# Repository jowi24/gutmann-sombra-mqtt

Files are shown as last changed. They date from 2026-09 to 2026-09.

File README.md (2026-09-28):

🇬🇧 **English** · 🇩🇪 [Deutsch](README.de.md)

# gutmann-sombra-mqtt

An ESP8266 board that connects a Gutmann Sombra range hood (cooker hood) to
home automation over Wi-Fi and MQTT, with Home Assistant auto-discovery.
The board sits in the cable between the hood electronics and the front
panel. It reads which front-panel LEDs are lit and can simulate key presses.
The original front panel keeps working as before.

- **Hardware:** KiCad 10 PCB, 80 × 55 mm, through-hole except the ESP-12E
  module, fabrication files included
- **Firmware:** PlatformIO / Arduino, MQTT with Home Assistant discovery,
  OTA updates, Wi-Fi setup portal

## Documentation

| Document | Contents |
|---|---|
| [How the circuit works](docs/CIRCUIT.md) | Beginner-friendly explanation of the hardware: the hood's key matrix, level shifters, power supply, firmware timing, troubleshooting |
| [Hardware design notes](kicad/DESIGN.md) | Part values, sourcing, layout decisions, bring-up findings |
| [Fabrication files](kicad/fab/FAB.md) | Gerber/drill files and PCB order parameters |
| [Operation, diagnostics and flashing](docs/OPERATIONS.md) | Setup, OTA and serial flashing, diagnostics |
| [Changelog](CHANGELOG.md) | Firmware versions |

All documents are also available in German (`*.de.md`).

## Status

- **Hardware:** PCB rev. 0.3, see the [schematic](kicad/schematic.pdf) and
  the [layout](kicad/board-layout.pdf). The fabricated rev. 0.2 boards work
  after a small modification at U3 (diodes + pull-downs, see
  [DESIGN.md](kicad/DESIGN.md)).
- **Firmware:** 0.0.10, PlatformIO, source in [`src/main.cpp`](src/main.cpp).

## Project layout

```
src/main.cpp          firmware
platformio.ini        build configuration (serial and OTA flashing)
docs/                 operation and circuit description
kicad/                schematic, PCB, custom footprint and 3D model
kicad/fab/            fabrication files
fritzing/             2017 perfboard version (reference only)
```

## Building and flashing the firmware

```bash
pio run -e nodemcuv2-ota -t upload
```

This flashes over Wi-Fi (OTA) to `hood-control.local`. For the first flash
or for recovery, use `-e nodemcuv2` via a USB-serial adapter on J2, with
jumper J5 set to FLASH. Details in [OPERATIONS.md](docs/OPERATIONS.md).

## MQTT

All topics live under the configured prefix (default `home/kitchen/hood`).
Home Assistant picks the device up automatically via MQTT discovery
(`homeassistant/…`).

| Topic | Values | Meaning |
|---|---|---|
| `ventilation/state`, `ventilation/set` | `0`–`4` | fan level, `0` = off |
| `light/state`, `light/set` | `true` / `false` | light |
| `timer/state`, `timer/set` | `true` / `false` | run-on timer |
| `maintenance/state` | `true` / `false` | "clean filter" indicator |
| `maintenance/set` | any | resets the filter indicator (6 s key press, only while it is on) |

Diagnostics:

- `diagnostics`: combined JSON status
- `$wifi_rssi`, `$uptime`, `$reset_reason`, `$firmware`, `$ip`, `$last_error`
- `events`: connection events buffered since the last MQTT contact
- `$online`: availability via MQTT last will

## Network

If the stored Wi-Fi network cannot be reached for 20 seconds, the firmware
starts the password-protected hotspot `HoodControl-Setup`. The setup portal
is at `http://192.168.4.1`. The device keeps trying the stored network in
parallel and shuts the hotspot down once the connection is stable.

The blue LED on the ESP module shows the state: fast blinking = connecting
to Wi-Fi, medium = connecting to MQTT, slow = hotspot active, a short flash
every 3 s = all good.

## Background

Blog post about the original 2017 perfboard version (German):
[Do-It-Yourself IoT Modul für die Dunstabzugshaube](https://joachim-wilke.de/blog/2017/12/27/do-it-yourself-iot-modul-fur-die-dunstabzugshaube/)

## License

Copyright (c) 2017–2026 Joachim Wilke. The firmware is open source (MIT). Hardware
and documentation are free for **non-commercial** use only; commercial use (e.g. selling boards, kits or products based on this project)
requires the author's permission.

- **Firmware** (`src/`, `platformio.ini`): [MIT](LICENSE)
- **Hardware and documentation** (`kicad/`, `fritzing/`, `docs/`, Markdown files):
  [CC BY-NC-SA 4.0](LICENSE-HARDWARE-DOCS)

Third-party libraries used by the firmware keep their own licenses.

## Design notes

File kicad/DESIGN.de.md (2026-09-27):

🇬🇧 [English](DESIGN.md) · 🇩🇪 **Deutsch**

# Hood-Control PCB – Redesign

Diese Doku beschreibt die Schematic in `hood-control.kicad_pro` /
`hood-control.kicad_sch`. Alle Werte sind aus der Fehlersuche an der
Lochraster-Version abgeleitet (siehe [CHANGELOG.de.md](../CHANGELOG.de.md) / Debugging-Session
vom 2026-09-03) sowie aus dem Blogartikel von 2017
("Do-It-Yourself IoT Modul für die Dunstabzugshaube").

Eine verständliche Erklärung, *wie* die Schaltung funktioniert, steht in
[`docs/CIRCUIT.de.md`](../docs/CIRCUIT.de.md).

**Bauweise: THT (bedrahtet).** Alle Widerstände/Kondensatoren bedrahtet,
alle ICs in DIP-Sockeln, Stecker als Pfostenleisten 2,54 mm, Taster als
6-mm-THT-Kurzhubtaster. Einziges SMD-Teil ist das ESP-12E-Modul selbst.
Der Spannungswandler ist **kein diskreter Schaltregler**, sondern ein
fertiges TPS63802-Buck-Boost-Modul (U4, 8 Bohrungen), flach aufgelötet oder auf
Stiftleisten gesteckt.

Blattformat der Schematic: **A5** (210 × 148 mm).

> **Namenskollision beachten:** Die Haubenelektronik benennt ihre eigenen
> Matrixleitungen ebenfalls J1–J8 (J1–J4 = Scan-Eingänge, J5–J6 = Tasten-
> Ausgänge, J7–J8 = LED-Ausgänge). Die Steckverbinder *dieser Platine*
> heißen ebenfalls J1–J6. Wo Verwechslungsgefahr besteht, ist im Folgenden
> "Haube-J5" bzw. "Board-J5" ausgeschrieben.

## Stückliste (BOM)

| Ref | Bauteil | Wert/Typ | Footprint | Zweck |
|---|---|---|---|---|
| U1 | ESP-12E/F | ESP8266 Modul (SMD) | `RF_Module:ESP-12E` | Microcontroller |
| U2 | CD4050BE / HEF4050BP / 74HC4050N | Hex-Buffer, **16-pol. DIP** | `Package_DIP:DIP-16_W7.62mm_Socket` | Pegelwandlung 5V→3,3V (Lesen: Scan-Bus, Haube-J7/J8) |
| U3 | **74HCT08** (z.B. SN74HCT08N) | Quad-AND, 14-pol. DIP | `Package_DIP:DIP-14_W7.62mm_Socket` | Pegelwandlung 3,3V→5V (Treiben: Haube-J5/J6) |
| U4 | **TPS63802-Buck-Boost-Modul** (eBay, PCB-Tronic24) | 1,5–5,5 V → 3,3 V, 2,7 A | `hood-control:TPS63802_Module_25.8x13.0mm` (projekteigene Bibliothek) | Stromversorgung (Ersatz für den 2017er Mini-Wandler) |
| R2 | 10 kΩ | 0207 bedrahtet | `Resistor_THT:R_Axial_DIN0207_L6.3mm_D2.5mm_P10.16mm_Horizontal` | Pull-up GPIO0 → 3,3V, über Board-J5 Pin 1 |
| R3 | 10 kΩ | 0207 bedrahtet | s.o. | Pull-down GPIO15 → GND |
| R4 | 10 kΩ | 0207 bedrahtet | s.o. | Pull-up CH_PD/EN → 3,3V |
| R5 | 2,4 kΩ | 0207 bedrahtet | s.o. | Pull-down auf den Scan-Bus (empirisch, siehe Blogartikel 2017) |
| R6 | 10 kΩ | 0207 bedrahtet | s.o. | Pull-up RST → 3,3V |
| R7, R8 | 10 kΩ | 0207 bedrahtet, stehend | `Resistor_THT:R_Axial_DIN0207_L6.3mm_D2.5mm_P2.54mm_Vertical` | Pull-down der U3-Eingänge (GPIO12/14), ab Rev. 0.3 |
| C1 | 470 µF / 10 V | Elko radial, D8/RM3,5 | `Capacitor_THT:CP_Radial_D8.0mm_P3.50mm` | Stützelko auf `VCC` nah am ESP – überbrückt die Regelzeit des Buck-Boost-Moduls |
| C8 | 1000 µF / 10 V | Elko radial, D10/RM5, 12,5 mm hoch (Reichelt `RD1A108M1012M128`) | `Capacitor_THT:CP_Radial_D10.0mm_P5.00mm` | Bulk-Kapazität auf `5V_IN` – puffert die strombegrenzte Haubenversorgung |
| C3–C6 | 100 nF | Keramik-Scheibe, RM5 | `Capacitor_THT:C_Disc_D5.0mm_W2.5mm_P5.00mm` | Abblockung: C3=U1(VCC), C4=U2(VCC 3,3V), C5=U3(5V_IN), C6=U4-Ausgang |
| C7 | 100 nF | Keramik-Scheibe, RM5 | `Capacitor_THT:C_Disc_D5.0mm_W2.5mm_P5.00mm` | RST-Kopplung FTDI-DTR → RST (Auto-Reset) |
| D1, D2 | 1N4148 | DO-35 | `Diode_THT:D_DO-35_SOD27_P7.62mm_Horizontal` | Entkopplung der LED-Leseleitungen Richtung Frontpanel |
| D3, D4 | 1N4148 | DO-35, stehend | `Diode_THT:D_DO-35_SOD27_P2.54mm_Vertical_AnodeUp` | Ausgangsdioden U3 → Tastenleitungen, ab Rev. 0.3 |
| SW1 | Taster 6 mm THT | – | `Button_Switch_THT:SW_PUSH_6mm` | Reset (RST → GND) |
| SW2 | Taster 6 mm THT | – | `Button_Switch_THT:SW_PUSH_6mm` | Flash-Mode (GPIO0 → GND) |
| J1 | Pfostenleiste 1×8, 2,54 mm | "Hoodcontrol" | `Connector_PinHeader_2.54mm:PinHeader_1x08_P2.54mm_Vertical` | Anschluss Haubenelektronik |
| J2 | Pfostenleiste 1×6, 2,54 mm | FTDI-Header | `Connector_PinHeader_2.54mm:PinHeader_1x06_P2.54mm_Vertical` | DTR, RXI, TXO, VCC, n.c., GND |
| J3 | Pfostenleiste 1×8, 2,54 mm | "Frontpanel" | `Connector_PinHeader_2.54mm:PinHeader_1x08_P2.54mm_Vertical` | Anschluss Frontpanel |
| J4 | Pfostenleiste 1×2, 2,54 mm | "Reset" | `Connector_PinHeader_2.54mm:PinHeader_1x02_P2.54mm_Vertical` | externer Reset-Taster (RST → GND) |
| J5 | Pfostenleiste 1×3, 2,54 mm | "Flash/Run" | `Connector_PinHeader_2.54mm:PinHeader_1x03_P2.54mm_Vertical` | Jumper: 1–2 = Run, 2–3 = Flash |
| J6 | Pfostenleiste 1×2, 2,54 mm | "PWR_IN" | `Connector_PinHeader_2.54mm:PinHeader_1x02_P2.54mm_Vertical` | Versorgung + Masse vom Service-Anschluss der Haube |

> **Achtung bei alten Notizen:** In CHANGELOG und Blogartikel ist mit "dem großen
> Elko" immer C1 gemeint. Seit der Umverteilung der Pufferung ist **C8** der große
> Bulk-Elko (seit 2026-09-07 **1000 µF** auf `5V_IN`) und **C1** der kleinere
> Stützelko (470 µF auf `VCC`).
>
> Die Nummerierung hat Lücken (kein C2, kein R1). C2 war der alte 4,7-µF-Elko
> der RST-Kopplung und wurde durch C7 ersetzt; der 2,5-kΩ-Pull-down heißt in
> der Schematic R5, nicht R1. Ein Re-Annotate würde nur neue Abweichungen
> zwischen Doku und Schematic erzeugen und unterbleibt bewusst.

### U4 – Spannungswandler (entschieden 2026-09-07)

Bestückt wird ein **TPS63802-Buck-Boost-Modul** (eBay, Händler PCB-Tronic24,
4,79 €).

| | |
|---|---|
| IC | TPS63802 (Texas Instruments) |
| Eingang | **1,5 – 5,5 V** (Anlauf ab 1,8 V) |
| Ausgang | 3,3 / 4,2 / 5 V per Lötbrücke, **2,7 A** bei 5 V → 3,3 V |
| Maße | **25,8 × 13,0** × 3,5 mm (nachgemessen 2026-09-11) |
| Anschlüsse | vier Eckkontakte mit je 2 Bohrungen im RM 2,54: VIN links oben, VOUT rechts oben, GND links und rechts unten |
| Eigene Beschaltung | 100 µF/16 V Eingangskondensator und Betriebs-LED bereits an Bord |

**Warum Buck-Boost und nicht Buck.** Die Haube liefert 4,9 V im Leerlauf. Jeder
gängige Buck braucht mindestens 4,5 – 6 V und fällt darunter aus der Regelung –
das ist der Brownout-Boot-Loop der Lochraster-Version. Ein Buck-Boost ab 1,5 V
hat diese Kante nicht: sackt der Eingang unter 3,3 V, regelt er einfach weiter.

**Was bei Reichelt geprüft wurde und ausscheidet** (Stand 2026-09-07):

| Artikel-Nr. | Vin min | Preis | |
|---|---|---|---|
| `TSRN 1-2433` | 4,6 V | 14,10 € | 0,3 V Reserve, dreifacher Preis |
| `TSR 1-2433` | 4,75 V | 6,85 € | zu knapp |
| `R-78E33-05` | 6 V | 3,55 € | zu hoch |
| `TSR 1-2433E` | 6 V | 3,99 € | zu hoch, lieferbar erst ab 2.11.2026 |

Auch die gesamte OKI-78SR-Familie scheidet aus (3,3-V-Variante 7–36 V).

> **Achtung beim Einbau:** Das Modul kommt **ab Werk auf 4,2 V** eingestellt.
> Der ESP8266 verträgt absolut maximal 3,6 V. Also erst die Lötbrücke auf
> **3V3** umsetzen, dann das Modul allein an 4,9 V hängen, den Ausgang messen –
> und erst danach einbauen.

#### Footprint (gezeichnet 2026-09-11)

Das Modul lag vor und wurde mit dem Messschieber vermessen. Die Fotomessung
lag quer richtig (Bohrungen bei ±2,54 und ±5,08 mm von der Mittellinie), beim
Reihenabstand daneben: es sind **22,86 mm = 9 × 2,54**, nicht ~23,5 mm. Damit
liegt das ganze Lochbild auf dem 2,54-Raster.

| | |
|---|---|
| Datei | `kicad/hood-control.pretty/TPS63802_Module_25.8x13.0mm.kicad_mod` |
| Bibliothek | `hood-control` (`fp-lib-table` im Projekt, `${KIPRJMOD}`) |
| Körper | 25,8 × 13,0 mm auf `F.SilkS`/`F.Fab`, Courtyard +0,25 mm |
| Bohrbild | x = ±11,43 mm, y = ±2,54 und ±5,08 mm → 8 Bohrungen |
| Pads | 1,7 mm rund, Bohrung 1,0 mm; Pad 1 rechteckig als Pin-1-Marke |
| Pin-Nummern | 1 = VIN, 2 = GND (4 ×), 3 = VOUT – passend zu den Pins des Symbols `Converter_DCDC:OKI-78SR-12_1.0-W36-C` |
| 3D-Modell | `kicad/3dmodels/TPS63802_Module_25.8x13.0mm.step` (erzeugt von `create_tps63802_module.py` in FreeCAD) |

Die vier Kontakte haben je zwei Bohrungen, die auf dem Modul selbst verbunden
sind. Im Footprint tragen sie deshalb dieselbe Pad-Nummer, und die Option
`duplicate_pad_numbers_are_jumpers` steht auf `yes`: KiCad weiß damit, dass
die Verbindung im Bauteil steckt und verlangt sie nicht auf der Platine.
Trotzdem sollten beim Routen **beide** Bohrungen eines Kontakts angebunden
werden – bei 2,7 A ist das kein Luxus.

Die ursprünglich geplante zusätzliche 2,54-Reihe VIN/GND/VOUT neben dem Modul
ist entfallen: das Modul liegt flach auf der Platine und deckt seinen Platz
vollständig ab, und zwischen C6 und TP1 bleibt neben dem Körper nicht einmal
ein Millimeter frei. Als Messpunkte dienen TP3 (5V) und TP4 (3V3).

Auf dem Bestückungsdruck steht innerhalb des Umrisses **„Loetbruecke auf
3V3!"** – die Warnung von oben als Aufdruck, sichtbar solange das Modul noch
nicht sitzt.

### Hinweis zu U3 (74HCT08)

In den installierten KiCad-Bibliotheken existiert kein eigenes 74HCT08-Symbol.
Verwendet wird deshalb das Symbol `74xx:74LS08` (**identische Pinbelegung**),
das Value-Feld ist aber auf `74HCT08` gesetzt, damit BOM und Bestückungsdruck
stimmen. **Bestückt werden muss ein HCT-Typ** – nur der HCT-Eingangspegel
(V_IH ≈ 2,0 V) lässt sich sicher aus 3,3 V ansteuern.

## Beschaffung

### Bezugsquellen

| Was | Wo |
|---|---|
| U4, TPS63802-Buck-Boost-Modul | eBay, Händler **PCB-Tronic24** (Cuxhaven), Artikel-Nr. 376238468668 – <https://www.ebay.de/itm/376238468668> – 4,79 € (ab 4 Stück 4,31 €) |
| alle übrigen Bauteile | reichelt.de, Artikelnummern unten |

Das TPS63802 gibt es auch bei AliExpress (diymore, 10,4 × 7,9 mm, 2,59 €), dort
kommen aber ~3 € Einfuhrgebühr je Artikel dazu und die Lieferzeit liegt bei
~10 Tagen. Das eBay-Angebot ist damit günstiger, schneller und hat Rückgaberecht.

### Reichelt-Artikelnummern

| Ref | Stk | Artikel-Nr. | Beschreibung |
|---|---|---|---|
| C3–C7 | 5 | `X7R-5 100N` | Vielschicht-Kerko 100 nF, 50/100 V, X7R ±10 %, RM 5,0 |
| C1 | 1 | `WL1C477M0811M` | Elko 470 µF/16 V, 105 °C, Low ESR, RM 3,5, 8 × 11,5 mm |
| C8 | 1 | `RD1A108M1012M128` | Elko 1000 µF/**10 V**, 105 °C, RM 5, D10 × **12,5 mm** |
| R2, R3, R4, R6 | 4 | `METALL 10,0K` | 10,0 kΩ, 0207, 0,6 W, 1 % |
| R5 | 1 | `METALL 2,40K` | 2,40 kΩ, 0207, 0,6 W, 1 % |
| D1, D2 | 2 | `1N 4148` | Schalt-Diode 100 V / 150 mA, DO-35 |
| SW1, SW2 | 2 | `DIP DTS-61K` | Kurzhubtaster 6 × 6 × 4,3 mm, Print |
| U2 | 1 | `CD 4050BE TEX` | CMOS Hex Non-Inverting Buffer, 3–18 V, DIP-16 |
| U3 | 1 | `74HCT 08` | AND-Gate, 4-fach, 4,5–5,5 V, DIP-14 |
| U2 (Fassung) | 1 | `GS 16` | IC-Sockel 16-polig, RM 7,62 |
| U3 (Fassung) | 1 | `GS 14` | IC-Sockel 14-polig, RM 7,62 |
| J2, J4, J5 | 1 | `ECON SL40G1` | Stiftleiste 1 × 40, gerade, 2,54 mm (11 Pins gebraucht) |
| J5 | 1 | `JUMPER 2,54 SW` | Kurzschlussbrücke RM 2,54 |
| Werkzeug | 1 | `ANMAS MG81000N` | Kopfbandlupe mit LED, 5 Linsen |

Seit Rev. 0.3 kommen D3/D4 (1N4148) und R7/R8 (10 kΩ) hinzu – die
Reserveteile der Bestellung unten decken sie ab.

**J1, J3 und J6 stehen bewusst nicht in der Liste** – die werden direkt
verdrahtet, dafür braucht es nur Litze (siehe „Platzierung").

Ein paar Hinweise zur Auswahl, damit sie nicht wieder verlorengeht:

* **`X7R-5 100N`, nicht `KERKO 100N`.** Letzterer ist zwar einen Cent billiger,
  aber Y5V mit −20/+80 % – die Kapazität bricht mit Temperatur und Spannung weg.
* **C8 in 10 V, nicht 16 V.** Alle 1000-µF-Typen mit 16 V bauen bei Reichelt
  mindestens 16 mm hoch und reißen damit das 14-mm-Limit. Die 10-V-Variante gibt
  es in D10 × 12,5 mm, und 10 V auf einer 4,9-V-Schiene ist doppelte Reserve.
* **R5 mit 2,40 kΩ.** Bis 2026-09-07 stand im Schaltplan 2,5 kΩ – kein Normwert,
  die E24-Reihe hat 2,4 k und 2,7 k. Für einen Pull-down auf dem Scan-Bus ist der
  Wert unkritisch (er stammt empirisch aus dem Blogartikel von 2017). Schaltplan
  und Board sind auf **2,4 kΩ** nachgezogen.
* **M2-Schrauben führt Reichelt nicht** – die Suche liefert nur M.2-SSD-Zubehör.

### Bestellt am 2026-09-07

| Artikel-Nr. | Stk | Anmerkung |
|---|---|---|
| `X7R-5 100N` | 10 | 5 gebraucht |
| `WL1C477M0811M` | 2 | 1 gebraucht |
| `RD1A108M1012M128` | 4 | 1 gebraucht |
| `METALL 10,0K` | 10 | 4 gebraucht |
| `METALL 2,40K` | 10 | 1 gebraucht |
| `1N 4148` | 5 | 2 gebraucht |
| `DIP DTS-61K` | 2 | 2 gebraucht, **kein Ersatz** |
| `GS 16` | 2 | 1 gebraucht |
| `GS 14` | 2 | 1 gebraucht |
| `CD 4050BE TEX` | 1 | Reserve, U2 ist vorhanden |
| `74HCT 08` | 1 | Reserve, U3 ist vorhanden |
| `ANMAS MG81000N` | 1 | Werkzeug |
| TPS63802-Modul (eBay) | 1 | |

Nicht mitbestellt, weil **vorhanden**: Stiftleiste 2,54 mm (für J2, J4, J5),
Kurzschlussbrücke für J5 und die vier M2-Schrauben. Die Bestellung ist damit
vollständig – es fehlt nichts mehr.

## GPIO-Zuordnung (aus src/main.cpp)

| GPIO | Funktion | Über welchen Levelshifter |
|---|---|---|
| GPIO13 | Scan-Eingang der Haube (Interrupt, RISING) | U2 (4050), Gatter C (Pin 7 → 6) |
| GPIO5  | LED-Status lesen (J1/1), Firmware `ledPin2` | U2 (4050), Gatter B (Pin 5 → 4) |
| GPIO4  | LED-Status lesen (J1/2), Firmware `ledPin1` | U2 (4050), Gatter A (Pin 3 → 2) |
| GPIO12 | Tastenemulation (J1/3), Firmware `buttonPin2` | U3 (HCT08), Gatter A (Pin 1+2 → 3) → D3 |
| GPIO14 | Tastenemulation (J1/4), Firmware `buttonPin1` | U3 (HCT08), Gatter B (Pin 4+5 → 6) → D4 |

| GPIO2  | Onboard-Status-LED (active LOW) | – (nur intern im ESP-12-Modul, No-Connect) |
| GPIO0  | Flash-Taster / WLAN-Config-Reset beim Boot | – (lokal, SW2 + R2 über Board-J5) |
| CH_PD  | Enable, muss beim Boot HIGH sein | – (lokal, R4) |
| GPIO15 | Boot-Strapping, muss beim Boot LOW sein | – (lokal, R3) |
| GPIO16 | unbenutzt (kein Deep-Sleep-Wakeup vorgesehen) | – |
| GPIO9/GPIO10 | **nicht verwenden** – bei ESP-12 intern für Flash-Zugriff (QIO) reserviert | – |

> **Kanalzuordnung (Inbetriebnahme 2026-09-24):** Sowohl die beiden
> LED-Kanäle als auch die beiden Tastenkanäle kommen gegenüber der
> Lochraster-Firmware vertauscht an – Lüfter 1 wurde als „Timer“ erkannt,
> „Licht an“ schaltete Stufe 2. Korrigiert in der Firmware durch Tausch von
> `ledPin1/2` und `buttonPin1/2`; die Hardware ist unverändert.

## Stromversorgung und Masse

Beide kommen **nicht** über das 8-polige Steuerkabel, sondern über den
separaten Service-Anschluss der Haubenelektronik (im Blogartikel Markierung
3 = Masse, 4 = Versorgung), abgegriffen mit einem gekürzten ISA-Bus-Slot:

* **ca. 4,8 V, belastbar mit ca. 500 mA** (experimentell mit Belastungs-
  widerstand bestimmt)
* Das RJ45-Kabel zwischen Haube und Frontpanel führt **keine Referenzmasse**.
  Für das Frontpanel allein ist das nicht nötig, für Messung und aktive
  Ansteuerung schon. Das Gehäuse als Bezugsmasse funktioniert nicht.

Daraus folgt für J1/J3: **dort liegen weder 5V_IN noch GND** – das ist
korrekt so und kein Versehen.

### Versorgungsnetze

* `5V_IN` → J6/1, U4/VIN, U3/VCC (74HCT08 läuft auf 5 V), C5, C8
* `VCC` (3,3 V) → U4/VOUT, U1, U2/VDD, R2, R4, R6, J2/4, C1, C3, C4, C6
* `GND` → J6/2, gemeinsame Masse
* Alle drei Netze tragen je ein `PWR_FLAG` (`#FLG01` auf GND, `#FLG02` auf
  5V_IN); VCC wird vom `power_out`-Pin des Wandlermoduls getrieben.

### Dimensionierung der Pufferung

Beim WiFi-Senden zieht der ESP kurzzeitig ~350 mA aus 3,3 V, was über den
Wandler ~270 mA aus 4,9 V bedeutet. Die Quelle liefert 500 mA – **der Strom
war also nie der Engpass.** Der Engpass war die *Untergrenze*: sackt die
Eingangsspannung unter die minimale Eingangsspannung eines Buck-Moduls
(4,5 – 6 V je nach Typ), fällt es aus der Regelung. Das ist der
Brownout-Boot-Loop aus der Lochraster-Version.

**Mit dem TPS63802 (1,5 – 5,5 V) gibt es diese Kante nicht mehr**, und die
Pufferung durfte deshalb am 2026-09-07 von 3300 µF auf **1000 µF** schrumpfen.
Der Kondensator überbrückt jetzt nur noch die Regelzeit der Haubenversorgung,
nicht mehr ein Dropout-Risiko. Nebeneffekt: C8 steht wieder aufrecht (12,5 mm
statt 35 mm liegend) und der 13,5 × 39 mm große Streifen im Layout ist frei.

Deshalb ist die Pufferung auf beide Seiten verteilt (entschieden 2026-09-06):

| Netz | Kondensatoren |
|---|---|
| `5V_IN` | C5 (100 nF) + **C8, 1000 µF/10 V** – puffert die 500-mA-Quelle |
| `VCC` | C3/C4/C6 (100 nF) + **C1, 470 µF/10 V** – überbrückt die ~100 µs Regelzeit |

Die große Kapazität gehört bewusst **nicht** auf den Ausgang: dort reichen
330–470 µF, und sehr große Werte können beim Einschalten die Strombegrenzung
des Buck-Moduls auslösen.

## Reset- und Flash-Beschaltung

| Netz | Bauteile |
|---|---|
| `/RST` | U1/1, R6 (Pull-up), C7 (Kopplung von FTDI-DTR), SW1, J4 |
| `Net-(U1-EN)` | U1/3, R4 (eigener Pull-up) |
| `/GPIO0` | U1/18, SW2, Board-J5 Pin 2 |
| `/FTDI_DTR` | J2/1, C7 |

**EN und RST haben bewusst getrennte Pull-ups.** Ein gemeinsamer Widerstand
würde beide Pins zu einem Netz verschmelzen: SW1 und J4 würden dann den Chip
abschalten statt zurückzusetzen, und ein späteres RC-Glied auf EN würde über
den kapazitiven Teiler mit C7 den Auto-Reset unbrauchbar machen.

### Auto-Reset über J2

esptool fährt beim Verbinden die Sequenz `DTR=0/RTS=1 → 100 ms → DTR=1/RTS=0`.
J2 führt nur **DTR** heraus (Pin 5 ist beim verwendeten FTDI-Adapter CTS, ein
Eingang des Adapters, und kann nichts treiben). Damit gilt:

* **Auto-Reset funktioniert** – die DTR-Flanke wird über C7 auf RST gekoppelt.
* **Auto-Flash funktioniert nicht** – GPIO0 wird nicht ferngesteuert.
* Nach dem Flashen bleibt der ESP im Bootloader, weil esptools `hard_reset`
  ausschließlich RTS schaltet. SW1 drücken (oder auf die DTR-Flanke beim
  Schließen des Ports hoffen).

Voller Auto-Flash würde einen Adapter mit RTS **und** das kreuzgekoppelte
NPN-Paar der NodeMCU-Schaltung erfordern. Bewusst nicht umgesetzt: seriell
geflasht wird nur beim Erstflash und zur Rettung, im Alltag läuft OTA
(`[env:nodemcuv2-ota]`).

### Jumper Board-J5 (Flash/Run)

| Stellung | Wirkung |
|---|---|
| **1–2 (Normalbetrieb)** | R2 zieht GPIO0 auf 3,3 V – der ESP bootet die Firmware |
| 2–3 | GPIO0 fest auf GND – der ESP bootet in den Flash-Mode |

Der Jumper steht im Normalbetrieb auf **1–2**. Der Pull-up R2 wirkt dadurch
nur bei gestecktem Jumper; ohne Jumper floatet GPIO0 und der Boot ist nicht
zuverlässig. Das ist bewusst so gewählt (ein Bauteil statt zwei, Flash-Mode
ohne Tasterakrobatik) – der Jumper muss dafür immer stecken.

## Unbenutzte Gatter (wichtig!)

CMOS- und HCT-Eingänge dürfen **nicht floaten** (Oszillation, Querstrom,
Störungen). Deshalb:

* U2 (4050): die drei unbenutzten Buffer D/E/F – **Eingänge (Pin 9, 11, 14)
  fest auf GND**, Ausgänge (Pin 10, 12, 15) offen mit No-Connect-Flag.
* U3 (74HCT08): die beiden unbenutzten Gatter C/D – **beide Eingänge je Gatter
  (Pin 9+10 bzw. 12+13) fest auf GND**, Ausgänge (Pin 8, 11) offen mit No-Connect.

## Steckerbelegung J1 / J3 (je 8-polig)

Im Original wurde ein altes Netzwerkkabel verwendet. Aderfarben nach **T568B**.
Die Platine klinkt sich in die vorhandene Verbindung Haube ↔ Frontpanel ein.

| Pin | Netz | J1 (Haube) | J3 (Frontpanel) | T568B |
|---|---|---|---|---|
| 1 | `LED_CH_2` | LED-Status Haube-J7 → U2/5 → GPIO5 | über D1 (Anode) auf dasselbe Netz | orange-weiß |
| 2 | `LED_CH_1` | LED-Status Haube-J8 → U2/3 → GPIO4 | über D2 (Anode) auf dasselbe Netz | orange |
| 3 | `BTN_CH_1` | Tastenemulation, von U3/3 über D3 getrieben | durchverbunden | grün-weiß |
| 4 | `BTN_CH_2` | Tastenemulation, von U3/6 über D4 getrieben | durchverbunden | blau |
| 5 | – | ↔ J3/5 | ↔ J1/5 | blau-weiß |
| 6 | – | ↔ J3/6 | ↔ J1/6 | grün |
| 7 | – | ↔ J3/7 | ↔ J1/7 | braun-weiß |
| 8 | `SCAN` | Scan-Bus → R5 (Pull-down) → U2/7 → GPIO13 | durchverbunden | braun |

Pin 5–7 sind reine Durchleitungen zwischen Haube und Frontpanel; die Platine
greift sie nicht ab. **Weder 5V noch GND liegen auf diesem Stecker**
(siehe "Stromversorgung und Masse").

D1/D2 (1N4148, Anode an J3, Kathode am jeweiligen LED-Netz) saßen schon auf
der Lochrasterplatine genau so auf den LED-Leitungen (per Fritzing-Datei
`fritzing/abzugshaube.fzz` bestätigt, 2026-09-24). Mit der Tastenemulation
haben sie nichts zu tun.

### Tastenemulation: U3 nur mit Ausgangsdioden (D3/D4) und Pull-downs (R7/R8)

Die Tastenleitungen sind Teil der Tastenmatrix zwischen Haube und Frontpanel.
Die Platine darf sie nur **hochziehen** (Taste drücken) oder **völlig in Ruhe
lassen** – nie auf LOW halten.

* **U3 direkt an J1/3+4 (Rev. 0.2) funktioniert nicht:** Der 74HCT08 hat
  Gegentaktausgänge und treibt die Leitung immer HIGH oder LOW; bei
  floatenden Eingängen (ESP-Boot) zufällig. Folge: Boot-Loop des ESP,
  Phantomtasten an der Haube (Stufe 3 + Filter = beide Kanäle in Scan-Zeile
  2), Haube reagiert nicht mehr.
* **Direkter Draht oder Serienwiderstand (1–2,4 kΩ) statt U3 funktioniert
  ebenfalls nicht:** Das Frontpanel glimmt, der ESP hängt sich auf Haubenstrom
  auf, mit Widerstand geht die Haube beim Start in einen Fehlercode. Solange
  die 3,3-V-Schiene beim Einschalten noch bei 0 V steht, klemmen die
  ESP-Schutzdioden die Leitungen; umgekehrt speisen die 5-V-Impulse in VCC
  zurück. (Die Lochrasterplatine hatte GPIO12/14 direkt verdrahtet und lief
  damit jahrelang – außerhalb der Spezifikation.)
* **Lösung (Rev. 0.3):** D3/D4 (1N4148) in Serie hinter U3-Pin 3 bzw. 6,
  Anode an U3, Kathode an BTN_CH. HIGH ≈ 4,3 V drückt, LOW sperrt die Diode.
  R7/R8 (10 kΩ) ziehen die U3-Eingänge nach GND, bis die Firmware läuft.
  Die Firmware treibt GPIO12/14 stets aktiv: LOW = loslassen, HIGH = drücken,
  schon am Anfang von `setup()` auf LOW.
* **Auf den gefertigten Rev.-0.2-Platinen** wird das nachgerüstet: am
  74HCT08 Pin 3 und 6 aus dem Sockel biegen, Diode vom gebogenen Pin (Anode)
  in die Sockelbuchse (Kathode) stecken, 10 kΩ auf der Unterseite zwischen
  Sockelpin 2↔7 und 4↔7.

Dass das Haubenlicht beim Einschalten angeht, ist ein Verhalten der Haube
selbst (tritt auch ohne Platine auf).

## Bekannte Fallstricke aus der Lochraster-Version (im Redesign vermieden)

1. **GPIO0 ohne Pull-up** war die Hauptursache für sporadische Bootfehler.
   → R2 eingeplant, wirkt über den Jumper Board-J5 in Stellung 1–2.
2. **GPIO12/14 direkt an den 5-V-Tastenleitungen** – außerhalb der
   ESP-Spezifikation. → U3 mit D3/D4 und R7/R8, siehe „Tastenemulation“.
   (Frühere Annahme, D1/D2 hätten die Tastenleitungen geschützt, war falsch:
   sie sitzen auf den LED-Leitungen.)
3. **Reset-Taster war ursprünglich an GPIO16 statt RST** verdrahtet –
   im Redesign SW1 direkt an RST/EXT_RST.
4. **Kein definierter Power-on-Reset** – Wandler-Anlaufverhalten konnte zu
   instabilem Boot führen. → Behoben durch den Buck-Boost-Wandler U4 (regelt
   ab 1,5 V) und die aufgeteilte Pufferung C8/C1. Ein zeitweise erwogener
   Supervisor-IC (U5, MCP130) wurde deshalb nicht eingebaut; die
   Inbetriebnahme 2026-09 lief ohne Brownout-Resets.
5. **Bulk-Elko zu klein/unklar dimensioniert und auf der falschen Seite**
   (Originalwert im Artikel: 800 µF, gemessen später 3,88 mF) → im Redesign
   aufgeteilt: C8 (1000 µF) auf `5V_IN`, C1 (470 µF) auf `VCC`.
   Siehe "Dimensionierung der Pufferung".
6. **RST-Auto-Reset-Kondensator:** jetzt C7, 100 nF Keramik (unpolarisiert).
   Der frühere 4,7-µF-Elko (C2) war doppelt falsch – zu große Zeitkonstante
   für den 100-ms-Reset-Impuls von esptool, und ein Koppelkondensator wird
   beidseitig belastet, taugt also nicht polarisiert. Zusammen mit R6 (10 kΩ)
   ergibt sich τ = 1 ms.

## Mechanik: Gehäuse und Platinenabmessungen

Vorgaben aus dem Gehäuse (Stand 2026-09-07):

| Größe | Wert |
|---|---|
| Maximale Platinenabmessung | **55 × 80 mm** |
| Befestigungsbohrungen | 4 Stück, Rastermaß **50 × 50 mm** (vertikal und horizontal gleich) |
| Sockel-Innendurchmesser (Gewinde) | 1,8 mm |
| Sockel-Außendurchmesser | 5,0 mm |
| Erste Bohrung von der Oberkante | 3,5 mm ab Bohrungsmitte (= 1 mm Rand vom Sockelrand zur Platinenkante) |

### Orientierung auf der Platine

Die Outline in KiCad liegt **quer**: `(0,0) → (80,0) → (80,55) → (0,55)`, die
80-mm-Kante läuft also entlang x. Das ist dieselbe Platine wie „55 × 80 hoch",
nur um 90° gedreht. Damit ergeben sich die Bohrungsmitten:

```
   x = 3,5 und 53,5 mm      (Langseite 80 mm, 1 mm Rand zum Sockel)
   y = 2,5 und 52,5 mm      (Schmalseite 55 mm, Sockel bündig zur Kante)
```

**Der 1-mm-Rand gilt nur an der Langseite** (bestätigt 2026-09-07). An der
Schmalseite liegt der Sockel bündig auf der Platinenkante:

| Richtung | Bohrungsmitte | Sockel (⌀5) | Rand zur Kante |
|---|---|---|---|
| Langseite (80 mm, x) | 3,5 / 53,5 | 1,0…6,0 bzw. 51,0…56,0 | **1 mm** |
| Schmalseite (55 mm, y) | 2,5 / 52,5 | 0…5 bzw. 50…55 | **0 mm, bündig** |

Das ist so gewollt und kein Fehler.

### Bauhöhe (Vorgabe 2026-09-07)

Die Innenhöhe des Gehäuses beträgt **max. 20 mm inklusive Platine und
Montagesockeln**. Als Praxiswert gilt: **14 mm Bauteilhöhe über der Platine
sind sicher, darüber wird es unsicher.**

| Bauteil | Höhe über PCB | |
|---|---|---|
| C8 1000 µF/10 V, D10 stehend | 12,5 mm | ok |
| U4, TPS63802-Modul flach aufgelötet | 3,5 mm | ok |
| U4 auf Stiftleisten | ~6–7 mm | ok |
| Gegenstecker (Dupont-Buchse) auf vertikaler Stiftleiste | ~14,7 mm | **grenzwertig** |
| C1 470 µF/10 V, D8 | ~11,5 mm | ok |
| D3/D4, R7/R8 stehend | ~9–11 mm | ok |
| U2/U3, DIP im Sockel | ~9 mm | ok |
| Stiftleiste 2,54 vertikal, ohne Gegenstecker | 8,5 mm | ok |
| Jumper-Shunt auf J5 | ~7,5 mm | ok |
| Scheibenkondensator 100 nF | 5–7 mm | ok |
| SW1/SW2 (6-mm-Taster) | ~5 mm | ok |
| U1 (ESP-12E) | ~3 mm | ok |
| Widerstände, Dioden liegend | 2,5 mm | ok |

Damit ist die Höhe ein **Auswahlkriterium für U4**: das Wandlermodul darf
inklusive Stiftleiste nicht über 14 mm bauen. Zusammen mit der schon
bekannten Anforderung (min. Vin ≤ 4,5 V, ≥ 500 mA, dreipolig im 2,54-Raster)
scheidet die gesamte OKI-78SR- und R-78E-Familie aus – deren minimale
Eingangsspannung liegt bei 4,75 V bzw. 7 V.

### Schrauben und Bohrungsdurchmesser (entschieden 2026-09-07)

| Größe | Wert |
|---|---|
| Schraube | **M2** |
| Kopfdurchmesser | **4,0 mm** |
| Platinenbohrung | **2,2 mm** |
| Footprint | `MountingHole:MountingHole_2.2mm_M2` |

Der Footprint ist ein reines `np_thru_hole` – Bohrung 2,2 mm, **kein Kupfer**,
kein Netz. Er bringt zwei Kreise mit, die den Freiraum dokumentieren:
⌀4,40 mm auf `Cmts.User` (Schraubenkopf) und ⌀4,90 mm als `F.CrtYd`
(Courtyard). Eine zusätzliche Sperrfläche ist deshalb nicht nötig – der
Courtyard hält Bauteile automatisch weg und wird von der DRC geprüft.

Der ⌀5-Sockel ist ein *bestückungsseitig irrelevantes* Maß: er sitzt unter der
Platine, und dort liegen bei dieser reinen THT-Bestückung nur Lötaugen. Auf der
Oberseite begrenzt der Schraubenkopf mit ⌀4 mm, und den deckt der ⌀4,9-Courtyard
mit 0,45 mm Reserve ab.

An der Schmalseite reicht die Bohrung von y = 1,4 bis 3,6 mm; es bleibt ein
1,4 mm breiter Steg zur Platinenkante stehen. Mit den früher eingesetzten
3,2 mm (M3) wären es nur 0,9 mm gewesen.

## Platzierung und Routing

Das alte Board (90 × 70 mm, Netznamen einer weit zurückliegenden Revision) war
nicht zu retten und wurde vollständig neu aufgebaut. Die Leiterplatte ist
inzwischen vollständig geroutet; auf **B.Cu** liegt die gefüllte
GND-Rückseitenfläche `GND_BACKPLANE` (0,6 mm Randabstand, 0,3 mm
Kupferabstand, thermische Anbindung mit 0,6 mm Speichenbreite).
Nach dem Füllen der Fläche wurden 22 konfliktfreie Signal- und
Versorgungssegmente von B.Cu auf F.Cu gelegt, darunter die direkten
J1↔J3-Verbindungen für `Net-(J1-Pin_5)` bis `Net-(J1-Pin_7)`. B.Cu bleibt
für unvermeidbare Durchleitungen und die GND-Fläche reserviert; weitere
Layerwechsel werden nicht blind erzwungen, wenn sie bestehende F.Cu-Netze
kreuzen würden.
Die redundanten GND-Leiterbahnen zwischen durchkontaktierten GND-Pads wurden
anschließend entfernt. Die einzige verbleibende F.Cu-GND-Verbindung ist die
notwendige Führung vom SMD-GND-Pad 15 von U1 zur GND-Durchkontaktierung; alle
anderen GND-Pads hängen direkt an `GND_BACKPLANE`.

Der dritte Platzierungsdurchgang (2026-09-11) war nötig, weil C8 durch die Wahl des TPS63802 von
3300 µF liegend auf 1000 µF stehend geschrumpft ist und U4 dafür von 82 auf
325 mm² gewachsen ist.

### Zwei Entscheidungen, die die Platzierung bestimmen

* **J1, J3 und J6 werden nicht gesteckt, sondern direkt verlötet.** Eine
  aufgesteckte Dupont-Buchse baut allein ~14,7 mm, mit Kabelbogen darüber real
  18–20 mm; das passt nicht unter den Deckel (Limit 14 mm). Die Pads der
  vertikalen Stiftleisten bleiben im Layout stehen, die Leisten werden nur
  nicht bestückt – die Adern gehen direkt in die Bohrungen. J2 (FTDI) und J4
  (Reset) bleiben steckbar, die werden ohnehin nur bei offenem Gehäuse benutzt.
* **U4 belegt 25,8 × 13,0 mm.** Seit 2026-09-11 steht dort der echte
  Footprint (hochkant, 270°: **VIN oben, VOUT unten**), der Platzhalter auf
  `Cmts.User` ist entfallen – siehe Abschnitt U4.

### Zonen

Stand Rev. 0.3 (2026-09-26), Blick auf die Bestückungsseite:

| Bereich | Inhalt |
|---|---|
| Links Mitte | **U1** (ESP-12E), Antenne an der linken Schmalseite mit Keep-out-Zone |
| Links oben | J2 (FTDI), C7, SW1 (Reset), J4, R3 |
| Links unten | R4, R6, R2, SW2 (Flash), J5, TP2 (GND), TP4 (3,3 V) |
| Oben Mitte | **U2** (4050), C4, TP5 (SCAN), TP6 (GND), C8 |
| Mitte | C3, C1, darunter **U4** (Wandlermodul) und C6 |
| Rechts oben | R5, **J3**, **J1**, D1, D2; Kabelbinder-Bohrungen H1/H2 |
| Rechts unten | J6, TP3 (5 V), TP1 (GND), D3/D4/R7/R8 stehend, **U3** (74HCT08), C5; H3/H4 |

Die Kabelführung an H1–H4 ist als Sperrfläche `Kabelmontage` bzw.
`Kabelmontage_1` für Footprints markiert.

Abstände der Abblockkondensatoren zu ihrem Versorgungspin: C3 → U1/8 = 3,4 mm,
C4 → U2/1 = 3,5 mm, C5 → U3/14 = 3,4 mm.

Mit dem echten Footprint (2026-09-11) sitzen die Anschlüsse fest: VIN auf
(60,10 | 62,64 / 43,22), VOUT auf (60,10 | 62,64 / 66,08), GND je zweimal auf
x 52,48 / 55,02 in beiden Reihen. **C8 steht damit 7,7 mm über dem
Wandlereingang** – für den 1000-µF-Puffer gut genug, zumal das Modul einen
eigenen 100-µF-Eingangskondensator mitbringt und C8 reiner Energiespeicher für
die Millisekundenskala ist.

Offen bleibt die **Ausgangsseite**: C6 (100 nF) liegt nach der Verschiebung
vom 2026-09-11 nur noch 3,6 mm von den VOUT-Pads entfernt und ist damit
erledigt; C1 (470 µF) sind es weiterhin 19,5 mm.
Das ist der angekündigte Nachzug der U4-Umgebung – er steht noch aus und
bleibt als Optimierungspunkt für eine spätere Platzierungsrevision bestehen.

Damit der 13,0 mm breite Körper überhaupt zwischen C6 und TP1 passt, sind am
2026-09-11 **C6 um 1,2 mm und TP2/TP4 um je 1,0 mm nach links** gerückt; C8s
Referenztext musste aus dem Modulumriss weichen. Danach: Courtyards frei,
Silk frei.

### Wie platziert wurde

Verankert von Hand: U1 (Antenne an der Kante), U2/U3, J1/J3 (Pin an Pin
gegenüber, damit die sechs Durchleitungen gerade Bahnen werden) und U4. Der
Rest per Skript, mit Kosten = Summe der **Pad-zu-Pad-Abstände** je Netz;
GND, VCC und 5V_IN sind ausgenommen, weil globale Netze kein Ortssignal geben.
Abblock- und Pufferkondensatoren hängen stattdessen mit hohem Gewicht an ihrem
Versorgungspin. Danach Verbesserungsdurchläufe bis zur Konvergenz.

### Prüfstand

```
kicad-cli sch erc  --severity-all            → 0 Verstöße
kicad-cli pcb drc  --schematic-parity
  → 0 Violations                    (Stand 2026-09-26, Rev. 0.3;
                                     4 Kabelmontage-Keepouts H1–H4 sind Ausnahmen)
  → schematic_parity: 8 Hinweise    (8 × „extra footprint“ für die Bohrungen
                                     MH1–MH4 / H1–H4 ohne Symbol – so gewollt)
  → 0 unconnected items
  → 185 Leiterbahnsegmente, 10 Vias; B.Cu-GND-Fläche gefüllt
  → engster Kupferabstand 0,200 mm, kleinste Bohrung 0,30 mm
```

Die genauen Positionen stehen in `hood-control.kicad_pcb`, eine Ansicht in
[`board-layout.pdf`](board-layout.pdf).

## Stand / nächste Schritte in KiCad

* Schematic ist vollständig verdrahtet, **ERC: 0 Fehler, 0 Warnungen**
  (auch mit `--severity-all`).
* **Jedes Bauteil hat einen Footprint.** Am 2026-09-06 korrigiert:
  R5 (hatte `Package_DIP:DIP-8_W7.62mm` – ein DIP-8-Gehäuse für einen
  zweipoligen Widerstand), J4/J5/J6 (hatten gar keinen), U4 (hatte den
  Murata-Landeplatz), sowie die Umverteilung C1/C8.
* Die ERC-Regel `footprint_filter` steht in den Projekteinstellungen auf
  `ignore`. Sie hätte den R5-Fehler gemeldet – Kandidat zum Wiedereinschalten.
* **Warnung zu den KiCad-MCP-Tools:** `move_schematic_component`,
  `delete_schematic_wire`, `add_schematic_component` und `add_schematic_wire`
  löschen beim Neuschreiben der Datei Junctions – auch an Stellen, die mit der
  Operation nichts zu tun haben. Zweimal reproduziert (30 → 23 bzw. 30 → 18
  Junctions), Folge waren jeweils ~14 ERC-Fehler durch stillschweigend
  getrennte Netze. Änderungen deshalb entweder in der GUI machen oder per
  Skript direkt an der Datei, und danach **immer** Junctions zählen und die
  Netzliste gegen den Vorstand diffen.
* **Board am 2026-09-07 neu aufgebaut** (siehe „Platzierung"): Outline
  80 × 55 mm, alle Bauteile platziert, MH1–MH4 als
  `MountingHole_2.2mm_M2`.
* Die tote Clearance-Ausnahme für U5 wurde aus `hood-control.kicad_dru`
  entfernt – U5 gibt es in der Schaltung nicht mehr.
* **U4-Modul ist da, vermessen und gezeichnet** (2026-09-11): Footprint in
  `hood-control.pretty`, im Board platziert.
* **Fertigungsdaten liegen in `kicad/fab/`**: sieben Gerber-Lagen
  (F.Cu, B.Cu, F/B.Mask, F/B.Silkscreen, Edge.Cuts), PTH- und NPTH-Bohrdatei,
  Gerber-Job-Datei und `hood-control-gerber.zip` als Upload-Paket. Erzeugung
  und Bestellparameter für PCBWay stehen in [`kicad/fab/FAB.de.md`](fab/FAB.de.md). Wichtig: die
  Fertigungsklasse **6/6 mil** ist Pflicht – der engste Kupferabstand ist mit
  0,200 mm minimal unter den 0,2032 mm, die 8/8 mil verlangen würde.

* **Spätere Platzierungsoptimierung:** Die Umgebung von U4 könnte noch
  verbessert werden – vor allem C1 und C6 könnten näher an die VOUT-Seite.
  Die Leiterplatte ist bereits geroutet; eine solche Revision würde danach
  einen erneuten Routing-/Layerbereinigungsdurchlauf erfordern.
* **Rev. 0.3 (2026-09-26):** D3/D4/R7/R8 stehend (RM 2,54) in der Reihe über
  U3, außerhalb der Sperrfläche `Kabelmontage_1`. U4 ist jetzt mit seinem
  Symbol verknüpft; dadurch steht `duplicate_pad_numbers_are_jumpers` auf
  `no` – unkritisch, alle 8 U4-Bohrungen sind auf der Platine verbunden.
* DRC-Ausnahmen für H1–H4 (Kabelbinder-Bohrungen in den Sperrflächen) sind
  in `hood-control.kicad_pro` hinterlegt.

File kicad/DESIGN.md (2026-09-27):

🇬🇧 **English** · 🇩🇪 [Deutsch](DESIGN.de.md)

# Hood-Control PCB – Redesign

This document describes the schematic in `hood-control.kicad_pro` /
`hood-control.kicad_sch`. All values are derived from debugging the
perfboard version (see [CHANGELOG.md](../CHANGELOG.md) / debugging session
of 2026-09-03) and from the 2017 blog post
("Do-It-Yourself IoT Modul für die Dunstabzugshaube").

For a beginner-friendly explanation of *how* the circuit works, see
[`docs/CIRCUIT.md`](../docs/CIRCUIT.md).

**Construction: THT (through-hole).** All resistors/capacitors are leaded,
all ICs sit in DIP sockets, connectors are 2.54 mm pin headers, buttons are
6 mm THT tactile switches. The only SMD part is the ESP-12E module itself.
The voltage converter is **not a discrete switching regulator** but a
ready-made TPS63802 buck-boost module (U4, 8 holes), soldered flat or
plugged onto pin headers.

Schematic sheet size: **A5** (210 × 148 mm).

> **Mind the name clash:** the hood electronics names its own matrix lines
> J1–J8 as well (J1–J4 = scan inputs, J5–J6 = key outputs, J7–J8 = LED
> outputs). The connectors *of this board* are also called J1–J6. Where
> there is a risk of confusion, "hood-J5" or "board-J5" is spelled out.

## Bill of materials (BOM)

| Ref | Part | Value/type | Footprint | Purpose |
|---|---|---|---|---|
| U1 | ESP-12E/F | ESP8266 module (SMD) | `RF_Module:ESP-12E` | microcontroller |
| U2 | CD4050BE / HEF4050BP / 74HC4050N | hex buffer, **16-pin DIP** | `Package_DIP:DIP-16_W7.62mm_Socket` | level shifting 5 V→3.3 V (reading: scan bus, hood-J7/J8) |
| U3 | **74HCT08** (e.g. SN74HCT08N) | quad AND, 14-pin DIP | `Package_DIP:DIP-14_W7.62mm_Socket` | level shifting 3.3 V→5 V (driving: hood-J5/J6) |
| U4 | **TPS63802 buck-boost module** (eBay, PCB-Tronic24) | 1.5–5.5 V → 3.3 V, 2.7 A | `hood-control:TPS63802_Module_25.8x13.0mm` (project library) | power supply (replaces the 2017 mini converter) |
| R2 | 10 kΩ | 0207 leaded | `Resistor_THT:R_Axial_DIN0207_L6.3mm_D2.5mm_P10.16mm_Horizontal` | pull-up GPIO0 → 3.3 V, via board-J5 pin 1 |
| R3 | 10 kΩ | 0207 leaded | same | pull-down GPIO15 → GND |
| R4 | 10 kΩ | 0207 leaded | same | pull-up CH_PD/EN → 3.3 V |
| R5 | 2.4 kΩ | 0207 leaded | same | pull-down on the scan bus (empirical, see 2017 blog post) |
| R6 | 10 kΩ | 0207 leaded | same | pull-up RST → 3.3 V |
| R7, R8 | 10 kΩ | 0207 leaded, upright | `Resistor_THT:R_Axial_DIN0207_L6.3mm_D2.5mm_P2.54mm_Vertical` | pull-down of U3 inputs (GPIO12/14), since rev. 0.3 |
| C1 | 470 µF / 10 V | radial electrolytic, D8/P3.5 | `Capacitor_THT:CP_Radial_D8.0mm_P3.50mm` | support cap on `VCC` near the ESP – bridges the response time of the buck-boost module |
| C8 | 1000 µF / 10 V | radial electrolytic, D10/P5, 12.5 mm tall (Reichelt `RD1A108M1012M128`) | `Capacitor_THT:CP_Radial_D10.0mm_P5.00mm` | bulk capacitance on `5V_IN` – buffers the current-limited hood supply |
| C3–C6 | 100 nF | ceramic disc, P5 | `Capacitor_THT:C_Disc_D5.0mm_W2.5mm_P5.00mm` | decoupling: C3=U1 (VCC), C4=U2 (VCC 3.3 V), C5=U3 (5V_IN), C6=U4 output |
| C7 | 100 nF | ceramic disc, P5 | `Capacitor_THT:C_Disc_D5.0mm_W2.5mm_P5.00mm` | RST coupling FTDI-DTR → RST (auto-reset) |
| D1, D2 | 1N4148 | DO-35 | `Diode_THT:D_DO-35_SOD27_P7.62mm_Horizontal` | decoupling of the LED read lines towards the front panel |
| D3, D4 | 1N4148 | DO-35, upright | `Diode_THT:D_DO-35_SOD27_P2.54mm_Vertical_AnodeUp` | U3 output diodes → key lines, since rev. 0.3 |
| SW1 | 6 mm THT button | – | `Button_Switch_THT:SW_PUSH_6mm` | reset (RST → GND) |
| SW2 | 6 mm THT button | – | `Button_Switch_THT:SW_PUSH_6mm` | flash mode (GPIO0 → GND) |
| J1 | pin header 1×8, 2.54 mm | "Hoodcontrol" | `Connector_PinHeader_2.54mm:PinHeader_1x08_P2.54mm_Vertical` | connection to hood electronics |
| J2 | pin header 1×6, 2.54 mm | FTDI header | `Connector_PinHeader_2.54mm:PinHeader_1x06_P2.54mm_Vertical` | DTR, RXI, TXO, VCC, n.c., GND |
| J3 | pin header 1×8, 2.54 mm | "Frontpanel" | `Connector_PinHeader_2.54mm:PinHeader_1x08_P2.54mm_Vertical` | connection to front panel |
| J4 | pin header 1×2, 2.54 mm | "Reset" | `Connector_PinHeader_2.54mm:PinHeader_1x02_P2.54mm_Vertical` | external reset button (RST → GND) |
| J5 | pin header 1×3, 2.54 mm | "Flash/Run" | `Connector_PinHeader_2.54mm:PinHeader_1x03_P2.54mm_Vertical` | jumper: 1–2 = run, 2–3 = flash |
| J6 | pin header 1×2, 2.54 mm | "PWR_IN" | `Connector_PinHeader_2.54mm:PinHeader_1x02_P2.54mm_Vertical` | supply + ground from the hood's service connector |

> **Beware of old notes:** in the changelog and the blog post, "the big
> electrolytic" always means C1. Since the buffering was redistributed,
> **C8** is the large bulk capacitor (since 2026-09-07 **1000 µF** on
> `5V_IN`) and **C1** the smaller support capacitor (470 µF on `VCC`).
>
> The numbering has gaps (no C2, no R1). C2 was the old 4.7 µF electrolytic
> for RST coupling and was replaced by C7; the 2.5 kΩ pull-down is called R5
> in the schematic, not R1. A re-annotation would only create new mismatches
> between documentation and schematic and is deliberately not done.

### U4 – voltage converter (decided 2026-09-07)

A **TPS63802 buck-boost module** is fitted (eBay, seller PCB-Tronic24,
€4.79).

| | |
|---|---|
| IC | TPS63802 (Texas Instruments) |
| Input | **1.5 – 5.5 V** (start-up from 1.8 V) |
| Output | 3.3 / 4.2 / 5 V via solder bridge, **2.7 A** at 5 V → 3.3 V |
| Dimensions | **25.8 × 13.0** × 3.5 mm (measured 2026-09-11) |
| Connections | four corner contacts with 2 holes each on 2.54 mm pitch: VIN top left, VOUT top right, GND bottom left and right |
| On-board parts | 100 µF/16 V input capacitor and power LED already on the module |

**Why buck-boost and not buck.** The hood supplies 4.9 V at no load. Every
common buck needs at least 4.5 – 6 V and drops out of regulation below that
– that is the brownout boot loop of the perfboard version. A buck-boost from
1.5 V doesn't have this edge: if the input sags below 3.3 V, it simply keeps
regulating.

**What was checked at Reichelt and rejected** (as of 2026-09-07):

| Part no. | Vin min | Price | |
|---|---|---|---|
| `TSRN 1-2433` | 4.6 V | €14.10 | 0.3 V margin, three times the price |
| `TSR 1-2433` | 4.75 V | €6.85 | too tight |
| `R-78E33-05` | 6 V | €3.55 | too high |
| `TSR 1-2433E` | 6 V | €3.99 | too high, available only from 2026-11-02 |

The whole OKI-78SR family is ruled out as well (3.3 V variant 7–36 V).

> **Caution when fitting:** the module ships **set to 4.2 V**. The ESP8266
> tolerates an absolute maximum of 3.6 V. So first move the solder bridge to
> **3V3**, then connect the module alone to 4.9 V, measure the output – and
> only then fit it.

#### Footprint (drawn 2026-09-11)

The module was at hand and measured with calipers. The photo-based estimate
was right across (holes at ±2.54 and ±5.08 mm from the centre line) but off
for the row spacing: it is **22.86 mm = 9 × 2.54**, not ~23.5 mm. So the
whole hole pattern sits on the 2.54 mm grid.

| | |
|---|---|
| File | `kicad/hood-control.pretty/TPS63802_Module_25.8x13.0mm.kicad_mod` |
| Library | `hood-control` (`fp-lib-table` in the project, `${KIPRJMOD}`) |
| Body | 25.8 × 13.0 mm on `F.SilkS`/`F.Fab`, courtyard +0.25 mm |
| Hole pattern | x = ±11.43 mm, y = ±2.54 and ±5.08 mm → 8 holes |
| Pads | 1.7 mm round, 1.0 mm drill; pad 1 rectangular as pin-1 marker |
| Pin numbers | 1 = VIN, 2 = GND (4 ×), 3 = VOUT – matching the pins of symbol `Converter_DCDC:OKI-78SR-12_1.0-W36-C` |
| 3D model | `kicad/3dmodels/TPS63802_Module_25.8x13.0mm.step` (generated by `create_tps63802_module.py` in FreeCAD) |

Each of the four contacts has two holes that are connected on the module
itself. In the footprint they therefore share the same pad number, and the
option `duplicate_pad_numbers_are_jumpers` is set to `yes`: KiCad then knows
the connection is inside the part and doesn't require it on the board.
Still, **both** holes of a contact should be connected when routing – at
2.7 A that is no luxury.

The originally planned extra 2.54 mm row VIN/GND/VOUT next to the module was
dropped: the module lies flat on the board and covers its area completely,
and between C6 and TP1 there is not even a millimetre left next to the body.
TP3 (5V) and TP4 (3V3) serve as test points.

The silkscreen inside the outline reads **"Loetbruecke auf 3V3!"** ("solder
bridge to 3V3!") – the warning above as a print, visible while the module is
not yet fitted.

### Note on U3 (74HCT08)

The installed KiCad libraries have no dedicated 74HCT08 symbol. The symbol
`74xx:74LS08` (**identical pinout**) is used instead, but the value field is
set to `74HCT08` so BOM and silkscreen are correct. **An HCT type must be
fitted** – only the HCT input threshold (V_IH ≈ 2.0 V) can be driven safely
from 3.3 V.

## Sourcing

### Suppliers

| What | Where |
|---|---|
| U4, TPS63802 buck-boost module | eBay, seller **PCB-Tronic24** (Cuxhaven), item no. 376238468668 – <https://www.ebay.de/itm/376238468668> – €4.79 (€4.31 from 4 pcs) |
| all other parts | reichelt.de, part numbers below |

The TPS63802 is also available on AliExpress (diymore, 10.4 × 7.9 mm,
€2.59), but ~€3 import fee per item is added there and delivery takes ~10
days. The eBay offer is therefore cheaper, faster and returnable.

### Reichelt part numbers

| Ref | Qty | Part no. | Description |
|---|---|---|---|
| C3–C7 | 5 | `X7R-5 100N` | multilayer ceramic 100 nF, 50/100 V, X7R ±10 %, P5.0 |
| C1 | 1 | `WL1C477M0811M` | electrolytic 470 µF/16 V, 105 °C, low ESR, P3.5, 8 × 11.5 mm |
| C8 | 1 | `RD1A108M1012M128` | electrolytic 1000 µF/**10 V**, 105 °C, P5, D10 × **12.5 mm** |
| R2, R3, R4, R6 | 4 | `METALL 10,0K` | 10.0 kΩ, 0207, 0.6 W, 1 % |
| R5 | 1 | `METALL 2,40K` | 2.40 kΩ, 0207, 0.6 W, 1 % |
| D1, D2 | 2 | `1N 4148` | switching diode 100 V / 150 mA, DO-35 |
| SW1, SW2 | 2 | `DIP DTS-61K` | tactile switch 6 × 6 × 4.3 mm, PCB |
| U2 | 1 | `CD 4050BE TEX` | CMOS hex non-inverting buffer, 3–18 V, DIP-16 |
| U3 | 1 | `74HCT 08` | AND gate, quad, 4.5–5.5 V, DIP-14 |
| U2 (socket) | 1 | `GS 16` | IC socket 16-pin, 7.62 mm |
| U3 (socket) | 1 | `GS 14` | IC socket 14-pin, 7.62 mm |
| J2, J4, J5 | 1 | `ECON SL40G1` | pin header 1 × 40, straight, 2.54 mm (11 pins needed) |
| J5 | 1 | `JUMPER 2,54 SW` | jumper, 2.54 mm pitch |
| tool | 1 | `ANMAS MG81000N` | head-band magnifier with LED, 5 lenses |

Since rev. 0.3, D3/D4 (1N4148) and R7/R8 (10 kΩ) are needed in addition –
the spare parts of the order above cover them.

**J1, J3 and J6 are deliberately not in the list** – they are wired
directly, which only needs stranded wire (see "Placement").

A few notes on the selection so they don't get lost again:

* **`X7R-5 100N`, not `KERKO 100N`.** The latter is a cent cheaper but Y5V
  with −20/+80 % – the capacitance collapses with temperature and voltage.
* **C8 rated 10 V, not 16 V.** All 1000 µF types rated 16 V at Reichelt are
  at least 16 mm tall and break the 14 mm limit. The 10 V variant comes in
  D10 × 12.5 mm, and 10 V on a 4.9 V rail is double margin.
* **R5 at 2.40 kΩ.** Until 2026-09-07 the schematic said 2.5 kΩ – not a
  standard value, the E24 series has 2.4 k and 2.7 k. For a pull-down on the
  scan bus the value is uncritical (it comes empirically from the 2017 blog
  post). Schematic and board are updated to **2.4 kΩ**.
* **Reichelt doesn't carry M2 screws** – the search only returns M.2 SSD
  accessories.

### Ordered on 2026-09-07

| Part no. | Qty | Note |
|---|---|---|
| `X7R-5 100N` | 10 | 5 needed |
| `WL1C477M0811M` | 2 | 1 needed |
| `RD1A108M1012M128` | 4 | 1 needed |
| `METALL 10,0K` | 10 | 4 needed |
| `METALL 2,40K` | 10 | 1 needed |
| `1N 4148` | 5 | 2 needed |
| `DIP DTS-61K` | 2 | 2 needed, **no spare** |
| `GS 16` | 2 | 1 needed |
| `GS 14` | 2 | 1 needed |
| `CD 4050BE TEX` | 1 | spare, U2 on hand |
| `74HCT 08` | 1 | spare, U3 on hand |
| `ANMAS MG81000N` | 1 | tool |
| TPS63802 module (eBay) | 1 | |

Not ordered because **on hand**: 2.54 mm pin header (for J2, J4, J5),
jumper for J5 and the four M2 screws. The order is thus complete – nothing
is missing.

## GPIO assignment (from src/main.cpp)

| GPIO | Function | Via which level shifter |
|---|---|---|
| GPIO13 | hood scan input (interrupt, RISING) | U2 (4050), gate C (pin 7 → 6) |
| GPIO5  | read LED state (J1/1), firmware `ledPin2` | U2 (4050), gate B (pin 5 → 4) |
| GPIO4  | read LED state (J1/2), firmware `ledPin1` | U2 (4050), gate A (pin 3 → 2) |
| GPIO12 | key emulation (J1/3), firmware `buttonPin2` | U3 (HCT08), gate A (pins 1+2 → 3) → D3 |
| GPIO14 | key emulation (J1/4), firmware `buttonPin1` | U3 (HCT08), gate B (pins 4+5 → 6) → D4 |
| GPIO2  | on-board status LED (active LOW) | – (internal to the ESP-12 module, no-connect) |
| GPIO0  | flash button / Wi-Fi config reset at boot | – (local, SW2 + R2 via board-J5) |
| CH_PD  | enable, must be HIGH at boot | – (local, R4) |
| GPIO15 | boot strapping, must be LOW at boot | – (local, R3) |
| GPIO16 | unused (no deep-sleep wake-up planned) | – |
| GPIO9/GPIO10 | **do not use** – reserved on the ESP-12 for flash access (QIO) | – |

> **Channel mapping (bring-up 2026-09-24):** both the two LED channels and
> the two key channels arrive swapped compared to the perfboard firmware –
> fan 1 was detected as "timer", "light on" switched fan level 2. Corrected
> in the firmware by swapping `ledPin1/2` and `buttonPin1/2`; the hardware
> is unchanged.

## Power and ground

Neither comes through the 8-wire control cable, but through the separate
service connector of the hood electronics (marked 3 = ground, 4 = supply in
the blog post), tapped with a shortened ISA bus slot:

* **about 4.8 V, able to supply about 500 mA** (determined experimentally
  with a load resistor)
* The RJ45 cable between hood and front panel carries **no reference
  ground**. The front panel alone doesn't need it, measuring and actively
  driving do. Using the enclosure as ground reference does not work.

It follows for J1/J3: **neither 5V_IN nor GND is on these connectors** –
that is correct and not an oversight.

### Supply nets

* `5V_IN` → J6/1, U4/VIN, U3/VCC (74HCT08 runs on 5 V), C5, C8
* `VCC` (3.3 V) → U4/VOUT, U1, U2/VDD, R2, R4, R6, J2/4, C1, C3, C4, C6
* `GND` → J6/2, common ground
* Each net carries a `PWR_FLAG` (`#FLG01` on GND, `#FLG02` on 5V_IN); VCC is
  driven by the `power_out` pin of the converter module.

### Sizing the buffering

When transmitting over Wi-Fi, the ESP briefly draws ~350 mA from 3.3 V,
which means ~270 mA from 4.9 V through the converter. The source delivers
500 mA – **so current was never the bottleneck.** The bottleneck was the
*lower limit*: if the input voltage sags below the minimum input voltage of
a buck module (4.5 – 6 V depending on type), it drops out of regulation.
That is the brownout boot loop of the perfboard version.

**With the TPS63802 (1.5 – 5.5 V) this edge no longer exists**, so the
buffering was allowed to shrink from 3300 µF to **1000 µF** on 2026-09-07.
The capacitor now only bridges the response time of the hood supply, no
longer a dropout risk. Side effect: C8 stands upright again (12.5 mm instead
of 35 mm lying down) and the 13.5 × 39 mm strip in the layout is free.

The buffering is therefore split across both sides (decided 2026-09-06):

| Net | Capacitors |
|---|---|
| `5V_IN` | C5 (100 nF) + **C8, 1000 µF/10 V** – buffers the 500 mA source |
| `VCC` | C3/C4/C6 (100 nF) + **C1, 470 µF/10 V** – bridges the ~100 µs response time |

The large capacitance deliberately does **not** go on the output: 330–470 µF
is enough there, and very large values can trip the converter's current
limit at power-up.

## Reset and flash circuitry

| Net | Parts |
|---|---|
| `/RST` | U1/1, R6 (pull-up), C7 (coupling from FTDI-DTR), SW1, J4 |
| `Net-(U1-EN)` | U1/3, R4 (own pull-up) |
| `/GPIO0` | U1/18, SW2, board-J5 pin 2 |
| `/FTDI_DTR` | J2/1, C7 |

**EN and RST deliberately have separate pull-ups.** A shared resistor would
merge both pins into one net: SW1 and J4 would then switch the chip off
instead of resetting it, and a later RC network on EN would render the
auto-reset useless through the capacitive divider with C7.

### Auto-reset via J2

On connecting, esptool runs the sequence `DTR=0/RTS=1 → 100 ms → DTR=1/RTS=0`.
J2 only brings out **DTR** (pin 5 is CTS on the adapter used, an input of
the adapter, and can't drive anything). Therefore:

* **Auto-reset works** – the DTR edge is coupled to RST via C7.
* **Auto-flash does not work** – GPIO0 is not remote-controlled.
* After flashing, the ESP stays in the bootloader because esptool's
  `hard_reset` only toggles RTS. Press SW1 (or hope for the DTR edge when
  the port closes).

Full auto-flash would require an adapter with RTS **and** the cross-coupled
NPN pair of the NodeMCU circuit. Deliberately not implemented: serial
flashing is only used for the first flash and for recovery; day to day OTA
is used (`[env:nodemcuv2-ota]`).

### Board-J5 jumper (flash/run)

| Position | Effect |
|---|---|
| **1–2 (normal operation)** | R2 pulls GPIO0 to 3.3 V – the ESP boots the firmware |
| 2–3 | GPIO0 tied to GND – the ESP boots into flash mode |

In normal operation the jumper is on **1–2**. The pull-up R2 therefore only
acts when the jumper is fitted; without the jumper GPIO0 floats and boot is
unreliable. That is a deliberate choice (one part instead of two, flash mode
without button acrobatics) – the jumper must always be fitted.

## Unused gates (important!)

CMOS and HCT inputs must **not float** (oscillation, shoot-through current,
noise). Therefore:

* U2 (4050): the three unused buffers D/E/F – **inputs (pins 9, 11, 14) tied
  to GND**, outputs (pins 10, 12, 15) open with no-connect flag.
* U3 (74HCT08): the two unused gates C/D – **both inputs of each gate
  (pins 9+10 and 12+13) tied to GND**, outputs (pins 8, 11) open with
  no-connect.

## J1 / J3 pinout (8 pins each)

The original used an old network cable. Wire colours per **T568B**. The
board taps into the existing hood ↔ front panel connection.

| Pin | Net | J1 (hood) | J3 (front panel) | T568B |
|---|---|---|---|---|
| 1 | `LED_CH_2` | LED state hood-J7 → U2/5 → GPIO5 | via D1 (anode) onto the same net | orange-white |
| 2 | `LED_CH_1` | LED state hood-J8 → U2/3 → GPIO4 | via D2 (anode) onto the same net | orange |
| 3 | `BTN_CH_1` | key emulation, driven by U3/3 via D3 | connected through | green-white |
| 4 | `BTN_CH_2` | key emulation, driven by U3/6 via D4 | connected through | blue |
| 5 | – | ↔ J3/5 | ↔ J1/5 | blue-white |
| 6 | – | ↔ J3/6 | ↔ J1/6 | green |
| 7 | – | ↔ J3/7 | ↔ J1/7 | brown-white |
| 8 | `SCAN` | scan bus → R5 (pull-down) → U2/7 → GPIO13 | connected through | brown |

Pins 5–7 are pure pass-throughs between hood and front panel; the board does
not tap them. **Neither 5V nor GND is on this connector** (see "Power and
ground").

D1/D2 (1N4148, anode at J3, cathode at the respective LED net) already sat
exactly like this on the LED lines of the perfboard version (confirmed from
the Fritzing file `fritzing/abzugshaube.fzz`, 2026-09-24). They have nothing
to do with the key emulation.

### Key emulation: U3 only with output diodes (D3/D4) and pull-downs (R7/R8)

The key lines are part of the key matrix between hood and front panel. The
board may only **pull them up** (press a key) or **leave them completely
alone** – never hold them LOW.

* **U3 directly on J1/3+4 (rev. 0.2) does not work:** the 74HCT08 has
  push-pull outputs and always drives the line HIGH or LOW; with floating
  inputs (ESP boot) randomly. Result: ESP boot loop, phantom keys on the
  hood (fan level 3 + filter = both channels in scan row 2), hood stops
  responding.
* **A direct wire or series resistor (1–2.4 kΩ) instead of U3 doesn't work
  either:** the front panel glows faintly, the ESP hangs on hood power, with
  a resistor the hood goes into an error code at start-up. While the 3.3 V
  rail is still at 0 V at power-up, the ESP protection diodes clamp the
  lines; conversely the 5 V pulses feed back into VCC. (The perfboard had
  GPIO12/14 wired directly and ran that way for years – outside the
  specification.)
* **Solution (rev. 0.3):** D3/D4 (1N4148) in series after U3 pins 3 and 6,
  anode at U3, cathode at BTN_CH. HIGH ≈ 4.3 V presses, LOW blocks the
  diode. R7/R8 (10 kΩ) pull the U3 inputs to GND until the firmware runs.
  The firmware always drives GPIO12/14 actively: LOW = release, HIGH =
  press, set LOW right at the start of `setup()`.
* **On the fabricated rev. 0.2 boards** this is retrofitted: bend pins 3
  and 6 of the 74HCT08 out of the socket, insert a diode from the bent pin
  (anode) into the socket contact (cathode), and solder 10 kΩ on the bottom
  side between socket pins 2↔7 and 4↔7.

The hood light turning on at power-up is behaviour of the hood itself (it
also happens without the board).

## Known pitfalls of the perfboard version (avoided in the redesign)

1. **GPIO0 without pull-up** was the main cause of sporadic boot failures.
   → R2 added, active via the board-J5 jumper in position 1–2.
2. **GPIO12/14 directly on the 5 V key lines** – outside the ESP
   specification. → U3 with D3/D4 and R7/R8, see "Key emulation".
   (The earlier assumption that D1/D2 protected the key lines was wrong:
   they sit on the LED lines.)
3. **The reset button was originally wired to GPIO16 instead of RST** – in
   the redesign SW1 goes directly to RST/EXT_RST.
4. **No defined power-on reset** – converter start-up behaviour could lead
   to unstable boot. → Solved by the buck-boost converter U4 (regulates from
   1.5 V) and the split buffering C8/C1. A supervisor IC (U5, MCP130) that
   was considered for a while was therefore not fitted; bring-up in 2026-09
   ran without brownout resets.
5. **Bulk capacitor too small / unclearly sized and on the wrong side**
   (original value in the post: 800 µF, later measured 3.88 mF) → split in
   the redesign: C8 (1000 µF) on `5V_IN`, C1 (470 µF) on `VCC`. See "Sizing
   the buffering".
6. **RST auto-reset capacitor:** now C7, 100 nF ceramic (non-polarised). The
   former 4.7 µF electrolytic (C2) was wrong twice over – too large a time
   constant for esptool's 100 ms reset pulse, and a coupling capacitor sees
   voltage in both directions, so a polarised one is unsuitable. Together
   with R6 (10 kΩ) this gives τ = 1 ms.

## Mechanics: enclosure and board dimensions

Requirements from the enclosure (as of 2026-09-07):

| Item | Value |
|---|---|
| Maximum board size | **55 × 80 mm** |
| Mounting holes | 4, grid **50 × 50 mm** (same vertically and horizontally) |
| Standoff inner diameter (thread) | 1.8 mm |
| Standoff outer diameter | 5.0 mm |
| First hole from the top edge | 3.5 mm from hole centre (= 1 mm from standoff edge to board edge) |

### Orientation on the board

The outline in KiCad lies **landscape**: `(0,0) → (80,0) → (80,55) → (0,55)`,
so the 80 mm edge runs along x. This is the same board as "55 × 80
portrait", just rotated by 90°. This gives the hole centres:

```
   x = 3.5 and 53.5 mm      (long side 80 mm, 1 mm margin to the standoff)
   y = 2.5 and 52.5 mm      (short side 55 mm, standoff flush with the edge)
```

**The 1 mm margin only applies to the long side** (confirmed 2026-09-07). On
the short side the standoff sits flush with the board edge:

| Direction | Hole centre | Standoff (⌀5) | Margin to edge |
|---|---|---|---|
| long side (80 mm, x) | 3.5 / 53.5 | 1.0…6.0 and 51.0…56.0 | **1 mm** |
| short side (55 mm, y) | 2.5 / 52.5 | 0…5 and 50…55 | **0 mm, flush** |

That is intentional, not a mistake.

### Component height (requirement 2026-09-07)

The inner height of the enclosure is **max. 20 mm including board and
standoffs**. Rule of thumb: **14 mm component height above the board is
safe, above that it gets risky.**

| Part | Height above PCB | |
|---|---|---|
| C8 1000 µF/10 V, D10 upright | 12.5 mm | ok |
| U4, TPS63802 module soldered flat | 3.5 mm | ok |
| U4 on pin headers | ~6–7 mm | ok |
| Mating connector (Dupont socket) on a vertical pin header | ~14.7 mm | **marginal** |
| C1 470 µF/10 V, D8 | ~11.5 mm | ok |
| D3/D4, R7/R8 upright | ~9–11 mm | ok |
| U2/U3, DIP in socket | ~9 mm | ok |
| Vertical 2.54 mm pin header, no mating connector | 8.5 mm | ok |
| Jumper on J5 | ~7.5 mm | ok |
| Ceramic disc capacitor 100 nF | 5–7 mm | ok |
| SW1/SW2 (6 mm buttons) | ~5 mm | ok |
| U1 (ESP-12E) | ~3 mm | ok |
| Resistors, diodes lying flat | 2.5 mm | ok |

So height is a **selection criterion for U4**: the converter module must
not exceed 14 mm including pin header. Together with the already known
requirements (min. Vin ≤ 4.5 V, ≥ 500 mA, three-pin on 2.54 mm grid), the
whole OKI-78SR and R-78E families are ruled out – their minimum input
voltage is 4.75 V and 7 V respectively.

### Screws and hole diameter (decided 2026-09-07)

| Item | Value |
|---|---|
| Screw | **M2** |
| Head diameter | **4.0 mm** |
| Board hole | **2.2 mm** |
| Footprint | `MountingHole:MountingHole_2.2mm_M2` |

The footprint is a pure `np_thru_hole` – 2.2 mm hole, **no copper**, no net.
It comes with two circles documenting the clearance: ⌀4.40 mm on
`Cmts.User` (screw head) and ⌀4.90 mm as `F.CrtYd` (courtyard). An extra
keep-out is therefore not needed – the courtyard keeps parts away
automatically and is checked by DRC.

The ⌀5 standoff is *irrelevant on the component side*: it sits under the
board, and there are only solder pads there with this pure THT assembly. On
top, the screw head of ⌀4 mm is the limit, and the ⌀4.9 courtyard covers it
with 0.45 mm margin.

On the short side the hole spans y = 1.4 to 3.6 mm; a 1.4 mm wide web
remains to the board edge. With the 3.2 mm (M3) holes used earlier it would
have been only 0.9 mm.

## Placement and routing

The old board (90 × 70 mm, net names from a long-gone revision) could not
be saved and was rebuilt from scratch. The board is fully routed; on
**B.Cu** there is the filled GND back plane `GND_BACKPLANE` (0.6 mm edge
clearance, 0.3 mm copper clearance, thermal relief with 0.6 mm spokes).
After filling the plane, 22 conflict-free signal and supply segments were
moved from B.Cu to F.Cu, including the direct J1↔J3 connections for
`Net-(J1-Pin_5)` to `Net-(J1-Pin_7)`. B.Cu remains reserved for unavoidable
crossings and the GND plane; further layer changes are not forced blindly if
they would cross existing F.Cu nets.
Redundant GND tracks between plated GND pads were then removed. The only
remaining F.Cu GND connection is the necessary route from SMD GND pad 15 of
U1 to the GND via; all other GND pads connect directly to `GND_BACKPLANE`.

The third placement pass (2026-09-11) was needed because choosing the
TPS63802 shrank C8 from 3300 µF lying down to 1000 µF upright, while U4 grew
from 82 to 325 mm².

### Two decisions that drive the placement

* **J1, J3 and J6 are not plugged but soldered directly.** A Dupont socket
  alone is ~14.7 mm tall, with a cable bend on top really 18–20 mm; that
  doesn't fit under the lid (limit 14 mm). The pads of the vertical pin
  headers remain in the layout, the headers are just not fitted – the wires
  go straight into the holes. J2 (FTDI) and J4 (reset) remain pluggable;
  they are only used with the enclosure open anyway.
* **U4 occupies 25.8 × 13.0 mm.** Since 2026-09-11 the real footprint is
  there (portrait, 270°: **VIN at the top, VOUT at the bottom**), the
  placeholder on `Cmts.User` is gone – see section U4.

### Zones

As of rev. 0.3 (2026-09-26), looking at the component side:

| Area | Contents |
|---|---|
| left middle | **U1** (ESP-12E), antenna at the left short edge with keep-out zone |
| top left | J2 (FTDI), C7, SW1 (reset), J4, R3 |
| bottom left | R4, R6, R2, SW2 (flash), J5, TP2 (GND), TP4 (3.3 V) |
| top middle | **U2** (4050), C4, TP5 (SCAN), TP6 (GND), C8 |
| middle | C3, C1, below them **U4** (converter module) and C6 |
| top right | R5, **J3**, **J1**, D1, D2; cable-tie holes H1/H2 |
| bottom right | J6, TP3 (5 V), TP1 (GND), D3/D4/R7/R8 upright, **U3** (74HCT08), C5; H3/H4 |

The cable routing at H1–H4 is marked as a footprint keep-out
`Kabelmontage` / `Kabelmontage_1` ("cable mounting").

Distances of the decoupling capacitors to their supply pin: C3 → U1/8 =
3.4 mm, C4 → U2/1 = 3.5 mm, C5 → U3/14 = 3.4 mm.

With the real footprint (2026-09-11) the connections are fixed: VIN at
(60.10 | 62.64 / 43.22), VOUT at (60.10 | 62.64 / 66.08), GND twice each at
x 52.48 / 55.02 in both rows. **C8 therefore sits 7.7 mm above the converter
input** – good enough for the 1000 µF buffer, especially as the module
brings its own 100 µF input capacitor and C8 is pure energy storage on the
millisecond scale.

The **output side** remains open: after the move on 2026-09-11, C6 (100 nF)
is only 3.6 mm from the VOUT pads and thus done; C1 (470 µF) is still
19.5 mm away. That is the announced follow-up of the U4 surroundings – it is
still pending and remains an optimisation item for a later placement
revision.

To make the 13.0 mm wide body fit between C6 and TP1 at all, **C6 moved
1.2 mm and TP2/TP4 1.0 mm each to the left** on 2026-09-11; C8's reference
text had to move out of the module outline. Afterwards: courtyards clear,
silkscreen clear.

### How the placement was done

Anchored by hand: U1 (antenna at the edge), U2/U3, J1/J3 (pin facing pin so
the six pass-throughs become straight tracks) and U4. The rest by script,
with cost = sum of **pad-to-pad distances** per net; GND, VCC and 5V_IN are
excluded because global nets give no locality signal. Decoupling and buffer
capacitors are instead tied with a high weight to their supply pin. Then
improvement passes until convergence.

### Checks

```
kicad-cli sch erc  --severity-all            → 0 violations
kicad-cli pcb drc  --schematic-parity
  → 0 violations                    (as of 2026-09-26, rev. 0.3;
                                     4 cable-mounting keep-outs H1–H4 are exclusions)
  → schematic_parity: 8 notes       (8 × "extra footprint" for the holes
                                     MH1–MH4 / H1–H4 without symbol – intended)
  → 0 unconnected items
  → 185 track segments, 10 vias; B.Cu GND plane filled
  → minimum copper clearance 0.200 mm, minimum hole 0.30 mm
```

Exact positions are in `hood-control.kicad_pcb`, a view in
[`board-layout.pdf`](board-layout.pdf).

## Status / next steps in KiCad

* The schematic is fully wired, **ERC: 0 errors, 0 warnings** (also with
  `--severity-all`).
* **Every part has a footprint.** Corrected on 2026-09-06: R5 (had
  `Package_DIP:DIP-8_W7.62mm` – a DIP-8 package for a two-pin resistor),
  J4/J5/J6 (had none), U4 (had the Murata land pattern), and the C1/C8
  redistribution.
* The ERC rule `footprint_filter` is set to `ignore` in the project
  settings. It would have reported the R5 error – candidate for re-enabling.
* **Warning about the KiCad MCP tools:** `move_schematic_component`,
  `delete_schematic_wire`, `add_schematic_component` and
  `add_schematic_wire` delete junctions when rewriting the file – even at
  places unrelated to the operation. Reproduced twice (30 → 23 and 30 → 18
  junctions), each time resulting in ~14 ERC errors from silently split
  nets. Make changes either in the GUI or by script directly on the file,
  and afterwards **always** count junctions and diff the netlist against the
  previous state.
* **Board rebuilt on 2026-09-07** (see "Placement"): outline 80 × 55 mm, all
  parts placed, MH1–MH4 as `MountingHole_2.2mm_M2`.
* The dead clearance exception for U5 was removed from
  `hood-control.kicad_dru` – U5 no longer exists in the circuit.
* **U4 module is here, measured and drawn** (2026-09-11): footprint in
  `hood-control.pretty`, placed on the board.
* **Fabrication files are in `kicad/fab/`**: seven Gerber layers (F.Cu, B.Cu,
  F/B.Mask, F/B.Silkscreen, Edge.Cuts), PTH and NPTH drill files, Gerber job
  file and `hood-control-gerber.zip` as upload package. Generation and order
  parameters are in [`kicad/fab/FAB.md`](fab/FAB.md). Important: fabrication
  class **6/6 mil** is mandatory – the minimum copper clearance of 0.200 mm
  is just below the 0.2032 mm that 8/8 mil would require.
* **Later placement optimisation:** the surroundings of U4 could still be
  improved – especially C1 and C6 could move closer to the VOUT side. The
  board is already routed; such a revision would require another routing /
  layer clean-up pass.
* **Rev. 0.3 (2026-09-26):** D3/D4/R7/R8 upright (2.54 mm pitch) in the row
  above U3, outside the keep-out `Kabelmontage_1`. U4 is now linked to its
  symbol; as a result `duplicate_pad_numbers_are_jumpers` is `no` –
  uncritical, all 8 U4 holes are connected on the board.
* DRC exclusions for H1–H4 (cable-tie holes inside the keep-outs) are stored
  in `hood-control.kicad_pro`.

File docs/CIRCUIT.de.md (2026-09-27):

🇬🇧 [English](CIRCUIT.md) · 🇩🇪 **Deutsch**

# Wie die Schaltung funktioniert

Diese Beschreibung erklärt die Platine der Haubensteuerung (Rev. 0.3) so, dass
man sie auch ohne Elektronik-Ausbildung und nach Jahren noch nachvollziehen
kann. Sie erklärt das *Warum*. Die genauen Bauteilwerte, Bestellnummern und
Layout-Details stehen in [`kicad/DESIGN.de.md`](../kicad/DESIGN.de.md), der
Schaltplan liegt als [`kicad/schematic.pdf`](../kicad/schematic.pdf) bei.

Inhalt:

1. [Die Aufgabe in einem Satz](#1-die-aufgabe-in-einem-satz)
2. [Ein paar Grundbegriffe](#2-ein-paar-grundbegriffe)
3. [Wie Haube und Bedienfeld miteinander reden](#3-wie-haube-und-bedienfeld-miteinander-reden)
4. [Überblick über die Platine](#4-überblick-über-die-platine)
5. [Stromversorgung](#5-stromversorgung)
6. [Der Mikrocontroller ESP8266](#6-der-mikrocontroller-esp8266)
7. [Mithören: Scan-Signal und LED-Zustände lesen (U2)](#7-mithören-scan-signal-und-led-zustände-lesen-u2)
8. [Mitreden: Tasten drücken (U3, D3, D4)](#8-mitreden-tasten-drücken-u3-d3-d4)
9. [Die Firmware im Takt der Haube](#9-die-firmware-im-takt-der-haube)
10. [Reset, Flashen und Status-LED](#10-reset-flashen-und-status-led)
11. [Steckverbinder und Messpunkte](#11-steckverbinder-und-messpunkte)
12. [Was wir bei der Inbetriebnahme gelernt haben](#12-was-wir-bei-der-inbetriebnahme-gelernt-haben)
13. [Fehlersuche: Was messe ich wo?](#13-fehlersuche-was-messe-ich-wo)

---

## 1. Die Aufgabe in einem Satz

Die Platine sitzt im Kabel zwischen der Elektronik der Dunstabzugshaube
(Gutmann Sombra) und ihrem Bedienfeld, **liest mit, welche Lämpchen am
Bedienfeld leuchten**, und kann **so tun, als hätte jemand eine Taste
gedrückt** – gesteuert per WLAN/MQTT aus Home Assistant.

Das Original-Bedienfeld funktioniert dabei ganz normal weiter. Die Platine
ist nur ein zusätzlicher „Zuhörer mit Fingern“.

```mermaid
flowchart LR
    Haube["Haubenelektronik<br/>(Motor, Licht)"]
    Platine["Platine<br/>J1 #8644; J3"]
    Panel["Bedienfeld<br/>7 Tasten, 7 LEDs"]
    HA["Home Assistant"]
    Haube <-- "8-adriges Kabel" --> Platine
    Platine <-- "8-adriges Kabel" --> Panel
    Haube -- "Service-Anschluss ~4,8 V #8594; J6" --> Platine
    Platine -. "WLAN / MQTT" .-> HA
```

---

## 2. Ein paar Grundbegriffe

Wer schon Elektronik kann, springt zu Abschnitt 3.

| Begriff | Bedeutung hier |
|---|---|
| **HIGH / LOW** | Digitale Signale kennen nur zwei Zustände. LOW ≈ 0 V (Masse), HIGH ≈ Versorgungsspannung, also 5 V bei der Haube und 3,3 V beim ESP. |
| **Masse / GND** | Der gemeinsame 0-V-Bezug. Spannungen werden immer gegen GND gemessen. Ohne gemeinsame Masse verstehen sich zwei Schaltungen nicht. |
| **Treiben** | Ein Ausgang, der eine Leitung aktiv auf HIGH oder LOW zwingt. |
| **Floaten / hochohmig** | Eine Leitung, an der niemand zieht. Ihr Pegel ist dann zufällig, sie „schwimmt“. CMOS-Eingänge dürfen nie floaten, sonst schalten sie wild hin und her. |
| **Pull-up / Pull-down** | Ein Widerstand (meist 10 kΩ), der eine Leitung sanft auf HIGH (up) bzw. LOW (down) zieht, solange sie niemand aktiv treibt. Ein Treiber kann ihn mühelos überstimmen. |
| **Gegentakt-Ausgang (push-pull)** | Ein Ausgang, der *immer* aktiv treibt – entweder HIGH oder LOW. Er kann nicht „loslassen“. |
| **Diode** | Ein elektrisches Ventil: Strom fließt nur von der Anode zur Kathode (Kathode = Ring auf dem Bauteil). In Durchlassrichtung „kostet“ sie etwa 0,6 V. |
| **Pegelwandler** | Übersetzt zwischen 5-V-Welt (Haube) und 3,3-V-Welt (ESP). |
| **Kondensator (Elko, Kerko)** | Ein kleiner Energiespeicher. Große Elkos (µF) puffern Stromspitzen, kleine Keramik-Kondensatoren (100 nF) direkt am IC fangen hochfrequente Störungen ab („Abblockkondensator“). |
| **Absolute Maximum** | Grenzwert aus dem Datenblatt, der nie überschritten werden darf. Für den ESP8266: 3,6 V an jedem Pin. |

---

## 3. Wie Haube und Bedienfeld miteinander reden

Das Verständnis dieses Abschnitts ist der Schlüssel zu allem anderen.

### Das Problem: 7 Tasten und 7 LEDs, aber nur 8 Adern

Würde man jede Taste und jede LED einzeln verdrahten, bräuchte man 14 Adern
plus Masse. Die Haube kommt mit einem 8-adrigen Netzwerkkabel aus – durch
**Multiplexing** (zeitliches Abwechseln).

Das Bedienfeld enthält nur passive Bauteile: 7 Taster, 7 LEDs und Leiterbahnen.
Alles Intelligente sitzt in der Haube.

### Die Matrix

Die Tasten und LEDs sind in einem Raster aus **4 Zeilen** und **2 Spalten**
angeordnet:

- **4 Scan-Leitungen (Zeilen)** – die Haube legt sie *nacheinander* für je
  1 ms auf 5 V (HIGH), die anderen drei stehen dabei auf 0 V. Nach 4 ms ist
  eine Runde durch, dann beginnt es von vorn – 250 Runden pro Sekunde.
- **2 Tastenleitungen (Spalten)** – eine Taste verbindet eine Zeile mit einer
  Spalte. Ist die Taste gedrückt, erscheint der HIGH-Impuls der Zeile auch
  auf der Spalte. Die Haube sieht also: *„Spalte 1 ist HIGH, während gerade
  Zeile 2 aktiv ist → das muss Taste Stufe 3 sein.“*
- **2 LED-Leitungen (Spalten)** – für eine LED, die leuchten soll, schaltet
  die Haube die LED-Spalte genau während der zugehörigen Zeile so, dass Strom
  durch die LED fließt. Jede LED leuchtet also nur 1 ms von 4 ms – das Auge
  merkt das nicht. An der Platine gemessen bedeutet ein **HIGH auf der
  LED-Spalte in der Mitte des Zeilenfensters: LED an** (so wertet es die
  Firmware aus, und so stimmen die gemeldeten Zustände mit dem Bedienfeld
  überein).

```mermaid
gantt
    title Eine Runde = 4 ms (danach beginnt Zeile A von vorn)
    dateFormat x
    axisFormat %L ms
    section Zeile A
    HIGH :a1, 0, 1ms
    section Zeile B
    HIGH :b1, 1, 1ms
    section Zeile C
    HIGH :c1, 2, 1ms
    section Zeile D
    HIGH :d1, 3, 1ms
    section Tastenspalte
    HIGH (Taste in Zeile B gedr#252;ckt) :crit, t1, 1, 1ms
```

**Die entscheidende Erkenntnis:** Eine Taste zu drücken heißt elektrisch nur,
*im richtigen Millisekunden-Fenster* eine Tastenspalte auf HIGH zu bringen.
Genau das macht die Platine. Und eine LED abzulesen heißt, im richtigen
Fenster nachzusehen, welchen Pegel die LED-Spalte hat.

### Die Adern des Kabels

Das Kabel ist ein Netzwerkkabel mit Farbcode T568B. **Es führt keine Masse
und keine Versorgung** – die holt sich die Platine separat (Abschnitt 5).

| Ader (Pin) | Farbe | Funktion | Platine greift ab |
|---|---|---|---|
| 1 | orange-weiß | LED-Spalte | ja → U2 → GPIO5 |
| 2 | orange | LED-Spalte | ja → U2 → GPIO4 |
| 3 | grün-weiß | Tastenspalte | ja ← D3 ← U3 ← GPIO12 |
| 4 | blau | Tastenspalte | ja ← D4 ← U3 ← GPIO14 |
| 5, 6, 7 | blau-weiß, grün, braun-weiß | drei Scan-Zeilen | nein, nur durchgeschleift |
| 8 | braun | Scan-Zeile „SCAN“ | ja → U2 → GPIO13 (Taktgeber) |

Die Platine hört nur **eine** der vier Scan-Zeilen ab. Das genügt: Kennt man
den Beginn einer Runde, ergeben sich die anderen drei Zeilen aus der Uhrzeit
(je 1 ms später).

---

## 4. Überblick über die Platine

```mermaid
flowchart LR
    J6["J6<br/>~4,8 V von der Haube"] --> V5(["Netz 5V_IN"])
    V5 --- C8["C8 1000 #181;F<br/>Puffer"]
    V5 --> U4["U4 Buck-Boost<br/>TPS63802"]
    V5 --> U3["U3 74HCT08<br/>l#228;uft auf 5 V"]
    U4 --> V33(["Netz VCC = 3,3 V"])
    V33 --- C1["C1 470 #181;F"]
    V33 --> U1["U1 ESP8266"]
    V33 --> U2["U2 CD4050<br/>l#228;uft auf 3,3 V"]
```

```mermaid
flowchart LR
    subgraph Kabel["Kabel J1/J3"]
        LED["Pin 1, 2<br/>LED-Spalten"]
        SCAN["Pin 8<br/>SCAN"]
        BTN["Pin 3, 4<br/>Tastenspalten"]
    end
    LED -- "5 V" --> U2A["U2 CD4050<br/>5 V #8594; 3,3 V"]
    SCAN -- "5 V" --> U2A
    U2A -- "GPIO5, GPIO4<br/>mith#246;ren" --> ESP["U1 ESP8266"]
    U2A -- "GPIO13<br/>Takt" --> ESP
    ESP -- "GPIO12, GPIO14<br/>dr#252;cken" --> U3B["U3 74HCT08<br/>3,3 V #8594; 5 V"]
    U3B --> D["D3 / D4<br/>R#252;ckschlagventil"]
    D --> BTN
```

| Bauteil | Aufgabe in einem Satz |
|---|---|
| **U1** ESP-12E | Der Mikrocontroller mit WLAN – das Gehirn. |
| **U2** CD4050 | Übersetzt die 5-V-Signale der Haube in 3,3 V für den ESP. |
| **U3** 74HCT08 | Übersetzt die 3,3-V-Signale des ESP in 5 V für die Haube. |
| **D3, D4** | Sorgen dafür, dass U3 die Tastenleitungen nur hochziehen, aber nie festhalten kann. |
| **R7, R8** | Halten die Eingänge von U3 auf LOW, solange der ESP noch bootet. |
| **U4** TPS63802-Modul | Macht aus den ~4,8 V der Haube stabile 3,3 V. |
| **C8, C1** | Große Energiepuffer vor bzw. hinter U4. |
| **C3–C6** | Abblockkondensatoren, je einer direkt an jedem IC. |
| **R5** | Zieht die SCAN-Leitung sauber auf LOW, wenn sie nicht aktiv ist. |
| **D1, D2** | Sitzen in den LED-Leitungen zwischen Bedienfeld und Haube (aus der Lochraster-Version übernommen). |
| **R2, R3, R4, R6, C7, SW1, SW2, J5** | Start-, Reset- und Flash-Beschaltung des ESP. |

---

## 5. Stromversorgung

### Woher der Strom kommt

Die Haubenelektronik hat einen **Service-Anschluss** mit ca. **4,8 V**, der
laut Messung etwa **500 mA** liefern kann. Er wird mit einem gekürzten
ISA-Slot-Stecker abgegriffen und an **J6** angelötet (Pin 1 = +, Pin 2 = GND).
Über diesen Anschluss kommt auch die **gemeinsame Masse** mit der Haube –
ohne sie könnte die Platine die Signale im Kabel gar nicht auswerten, weil
Spannungen immer relativ zur Masse gemessen werden.

### Warum 3,3 V und nicht einfach 5 V

Der ESP8266 läuft mit 3,3 V und verträgt **höchstens 3,6 V** an jedem Pin.
Die 5 V der Haube würden ihn zerstören.

### Warum ein Buck-Boost-Wandler (U4)

Ein Spannungswandler macht aus einer Spannung eine andere, ohne die
Differenz wie ein Linearregler in Wärme zu verheizen.

- Ein **Buck** (Abwärtswandler) braucht am Eingang deutlich *mehr* als die
  Ausgangsspannung – typische Module 4,5 bis 6 V. Die Haube liefert aber nur
  4,8 V, und wenn der ESP beim WLAN-Senden kurz ~350 mA zieht, sackt die
  Spannung weiter ab. Dann fällt der Buck aus der Regelung, der ESP bekommt
  zu wenig Spannung, startet neu, zieht beim Start wieder viel Strom … Das
  war der **Brownout-Boot-Loop** der alten Lochrasterplatine.
- Ein **Buck-Boost** kann auch *hochsetzen*. Der TPS63802 regelt von 1,5 V bis
  5,5 V am Eingang sauber auf 3,3 V. Egal wie weit die Haubenspannung kurz
  einbricht – die 3,3 V bleiben stehen.

**Achtung:** Das Modul wird ab Werk auf 4,2 V ausgeliefert und muss vor dem
Einbau per Lötbrücke auf **3,3 V** umgestellt und nachgemessen werden (steht
auch als Aufdruck auf der Platine).

### Die Kondensatoren

- **C8, 1000 µF, am 5-V-Eingang:** Speichert Energie für kurze Stromspitzen,
  damit die Leitung von der Haube nicht bei jedem WLAN-Paket einknickt.
- **C1, 470 µF, am 3,3-V-Ausgang:** Überbrückt die Zeit (~100 µs), die der
  Wandler braucht, um auf eine plötzliche Laständerung zu reagieren.
- **C3, C4, C5, C6, je 100 nF:** Sitzen direkt an U1, U2, U3 und U4. ICs
  schalten sehr schnell und ziehen dabei winzige, aber steile Stromspitzen.
  Diese kleinen Kondensatoren liefern sie „aus nächster Nähe“, bevor Störungen
  über die Leiterbahnen wandern.

Es gibt damit **zwei Spannungsnetze**: `5V_IN` (Haube, U3, C5, C8) und `VCC`
= 3,3 V (ESP, U2, alles andere).

---

## 6. Der Mikrocontroller ESP8266

Der **ESP-12E** ist ein fertiges Modul mit ESP8266-Chip, Flash-Speicher und
Antenne. Die Antenne ist die Zickzack-Leiterbahn an der Schmalseite; unter
ihr darf kein Kupfer liegen (Keep-out-Zone links auf der Platine).

Genutzte Pins:

| Pin | Richtung | Funktion |
|---|---|---|
| GPIO13 | Eingang | SCAN-Takt der Haube (über U2) |
| GPIO4, GPIO5 | Eingang | LED-Spalten (über U2) |
| GPIO12, GPIO14 | Ausgang | Tastenspalten (über U3 und D3/D4) |
| GPIO2 | Ausgang | blaue Status-LED auf dem Modul |
| GPIO0, GPIO15, EN, RST | – | Startverhalten, siehe Abschnitt 10 |
| TXD, RXD | – | serielle Schnittstelle zum Flashen (J2) |

---

## 7. Mithören: Scan-Signal und LED-Zustände lesen (U2)

### Das Problem

Die Signale im Kabel haben 5 V. Direkt an den ESP angeschlossen, würden sie
dessen Grenze von 3,6 V überschreiten.

### Die Lösung: CD4050 als Pegelwandler

Der **CD4050** enthält sechs „Buffer“: Was vorne reinkommt, kommt hinten
unverändert heraus. Seine besondere Eigenschaft: **Seine Eingänge vertragen
bis zu 15 V, auch wenn er selbst nur mit 3,3 V versorgt wird.** Die Ausgänge
liefern aber nur so viel, wie die Versorgung hergibt.

Weil U2 mit 3,3 V läuft, wird aus einem 5-V-HIGH im Kabel ein 3,3-V-HIGH am
ESP – genau passend.

- Buffer A: LED-Spalte Pin 2 → GPIO4
- Buffer B: LED-Spalte Pin 1 → GPIO5
- Buffer C: SCAN (Pin 8) → GPIO13
- Buffer D, E, F werden nicht gebraucht. Ihre Eingänge (Pin 9, 11, 14) liegen
  **fest auf GND**, weil offene CMOS-Eingänge floaten und dann Strom ziehen
  oder schwingen würden.

Nebeneffekt: Die Eingänge des CD4050 sind sehr hochohmig. Die Platine
belastet die Leitungen der Haube beim Mithören praktisch nicht.

### R5: der Pull-down auf SCAN

Die SCAN-Zeile wird von der Haube nur *auf HIGH* aktiv getrieben. In der
restlichen Zeit ist sie nicht sauber definiert. **R5 (2,4 kΩ) nach GND** zieht
sie dann eindeutig auf LOW, sodass der ESP saubere Flanken sieht. Der Wert
ist empirisch: 10 kΩ waren zu schwach, ~2,5 kΩ ergaben ein sauberes Signal.

---

## 8. Mitreden: Tasten drücken (U3, D3, D4)

Das ist der heikelste Teil der Schaltung – und der, der bei der
Inbetriebnahme die meisten Probleme gemacht hat.

### Die Anforderung

Die Tastenspalten gehören **der Haube und dem Bedienfeld**. Die Platine muss
zwei Dinge können:

1. **Drücken:** die Spalte im richtigen Zeitfenster auf HIGH (~5 V) bringen.
2. **Nichts tun:** die Spalte **völlig in Ruhe lassen**, damit das echte
   Bedienfeld weiter funktioniert – und zwar **in jedem Zustand**: im
   Normalbetrieb, während der ESP bootet, wenn er abgestürzt ist und wenn er
   gar keinen Strom hat.

### Schritt 1: 3,3 V → 5 V mit dem 74HCT08 (U3)

Ein ESP-HIGH hat nur 3,3 V. Der **74HCT08** ist eigentlich ein UND-Gatter
(Ausgang HIGH, wenn beide Eingänge HIGH sind). Legt man beide Eingänge
zusammen, wird es zum einfachen Verstärker: HIGH rein → HIGH raus.

Warum gerade die **HCT**-Familie: Sie läuft mit 5 V, erkennt aber schon
**ab 2,0 V** ein HIGH. Die 3,3 V des ESP reichen also sicher, und der Ausgang
liefert volle 5 V. (Ein normaler HC- oder CMOS-Baustein an 5 V bräuchte
~3,5 V als HIGH – das wäre zu knapp.)

- Gatter A: GPIO12 → Pin 1+2 → Pin 3
- Gatter B: GPIO14 → Pin 4+5 → Pin 6
- Gatter C, D unbenutzt, Eingänge fest auf GND (wie bei U2).

### Schritt 2: Die Dioden D3 und D4 – warum sie unverzichtbar sind

U3 hat **Gegentakt-Ausgänge**: Er treibt immer entweder HIGH oder LOW. Hinge
sein Ausgang direkt an der Tastenspalte, würde er sie die meiste Zeit **auf
LOW festhalten**. Dann könnte das echte Bedienfeld keine Taste mehr melden,
und bei zufälligen HIGH-Pegeln sähe die Haube Phantomtasten.

Die Diode wirkt wie ein Rückschlagventil:

```mermaid
flowchart LR
    U3["U3-Ausgang"] -- "Anode" --> D{{"Diode D3 / D4<br/>#9654;|"}}
    D -- "Kathode (Ring)" --> S["Tastenspalte<br/>J1/J3 Pin 3 bzw. 4"]
```

| U3-Ausgang | Diode | Tastenspalte | Haube sieht |
|---|---|---|---|
| HIGH (5 V) | leitet | ≈ 4,3 V | „Taste gedrückt“ |
| LOW (0 V) | sperrt | frei | nichts – das Bedienfeld funktioniert normal |

Die 0,6 V, die die Diode „kostet“, stören nicht: 4,3 V sind für die
5-V-Elektronik der Haube ein eindeutiges HIGH.

Zusätzlicher Schutz: Die 5-V-Impulse auf der Spalte kommen nie beim ESP an.
Sie treffen höchstens auf die gesperrte Diode.

### Schritt 3: Die Pull-downs R7 und R8

Nach dem Einschalten dauert es einige 100 Millisekunden, bis die Firmware
läuft und GPIO12/14 aktiv auf LOW setzt. In dieser Zeit sind die Pins
unbestimmt – U3 dagegen läuft an 5 V sofort mit. Ohne weitere Maßnahme
würden seine Eingänge floaten, und er könnte zufällig HIGH ausgeben – ein
Phantom-Tastendruck genau beim Einschalten.

**R7 und R8 (je 10 kΩ nach GND)** halten die U3-Eingänge in dieser Zeit
sicher auf LOW. Sobald der ESP läuft, überstimmt er sie problemlos.

### Warum nicht einfacher?

Genau diese einfacheren Varianten wurden bei der Inbetriebnahme ausprobiert
und scheiterten (Details in Abschnitt 12):

| Variante | Ergebnis |
|---|---|
| U3 direkt an der Spalte (Rev. 0.2) | ESP bootet in Schleife, Haube zeigt Phantomtasten und reagiert nicht mehr |
| Drahtbrücke: GPIO direkt an die Spalte (wie auf der Lochrasterplatine) | Bedienfeld-LEDs glimmen nur, ESP hängt sich auf |
| Widerstand 1–2,4 kΩ statt Draht | Haube startet mit Fehlercode |
| **U3 + Diode + Pull-down (Rev. 0.3)** | **funktioniert** |

Der gemeinsame Grund für das Scheitern der direkten Varianten: Hängt der
ESP-Pin elektrisch an der Spalte, wirken seine internen Schutzdioden wie
ein Kurzschluss zur 3,3-V-Schiene. Solange der ESP noch keinen Strom hat,
ziehen sie die Spalte nach unten; wenn er läuft, speisen die 5-V-Impulse
über sie in seine Versorgung zurück.

---

## 9. Die Firmware im Takt der Haube

Die Elektronik allein reicht nicht – der ESP muss im richtigen Moment
hinsehen und drücken. So macht es die Firmware ([`src/main.cpp`](../src/main.cpp)):

### Synchronisieren

1. Jede steigende Flanke auf **SCAN** (GPIO13) löst einen Interrupt aus.
2. Liegen zwischen zwei Flanken ziemlich genau **4 ms** (3,9–4,1 ms), ist das
   der Rundenbeginn. Nach mehr als 10 solchen Flanken startet ein Hardware-Timer
   neu, der alle **100 µs** tickt.
3. **40 Ticks = 4 ms = eine Runde.** Die Firmware weiß also jederzeit, welche
   der vier Zeilen gerade aktiv ist.

### Der Ablauf innerhalb einer Runde

| Tick | Aktion |
|---|---|
| 1, 11, 21, 31 | Zeile beginnt: soll in dieser Zeile eine Taste gedrückt werden, GPIO auf HIGH |
| 5, 15, 25, 35 | Mitte der Zeile: LED-Spalten lesen |
| 9, 19, 29, 39 | vor dem Zeilenwechsel: beide Tasten-GPIOs wieder LOW |

Das Drücken endet bewusst *vor* dem Zeilenwechsel, damit ein Tastendruck
nicht in die nächste Zeile „überläuft“ und dort eine falsche Taste auslöst.

### Welche Taste und LED wo liegt

„Kanal 1“ = LED-Spalte J1/2 (GPIO4) bzw. Tastenspalte J1/4 (GPIO14),
„Kanal 2“ = LED-Spalte J1/1 (GPIO5) bzw. Tastenspalte J1/3 (GPIO12).

| Zeitfenster (Ticks) | Kanal 1 | Kanal 2 |
|---|---|---|
| 1–10 | Lüfter Stufe 2 | Licht |
| 11–20 | Lüfter Stufe 3 | Filter reinigen |
| 21–30 | Lüfter Stufe 4 | – |
| 31–40 | Lüfter Stufe 1 | Timer (Nachlauf) |

(Die beiden Kanäle kommen gegenüber der Lochraster-Firmware vertauscht an;
das ist in der Firmware ausgeglichen, siehe `ledPin1/2` und `buttonPin1/2`.)

### Drücken und Lesen im Detail

- **Drücken:** Ein MQTT-Befehl setzt einen Zähler, z. B. 100. In jeder Runde,
  in der die Zeile dran ist, wird HIGH ausgegeben und der Zähler verringert.
  100 Runden × 4 ms = **0,4 s** Tastendruck. „Filter reinigen“ wird mit 1500
  Runden = **6 s** lang gedrückt – die Haube erwartet dort offenbar einen
  langen Druck, damit man die Filteranzeige nicht versehentlich zurücksetzt.
- **Lesen:** Eine LED gilt erst dann als umgeschaltet, wenn sie **mehr als
  20 Runden hintereinander** (80 ms) im neuen Zustand war. Das filtert
  Störungen heraus. Ausnahme Filter-LED: Ist sie an, muss sie für „aus“
  deutlich länger (375 Runden = 1,5 s) dunkel bleiben – vermutlich, weil sie
  im eingeschalteten Zustand blinkt.
- Jede erkannte Änderung wird per MQTT gemeldet (`…/ventilation/state`,
  `…/light/state`, `…/timer/state`, `…/maintenance/state`).

---

## 10. Reset, Flashen und Status-LED

Der ESP8266 entscheidet beim Einschalten anhand einiger Pins, *was* er tut.
Diese Pins brauchen definierte Pegel:

| Pin | muss beim Start sein | erledigt durch |
|---|---|---|
| **EN** (Enable) | HIGH, sonst schläft der Chip | R4 (10 kΩ) nach 3,3 V |
| **RST** (Reset) | HIGH, LOW = Neustart | R6 (10 kΩ) nach 3,3 V; SW1 bzw. J4 ziehen auf GND |
| **GPIO15** | LOW | R3 (10 kΩ) nach GND |
| **GPIO0** | HIGH = Programm starten, LOW = Flash-Modus | Jumper J5 |

### Jumper J5 (Flash/Run)

| Stellung | Wirkung |
|---|---|
| **1–2 = RUN** (Normalbetrieb) | R2 zieht GPIO0 auf HIGH → Firmware startet |
| 2–3 = FLASH | GPIO0 auf GND → ESP wartet auf neue Firmware |

**Der Jumper muss immer stecken.** Ohne ihn floatet GPIO0 und der ESP startet
unzuverlässig – das war auf der Lochrasterplatine die Hauptursache für
sporadische Bootfehler.

**SW2 (Flash)** zieht GPIO0 ebenfalls auf GND. Wird er beim Start gehalten,
löscht die Firmware die gespeicherten WLAN- und MQTT-Einstellungen.

### Flashen über J2

J2 ist die Buchse für einen USB-Seriell-Adapter (FTDI, 3,3 V):
DTR – RXI – TXO – 3V3 – NC – GND.

- **C7 (100 nF)** koppelt die DTR-Leitung auf RST. Wenn das Flash-Programm
  DTR umschaltet, entsteht ein kurzer Reset-Impuls (automatischer Reset).
  Es muss ein *ungepolter* Keramik-Kondensator sein, weil die Spannung an
  ihm beide Richtungen annehmen kann.
- GPIO0 wird **nicht** automatisch umgeschaltet: Zum seriellen Flashen J5
  auf FLASH stecken, danach zurück auf RUN und Reset drücken.
- Im Alltag wird ohnehin **per WLAN (OTA)** geflasht, siehe
  [`OPERATIONS.de.md`](OPERATIONS.de.md).

**Wichtig:** Über den 3V3-Pin von J2 versorgt der Adapter den ESP direkt mit
3,3 V. Ein Test nur am Adapter sagt deshalb **nichts** über die eigentliche
Stromversorgung über J6 und U4 aus.

### Status-LED (blau, auf dem ESP-Modul)

| Muster | Bedeutung |
|---|---|
| 3 kurze Blitze | Start |
| schnell (150 ms) | verbindet mit WLAN |
| mittel (400 ms) | verbindet mit MQTT |
| langsam (1 s) | Einrichtungs-Hotspot `HoodControl-Setup` aktiv |
| alle 3 s ein kurzer Blitz | alles in Ordnung |
| dauerhaft dunkel | Firmware hängt |

---

## 11. Steckverbinder und Messpunkte

| Bezeichnung | Art | Zweck |
|---|---|---|
| **J1** Hoodcontrol | Adern direkt eingelötet | Kabel zur Haubenelektronik |
| **J3** Frontpanel | Adern direkt eingelötet | Kabel zum Bedienfeld |
| **J6** PWR_IN | Adern direkt eingelötet | 5 V und GND vom Service-Anschluss |
| **J2** | Stiftleiste 1×6 | USB-Seriell-Adapter zum Flashen |
| **J4** | Stiftleiste 1×2 | externer Reset-Taster (parallel zu SW1) |
| **J5** | Stiftleiste 1×3 + Jumper | RUN/FLASH |

J1, J3 und J6 haben keine Stecker, weil ein aufgesteckter Stecker samt
Kabelbogen zu hoch für das Gehäuse wäre (Grenze: 14 mm Bauhöhe). Die Kabel
werden an den Bohrungen H1–H4 mit Kabelbindern zugentlastet.

| Messpunkt | Soll |
|---|---|
| **TP3** | 5V_IN, ~4,8 V |
| **TP4** | VCC, 3,3 V (nie über 3,6 V!) |
| **TP5** | SCAN – mit Oszilloskop: 1-ms-Impulse alle 4 ms |
| **TP1, TP2, TP6** | GND, Bezug für alle Messungen |

---

## 12. Was wir bei der Inbetriebnahme gelernt haben

Chronologie der Inbetriebnahme im September 2026, damit die Entscheidungen
nachvollziehbar bleiben:

1. **Nur am FTDI-Adapter:** ESP geflasht, WLAN und MQTT laufen. (Das testet
   die 3,3-V-Seite, nicht U4 – siehe Abschnitt 10.)
2. **Mit Haube, U3 direkt an der Tastenspalte (Rev. 0.2):** Boot-Schleife,
   Phantomtasten „Stufe 3“ und „Filter reinigen“ – beide liegen in Zeile 2,
   also sah die Haube *beide* Tastenspalten gleichzeitig HIGH. Ursache: U3
   treibt die Spalten mit zufälligen Pegeln (Abschnitt 8).
3. **U3 gezogen:** stabil, LEDs werden gelesen – aber Lüfter 1 wird als
   „Timer“, Lüfter 2 als „Licht“ erkannt: gleiche Zeile, falscher Kanal →
   LED-Kanäle vertauscht, in der Firmware korrigiert.
4. **Drahtbrücke statt U3:** Bedienfeld-LEDs glimmen, ESP hängt sich auf Haubenstrom auf.
5. **Widerstand statt Draht:** Haube startet mit Fehlercode.
6. **U3 mit Diode und Pull-downs:** funktioniert. „Licht an“ schaltet
   Stufe 2 → auch die Tastenkanäle vertauscht, in der Firmware korrigiert.
7. **Haubenlicht geht beim Einschalten an:** Das macht die Haube auch ganz ohne
   Platine – kein Fehler der Schaltung.

Die Lochrasterplatine hatte GPIO12/14 direkt an den Tastenspalten und lief
damit jahrelang, allerdings mit 5 V an Pins, die nur 3,6 V vertragen. Das
gelegentliche „plötzliche Loslaufen“ der Haube in dieser Zeit passt gut zu
Phantomtasten über diesen Weg. Mit Rev. 0.3 ist der ESP elektrisch von den
Tastenspalten getrennt.

---

## 13. Fehlersuche: Was messe ich wo?

| Symptom | Zuerst prüfen |
|---|---|
| ESP startet gar nicht | TP4 = 3,3 V? Jumper J5 auf RUN (1–2)? |
| ESP startet immer wieder neu | TP3 und TP4 während des Blinkens messen; bricht TP4 ein → U4/Lötstellen |
| Haube zeigt Tasten, die niemand drückt | U3 ziehen – verschwindet es, liegt es am Tastenpfad (Dioden, Pull-downs, Firmware) |
| Bedienfeld-LEDs glimmen nur | Etwas belastet die LED- oder Scan-Leitungen – Brücken/Bauteile an U2 und J1 prüfen |
| LED-Zustände falsch zugeordnet | gleiche Zeile, anderer Kanal? → `ledPin1/2` tauschen |
| MQTT-Befehl drückt falsche Taste | gleiche Zeile, anderer Kanal? → `buttonPin1/2` tauschen |
| Keine LED-Zustände, obwohl ESP läuft | SCAN an TP5 prüfen; R5 vorhanden? U2 richtig herum im Sockel? |
| Nichts auf der seriellen Schnittstelle | Adapter richtig herum auf J2 (GND an Pin 6)? TX/RX vertauscht? |

Grundregel beim Umstecken von ICs, Brücken oder Kabeln: **immer stromlos.**

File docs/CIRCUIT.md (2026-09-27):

🇬🇧 **English** · 🇩🇪 [Deutsch](CIRCUIT.de.md)

# How the circuit works

This document explains the hood controller board (rev. 0.3) so that it can
be followed without an electronics background – and still makes sense years
from now. It explains the *why*. Exact part values, order numbers and layout
details are in [`kicad/DESIGN.md`](../kicad/DESIGN.md); the schematic is
available as [`kicad/schematic.pdf`](../kicad/schematic.pdf).

Contents:

1. [The job in one sentence](#1-the-job-in-one-sentence)
2. [A few basic terms](#2-a-few-basic-terms)
3. [How hood and front panel talk to each other](#3-how-hood-and-front-panel-talk-to-each-other)
4. [Board overview](#4-board-overview)
5. [Power supply](#5-power-supply)
6. [The ESP8266 microcontroller](#6-the-esp8266-microcontroller)
7. [Listening in: reading the scan signal and LED states (U2)](#7-listening-in-reading-the-scan-signal-and-led-states-u2)
8. [Joining in: pressing keys (U3, D3, D4)](#8-joining-in-pressing-keys-u3-d3-d4)
9. [Firmware in step with the hood](#9-firmware-in-step-with-the-hood)
10. [Reset, flashing and status LED](#10-reset-flashing-and-status-led)
11. [Connectors and test points](#11-connectors-and-test-points)
12. [What we learned during bring-up](#12-what-we-learned-during-bring-up)
13. [Troubleshooting: what to measure where](#13-troubleshooting-what-to-measure-where)

---

## 1. The job in one sentence

The board sits in the cable between the electronics of the range hood
(Gutmann Sombra) and its front panel, **reads which front-panel lights are
on**, and can **pretend someone pressed a key** – controlled over Wi-Fi/MQTT
from Home Assistant.

The original front panel keeps working normally. The board is just an extra
"listener with fingers".

```mermaid
flowchart LR
    Hood["Hood electronics<br/>(motor, light)"]
    Board["Board<br/>J1 #8644; J3"]
    Panel["Front panel<br/>7 keys, 7 LEDs"]
    HA["Home Assistant"]
    Hood <-- "8-wire cable" --> Board
    Board <-- "8-wire cable" --> Panel
    Hood -- "service connector ~4.8 V #8594; J6" --> Board
    Board -. "Wi-Fi / MQTT" .-> HA
```

---

## 2. A few basic terms

If you already know electronics, skip to section 3.

| Term | Meaning here |
|---|---|
| **HIGH / LOW** | Digital signals have only two states. LOW ≈ 0 V (ground), HIGH ≈ supply voltage, i.e. 5 V on the hood side and 3.3 V on the ESP side. |
| **Ground / GND** | The common 0 V reference. Voltages are always measured against GND. Without a common ground, two circuits cannot understand each other. |
| **Drive** | An output actively forcing a line HIGH or LOW. |
| **Floating / high-impedance** | A line nobody is pulling. Its level is random – it "floats". CMOS inputs must never float, or they toggle wildly. |
| **Pull-up / pull-down** | A resistor (usually 10 kΩ) that gently pulls a line HIGH (up) or LOW (down) while nobody drives it. A driver overrides it easily. |
| **Push-pull output** | An output that *always* drives – either HIGH or LOW. It cannot "let go". |
| **Diode** | An electrical one-way valve: current flows only from anode to cathode (cathode = the ring on the part). In the forward direction it "costs" about 0.6 V. |
| **Level shifter** | Translates between the 5 V world (hood) and the 3.3 V world (ESP). |
| **Capacitor (electrolytic, ceramic)** | A small energy store. Large electrolytics (µF) buffer current peaks; small ceramic capacitors (100 nF) right at each IC absorb high-frequency noise ("decoupling capacitor"). |
| **Absolute maximum** | A datasheet limit that must never be exceeded. For the ESP8266: 3.6 V on any pin. |

---

## 3. How hood and front panel talk to each other

Understanding this section is the key to everything else.

### The problem: 7 keys and 7 LEDs, but only 8 wires

Wiring every key and every LED separately would need 14 wires plus ground.
The hood gets by with an 8-wire network cable – thanks to **multiplexing**
(taking turns in time).

The front panel contains only passive parts: 7 keys, 7 LEDs and traces.
All the intelligence is in the hood.

### The matrix

Keys and LEDs are arranged in a grid of **4 rows** and **2 columns**:

- **4 scan lines (rows)** – the hood drives them to 5 V (HIGH) *one after
  another* for 1 ms each while the other three stay at 0 V. After 4 ms one
  round is complete and it starts over – 250 rounds per second.
- **2 key lines (columns)** – a key connects one row to one column. When
  the key is pressed, the row's HIGH pulse also appears on the column. So the
  hood sees: *"column 1 is HIGH while row 2 is active → that must be the fan
  level 3 key."*
- **2 LED lines (columns)** – for an LED that should be lit, the hood sets
  the LED column during exactly that row so that current flows through the
  LED. Each LED is therefore lit for only 1 ms out of 4 ms – the eye doesn't
  notice. Measured on the board, a **HIGH on the LED column in the middle
  of the row window means: LED on** (that is how the firmware evaluates it,
  and the reported states match the front panel).

```mermaid
gantt
    title One round = 4 ms (then row A starts again)
    dateFormat x
    axisFormat %L ms
    section Row A
    HIGH :a1, 0, 1ms
    section Row B
    HIGH :b1, 1, 1ms
    section Row C
    HIGH :c1, 2, 1ms
    section Row D
    HIGH :d1, 3, 1ms
    section Key column
    HIGH (key in row B pressed) :crit, t1, 1, 1ms
```

**The key insight:** electrically, pressing a key simply means bringing a key
column HIGH *in the right millisecond window*. That is exactly what the
board does. And reading an LED means looking at the LED column's level in
the right window.

### The wires of the cable

The cable is a network cable with T568B colour code. **It carries neither
ground nor supply** – the board gets those separately (section 5).

| Wire (pin) | Colour | Function | Board taps it |
|---|---|---|---|
| 1 | orange-white | LED column | yes → U2 → GPIO5 |
| 2 | orange | LED column | yes → U2 → GPIO4 |
| 3 | green-white | key column | yes ← D3 ← U3 ← GPIO12 |
| 4 | blue | key column | yes ← D4 ← U3 ← GPIO14 |
| 5, 6, 7 | blue-white, green, brown-white | three scan rows | no, just passed through |
| 8 | brown | scan row "SCAN" | yes → U2 → GPIO13 (clock reference) |

The board listens to only **one** of the four scan rows. That is enough:
once the start of a round is known, the other three rows follow from the
time (1 ms apart).

---

## 4. Board overview

```mermaid
flowchart LR
    J6["J6<br/>~4.8 V from the hood"] --> V5(["net 5V_IN"])
    V5 --- C8["C8 1000 #181;F<br/>buffer"]
    V5 --> U4["U4 buck-boost<br/>TPS63802"]
    V5 --> U3["U3 74HCT08<br/>runs on 5 V"]
    U4 --> V33(["net VCC = 3.3 V"])
    V33 --- C1["C1 470 #181;F"]
    V33 --> U1["U1 ESP8266"]
    V33 --> U2["U2 CD4050<br/>runs on 3.3 V"]
```

```mermaid
flowchart LR
    subgraph Cable["Cable J1/J3"]
        LED["pins 1, 2<br/>LED columns"]
        SCAN["pin 8<br/>SCAN"]
        BTN["pins 3, 4<br/>key columns"]
    end
    LED -- "5 V" --> U2A["U2 CD4050<br/>5 V #8594; 3.3 V"]
    SCAN -- "5 V" --> U2A
    U2A -- "GPIO5, GPIO4<br/>listen" --> ESP["U1 ESP8266"]
    U2A -- "GPIO13<br/>clock" --> ESP
    ESP -- "GPIO12, GPIO14<br/>press" --> U3B["U3 74HCT08<br/>3.3 V #8594; 5 V"]
    U3B --> D["D3 / D4<br/>check valve"]
    D --> BTN
```

| Part | Job in one sentence |
|---|---|
| **U1** ESP-12E | The microcontroller with Wi-Fi – the brain. |
| **U2** CD4050 | Translates the hood's 5 V signals to 3.3 V for the ESP. |
| **U3** 74HCT08 | Translates the ESP's 3.3 V signals to 5 V for the hood. |
| **D3, D4** | Make sure U3 can only pull the key lines up, never hold them. |
| **R7, R8** | Keep U3's inputs LOW while the ESP is still booting. |
| **U4** TPS63802 module | Turns the hood's ~4.8 V into a stable 3.3 V. |
| **C8, C1** | Large energy buffers before and after U4. |
| **C3–C6** | Decoupling capacitors, one right at each IC. |
| **R5** | Pulls the SCAN line cleanly LOW when it is not active. |
| **D1, D2** | Sit in the LED lines between front panel and hood (carried over from the perfboard version). |
| **R2, R3, R4, R6, C7, SW1, SW2, J5** | Boot, reset and flash circuitry of the ESP. |

---

## 5. Power supply
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

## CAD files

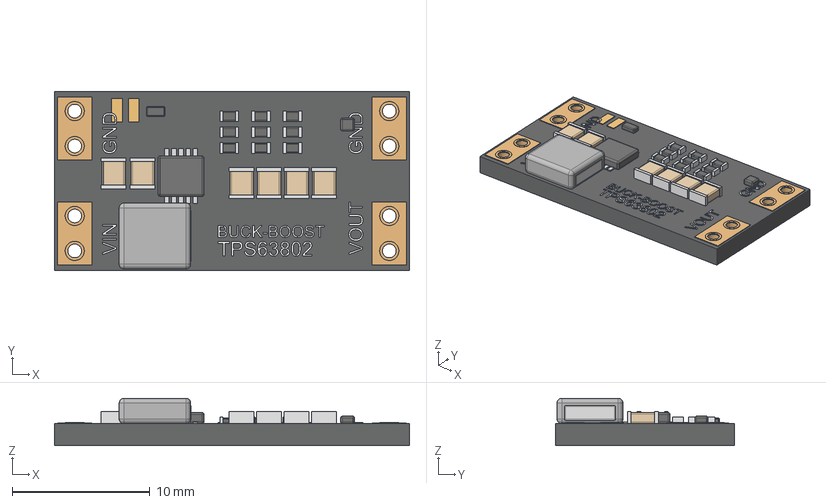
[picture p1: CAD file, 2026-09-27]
kicad/3dmodels/TPS63802_Module_25.8x13.0mm.step
25.8 x 13.0 x 3.45 mm

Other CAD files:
kicad/3dmodels/TPS63802_Module_25.8x13.0mm.FCStd

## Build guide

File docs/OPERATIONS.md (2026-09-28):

🇬🇧 **English** · 🇩🇪 [Deutsch](OPERATIONS.de.md)

# Operation, diagnostics and flashing

This document summarises the hardware data determined on 16 August 2026,
the observed failure pattern, and how to operate firmware version 0.0.7 and
later.

## Hardware

| Property | Value |
| --- | --- |
| Platform | ESP8266 |
| Detected chip | ESP8266EX |
| Features | Wi-Fi, up to 160 MHz |
| Crystal | 26 MHz |
| MAC address | `68:c6:3a:88:b4:ba` |
| PlatformIO board | `nodemcuv2` |
| Circuit design | ESP8266-12E module |
| Serial adapter | `/dev/cu.usbserial-AD025JRF` or `/dev/tty.usbserial-AD025JRF` |
| Firmware baud rate | 115200 baud |
| ROM boot output | 74880 baud |

The MAC address uniquely identifies this particular device. The address
`192.168.178.48` used during diagnosis was assigned dynamically via DHCP and
may change.

## Original failure pattern

- The device is regularly disconnected from power once or twice a day.
- This worked for several weeks.
- Afterwards the device stayed offline in MQTT for about five days.
- After a restart, Pi-hole showed no DNS query for the MQTT broker.
- The known DHCP leases did not belong to the device; its MAC address was
  not present.
- After removing it and starting it at a location with stronger Wi-Fi, the
  device connected again.

The test outside the installation location proves that the ESP8266, flash,
firmware configuration, Wi-Fi and MQTT work in principle. It says nothing
about the radio quality at the installation location.

## Probable cause

The old firmware used a blocking call to `WiFiManager::autoConnect()`. If
the first Wi-Fi connection at power-up failed because of the weak signal,
the device fell into a permanently blocking configuration portal. The later
reconnect logic in `loop()` was never reached.

Not seeing the setup hotspot at the installation location does not rule out
this state: the ESP8266's own signal can be heavily attenuated by the same
location.

The built-in power supply also remains a possible cause. Successful
operation over USB can hide a weak or unstable 3.3 V supply.

## Behaviour from firmware 0.0.7

1. The firmware starts the hood control without waiting for Wi-Fi.
2. It tries to reach the stored network every ten seconds.
3. After 20 seconds without a connection it additionally starts the
   password-protected hotspot `HoodControl-Setup`.
4. The portal is available at `http://192.168.4.1`.
5. While the hotspot is active, the device retries the stored network every
   30 seconds.
6. After one minute of stable Wi-Fi the hotspot is shut down.
7. MQTT connection attempts use exponential backoff from five seconds up to
   five minutes.
8. After an MQTT reconnect, discovery and all hood states are republished.

## Configuration hotspot

| Property | Value |
| --- | --- |
| SSID | `HoodControl-Setup` |
| Password | `hoodcontrol` (default, see below) |
| Portal | `http://192.168.4.1` |

The password must be at least eight characters long, otherwise the ESP8266
cannot start the hotspot as a protected network.

The default password is public. Set your own at build time, together with
the default MQTT broker (the broker can also be changed later in the
portal), e.g. in `platformio.ini`:

```ini
build_flags =
  -D PORTAL_PASSWORD='"my-secret-pw"'
  -D MQTT_HOST='"mqtt.example.lan"'
```

After saving new Wi-Fi or MQTT settings the device restarts in a controlled
way.

## MQTT

The default prefix is `home/kitchen/hood`.

### Availability

| Topic | Meaning |
| --- | --- |
| `$online` | retained availability, `true` or last will `false` |
| `$firmware` | firmware version |
| `$ip` | current DHCP address |
| `$wifi_rssi` | Wi-Fi signal strength in dBm |
| `$uptime` | uptime in seconds |
| `$reset_reason` | ESP8266 reset reason |
| `$last_error` | last detected error |

### Extended diagnostics

The retained topic `diagnostics` contains, among other things:

```json
{
  "firmware": "0.0.7",
  "uptime_s": 1234,
  "rssi": -78,
  "wifi_status": 3,
  "ip": "192.168.178.48",
  "mqtt_state": 0,
  "wifi_reconnects": 2,
  "mqtt_reconnects": 3,
  "mqtt_failures": 1,
  "free_heap": 35892,
  "reset_reason": "External System",
  "previous_boot_stage": "running",
  "last_error": "none",
  "portal_active": false
}
```

The non-retained topic `events` delivers up to 16 buffered events as soon as
MQTT is reachable again, for example Wi-Fi drop-outs, reconnect attempts,
portal start and MQTT errors.

### Interpreting RSSI

| RSSI | Assessment |
| --- | --- |
| better than -60 dBm | good |
| -60 to -70 dBm | usable |
| -70 to -80 dBm | weak |
| worse than -80 dBm | very unstable |

What matters is the value at the actual installation location with the hood
closed.

## USB flashing

### Normal PlatformIO upload

```sh
pio run -e nodemcuv2 -t upload
```

The automatic switch into the bootloader did not work reliably with the
serial adapter at hand and ended with:

```text
Failed to connect to ESP8266: Timed out waiting for packet header
```

### Manual procedure that worked

1. Hold down the single button on the module.
2. Connect the serial adapter or start an upload with automatic reset.
3. Keep the button pressed while the connection is established.
4. Once writing has started, the button can be released.
5. After flashing, reconnect the adapter without the button pressed so that
   the firmware starts normally.

Direct upload used:

```sh
esptool --chip esp8266 \
  --port /dev/cu.usbserial-AD025JRF \
  --baud 115200 \
  --before default-reset \
  --after hard-reset \
  write-flash 0x0 .pio/build/nodemcuv2/firmware.bin
```

The successful run detected the ESP8266EX with MAC address
`68:c6:3a:88:b4:ba`, wrote 437,760 bytes and then verified the flash hash.

Pressing the button at power-up most likely pulls GPIO0 LOW and thereby
activates the ROM bootloader. Without the button pressed, the application
firmware starts.

(On the PCB rev. 0.2/0.3 the jumper J5 selects RUN or FLASH instead – see
[CIRCUIT.md](CIRCUIT.md), section 10.)

## Diagnostic procedure after another failure

1. Check whether `home/kitchen/hood/$online` has changed to `false`.
2. Look for `HoodControl-Setup` and open `192.168.4.1` if needed.
3. Search Pi-hole or the DHCP server for MAC address `68:c6:3a:88:b4:ba`.
4. Check the MQTT topics `$wifi_rssi`, `$last_error`, `$reset_reason`,
   `diagnostics` and `events`.
5. With USB access, open the serial monitor at 115200 baud.
6. If the USB-serial port is visible but not even the ESP ROM bootloader
   sends any data, check the supply, reset and boot pins.

## Electrical check

If the device only works reliably on USB but not in the hood, measure
against GND:

| Pin | Expected level |
| --- | --- |
| VCC | about 3.3 V |
| EN/CH_PD | HIGH, about 3.3 V |
| RST | HIGH, about 3.3 V |
| GPIO0 | HIGH on normal start |
| GPIO2 | HIGH on normal start |
| GPIO15 | LOW on normal start |

Voltage dips during Wi-Fi transmit bursts are also relevant. The firmware
uses maximum Wi-Fi transmit power and disables Wi-Fi sleep mode, which makes
a stable power supply especially important.

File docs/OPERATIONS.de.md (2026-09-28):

🇬🇧 [English](OPERATIONS.md) · 🇩🇪 **Deutsch**

# Betrieb, Diagnose und Flashen

Dieses Dokument fasst die am 16. August 2026 ermittelten Hardwaredaten, das
beobachtete Fehlerbild und die Bedienung der Firmware ab Version 0.0.7
zusammen.

## Hardware

| Eigenschaft | Wert |
| --- | --- |
| Plattform | ESP8266 |
| Erkannter Chip | ESP8266EX |
| Fähigkeiten | WLAN, bis 160 MHz |
| Quarz | 26 MHz |
| MAC-Adresse | `68:c6:3a:88:b4:ba` |
| PlatformIO-Board | `nodemcuv2` |
| Schaltungsentwurf | ESP8266-12E-Modul |
| Serieller Adapter | `/dev/cu.usbserial-AD025JRF` bzw. `/dev/tty.usbserial-AD025JRF` |
| Firmware-Baudrate | 115200 Baud |
| ROM-Bootausgabe | 74880 Baud |

Die MAC-Adresse identifiziert dieses konkrete Gerät eindeutig. Die während der
Diagnose verwendete Adresse `192.168.178.48` wurde dynamisch per DHCP vergeben
und kann sich ändern.

## Ursprüngliches Fehlerbild

- Das Gerät wird regelmäßig ein- bis zweimal täglich von der
  Stromversorgung getrennt.
- Dieses Verhalten funktionierte mehrere Wochen.
- Anschließend blieb das Gerät etwa fünf Tage dauerhaft in MQTT offline.
- Im Pi-hole erschien nach einem Neustart keine DNS-Anfrage für
  den MQTT-Broker.
- Die bekannten DHCP-Einträge gehörten nicht zum Gerät; dessen MAC-Adresse war
  dort nicht vorhanden.
- Nach dem Ausbau und einem Start an einem Standort mit stärkerem WLAN
  verband sich das Gerät wieder.

Der Test außerhalb des Einbauorts beweist die grundsätzliche Funktion von
ESP8266, Flash, Firmwarekonfiguration, WLAN und MQTT. Er bewertet nicht die
Funkqualität am Einbauort.

## Wahrscheinliche Ursache

Die alte Firmware verwendete einen blockierenden Aufruf von
`WiFiManager::autoConnect()`. Schlug die erste WLAN-Verbindung beim Einschalten
wegen des schwachen Signals fehl, wechselte das Gerät in ein dauerhaft
blockierendes Konfigurationsportal. Die spätere Reconnect-Logik in `loop()`
wurde dann nicht erreicht.

Das fehlende Setup-WLAN am Einbauort schließt diesen Zustand nicht aus: Das
Signal des ESP8266 kann durch denselben Einbauort ebenfalls stark gedämpft
werden.

Zusätzlich bleibt die eingebaute Stromversorgung eine mögliche Fehlerquelle.
Ein erfolgreicher Betrieb über USB kann eine schwache oder instabile
3,3-V-Versorgung verdecken.

## Verhalten ab Firmware 0.0.7

1. Die Firmware startet die Haubensteuerung ohne auf das WLAN zu warten.
2. Sie versucht alle zehn Sekunden, das gespeicherte WLAN zu erreichen.
3. Nach 20 Sekunden ohne Verbindung startet zusätzlich der geschützte Hotspot
   `HoodControl-Setup`.
4. Das Portal ist unter `http://192.168.4.1` erreichbar.
5. Während der Hotspot aktiv ist, versucht das Gerät alle 30 Sekunden erneut,
   das gespeicherte WLAN zu erreichen.
6. Nach einer Minute stabiler WLAN-Verbindung wird der Hotspot beendet.
7. MQTT-Verbindungsversuche verwenden exponentielles Backoff von fünf Sekunden
   bis maximal fünf Minuten.
8. Nach einem MQTT-Reconnect werden Discovery und alle Haubenzustände erneut
   publiziert.

## Konfigurations-Hotspot

| Eigenschaft | Wert |
| --- | --- |
| SSID | `HoodControl-Setup` |
| Passwort | `hoodcontrol` (Standard, siehe unten) |
| Portal | `http://192.168.4.1` |

Das Passwort muss mindestens acht Zeichen lang sein, da der ESP8266-Hotspot
sonst nicht als geschütztes WLAN gestartet werden kann.

Das Standardpasswort ist öffentlich. Ein eigenes Passwort und den
Standard-MQTT-Broker (der Broker lässt sich auch später im Portal ändern)
beim Bauen setzen, z. B. in `platformio.ini`:

```ini
build_flags =
  -D PORTAL_PASSWORD='"mein-geheimes-pw"'
  -D MQTT_HOST='"mqtt.example.lan"'
```

Nach dem Speichern neuer WLAN- oder MQTT-Einstellungen startet das Gerät
kontrolliert neu.

## MQTT

Der Standardpräfix lautet `home/kitchen/hood`.

### Verfügbarkeit

| Topic | Bedeutung |
| --- | --- |
| `$online` | Retained-Verfügbarkeit, `true` oder Last-Will `false` |
| `$firmware` | Firmwareversion |
| `$ip` | Aktuelle DHCP-Adresse |
| `$wifi_rssi` | WLAN-Signalstärke in dBm |
| `$uptime` | Laufzeit in Sekunden |
| `$reset_reason` | Resetursache des ESP8266 |
| `$last_error` | Zuletzt erkannter Fehler |

### Erweiterte Diagnose

Das retained Topic `diagnostics` enthält unter anderem:

```json
{
  "firmware": "0.0.7",
  "uptime_s": 1234,
  "rssi": -78,
  "wifi_status": 3,
  "ip": "192.168.178.48",
  "mqtt_state": 0,
  "wifi_reconnects": 2,
  "mqtt_reconnects": 3,
  "mqtt_failures": 1,
  "free_heap": 35892,
  "reset_reason": "External System",
  "previous_boot_stage": "running",
  "last_error": "none",
  "portal_active": false
}
```

Das nicht-retained Topic `events` liefert bis zu 16 gepufferte Ereignisse nach,
sobald MQTT wieder erreichbar ist. Beispiele sind WLAN-Abbrüche,
Reconnect-Versuche, Portalstart und MQTT-Fehler.

### RSSI einordnen

| RSSI | Einschätzung |
| --- | --- |
| besser als -60 dBm | gut |
| -60 bis -70 dBm | brauchbar |
| -70 bis -80 dBm | schwach |
| schlechter als -80 dBm | sehr instabil |

Entscheidend ist der Messwert am tatsächlichen Einbauort bei geschlossener
Haube.

## USB-Flashvorgang

### Normaler PlatformIO-Upload

```sh
pio run -e nodemcuv2 -t upload
```

Der automatische Wechsel in den Bootloader funktionierte mit dem vorhandenen
seriellen Adapter nicht zuverlässig und endete mit:

```text
Failed to connect to ESP8266: Timed out waiting for packet header
```

### Erfolgreiches manuelles Verfahren

1. Die einzelne Taste am Modul gedrückt halten.
2. Den seriellen Adapter verbinden beziehungsweise einen Upload mit
   automatischem Reset starten.
3. Die Taste während des Verbindungsaufbaus gedrückt halten.
4. Nach Beginn des Schreibvorgangs kann die Taste losgelassen werden.
5. Nach dem Flashen den Adapter ohne gedrückte Taste neu verbinden, damit die
   Firmware normal startet.

Verwendeter direkter Upload:

```sh
esptool --chip esp8266 \
  --port /dev/cu.usbserial-AD025JRF \
  --baud 115200 \
  --before default-reset \
  --after hard-reset \
  write-flash 0x0 .pio/build/nodemcuv2/firmware.bin
```

Der erfolgreiche Vorgang erkannte den ESP8266EX mit der MAC-Adresse
`68:c6:3a:88:b4:ba`, schrieb 437.760 Bytes und bestätigte anschließend den
Flash-Hash.

Das Drücken der Taste beim Einschalten zieht sehr wahrscheinlich GPIO0 auf LOW
und aktiviert damit den ROM-Bootloader. Ohne gedrückte Taste startet die
Anwendungsfirmware.

(Auf der Platine Rev. 0.2/0.3 wählt stattdessen der Jumper J5 zwischen RUN
und FLASH – siehe [CIRCUIT.de.md](CIRCUIT.de.md), Abschnitt 10.)

## Diagnoseablauf bei erneutem Ausfall

1. Prüfen, ob `home/kitchen/hood/$online` auf `false` gewechselt ist.
2. Nach `HoodControl-Setup` suchen und gegebenenfalls `192.168.4.1` öffnen.
3. In Pi-hole oder dem DHCP-Server nach der MAC-Adresse
   `68:c6:3a:88:b4:ba` suchen.
4. MQTT-Topics `$wifi_rssi`, `$last_error`, `$reset_reason`, `diagnostics` und
   `events` prüfen.
5. Bei vorhandenem USB-Zugang den seriellen Monitor mit 115200 Baud öffnen.
6. Wenn der USB-Seriell-Port sichtbar ist, aber auch der ESP-ROM-Bootloader
   keinerlei Daten sendet, Versorgung, Reset- und Boot-Pins prüfen.

## Elektrische Prüfung

Falls das Gerät nur über USB, aber nicht in der Haube zuverlässig arbeitet,
gegen GND messen:

| Pin | Erwarteter Pegel |
| --- | --- |
| VCC | etwa 3,3 V |
| EN/CH_PD | HIGH, etwa 3,3 V |
| RST | HIGH, etwa 3,3 V |
| GPIO0 | HIGH beim normalen Start |
| GPIO2 | HIGH beim normalen Start |
| GPIO15 | LOW beim normalen Start |

Spannungseinbrüche während WLAN-Sendeimpulsen sind ebenfalls relevant. Die
Firmware verwendet maximale WLAN-Sendeleistung und deaktiviert den
WLAN-Schlafmodus; dadurch ist eine stabile Stromversorgung besonders wichtig.

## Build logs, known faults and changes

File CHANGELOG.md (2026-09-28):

🇬🇧 **English** · 🇩🇪 [Deutsch](CHANGELOG.de.md)

# Changelog

All notable changes to the firmware are recorded in this document.

## 0.0.10 - 2026-09-28

### Changed

- The configuration hotspot password and the default MQTT broker are no
  longer hard-coded personal values. Defaults are `hoodcontrol` and
  `mqtt.local`; override them via the `PORTAL_PASSWORD` and `MQTT_HOST`
  build flags, see [`docs/OPERATIONS.md`](docs/OPERATIONS.md).
- Firmware is now licensed under MIT.

## 0.0.9 - 2026-09-26

Adaptation to the fabricated PCB (rev. 0.3), see
[`docs/CIRCUIT.md`](docs/CIRCUIT.md).

### Changed

- The key outputs GPIO12/14 are now always actively driven:
  HIGH = press, LOW = release. Previously they were switched to
  high-impedance to release, which leaves the inputs of level shifter U3
  floating and produces phantom key presses.
- GPIO12/14 are set LOW right at the start of `setup()`.
- LED pins (`ledPin1/2`) and key pins (`buttonPin1/2`) swapped – both
  channel pairs arrive swapped on the PCB compared to the perfboard version.

### Fixed

- Home Assistant discovery of the fan: `state_value_template` returned
  `on`/`off`, but Home Assistant compares the result against
  `payload_on`/`payload_off` (`1`/`0`), so the fan was permanently
  `unknown`. The template now returns `1`/`0`.
- Fan level `0` is reported as preset `None` and resets the preset instead
  of being discarded as an invalid preset.

## 0.0.8 - 2026-09-08

### Added

- Status LED on GPIO2 (D4, blue on-board LED of the ESP-12, active LOW).
  The blink pattern shows the boot and connection phase without a serial
  console: three short flashes at power-up, fast blinking while joining
  Wi-Fi, medium blinking while connecting to MQTT, slow blinking while the
  configuration portal is open, and a short heartbeat every three seconds
  once both are up.

## 0.0.7 - 2026-08-16

### Added

- Non-blocking Wi-Fi start with the hood control running in parallel.
- Password-protected fallback hotspot `HoodControl-Setup`.
- Configuration portal at `http://192.168.4.1`.
- Periodic Wi-Fi reconnection attempts in AP+STA mode.
- Unique MQTT client ID from device name and ESP8266 chip ID.
- MQTT diagnostics under `diagnostics`, `$wifi_rssi`, `$uptime`,
  `$reset_reason`, `$firmware`, `$ip` and `$last_error`.
- Buffered connection events under the MQTT topic `events`.
- Persistent boot stage for diagnosing incomplete start-ups.
- Wi-Fi, MQTT and error counters.
- Full republish of all hood states after an MQTT reconnect.

### Changed

- MQTT reconnects use exponential backoff up to five minutes.
- MQTT socket timeout reduced to three seconds.
- MQTT commands are subscribed with QoS 1.
- The fallback hotspot is switched off after one minute of stable Wi-Fi.
- Configuration changes trigger a controlled restart after a successful save.
- Errors reading or writing the configuration, and publish/subscribe
  errors, are logged visibly.

### Fixed

- A failed Wi-Fi start can no longer lock the firmware permanently in the
  blocking WiFiManager portal.
- State changes during an MQTT outage are resynchronised after reconnecting.
- A fixed MQTT client ID can no longer collide with a second installation of
  the same name.

### Validation

- Successful build for `nodemcuv2` and `nodemcuv2-ota`.
- RAM: 35,892 of 81,920 bytes (43.8 %).
- Flash: 433,608 of 1,044,464 bytes (41.5 %).
- Firmware written over USB and verified against the flash hash.

## 0.0.6 - 2026-07-14

- Wi-Fi auto-reconnect enabled.
- Maximum Wi-Fi transmit power set.
- Wi-Fi sleep mode disabled.
- Active Wi-Fi check added; MQTT connection attempts only while Wi-Fi is up.

## 0.0.5

- Firmware migrated to PlatformIO.
- Homie replaced by WiFiManager and PubSubClient.
- Home Assistant MQTT discovery added.
- Fan presets, light entity and OTA support added.

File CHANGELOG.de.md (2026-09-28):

🇬🇧 [English](CHANGELOG.md) · 🇩🇪 **Deutsch**

# Changelog

Alle wesentlichen Änderungen an der Firmware werden in diesem Dokument
festgehalten.

## 0.0.10 - 2026-09-28

### Geändert

- Passwort des Konfigurations-Hotspots und Standard-MQTT-Broker sind keine
  fest eingetragenen persönlichen Werte mehr. Standard sind `hoodcontrol`
  und `mqtt.local`; überschreibbar über die Build-Flags `PORTAL_PASSWORD`
  und `MQTT_HOST`, siehe [`docs/OPERATIONS.de.md`](docs/OPERATIONS.de.md).
- Die Firmware steht jetzt unter der MIT-Lizenz.

## 0.0.9 - 2026-09-26

Anpassung an die gefertigte Platine (Rev. 0.3), siehe [`docs/CIRCUIT.de.md`](docs/CIRCUIT.de.md).

### Geändert

- Die Tasten-Ausgänge GPIO12/14 werden jetzt immer aktiv getrieben:
  HIGH = Taste drücken, LOW = loslassen. Früher wurden sie zum Loslassen
  hochohmig geschaltet; das lässt die Eingänge des Pegelwandlers U3 floaten
  und erzeugt Phantom-Tastendrücke.
- GPIO12/14 werden gleich zu Beginn von `setup()` auf LOW gesetzt.
- LED-Pins (`ledPin1/2`) und Tasten-Pins (`buttonPin1/2`) getauscht – beide
  Kanalpaare kommen auf der Platine gegenüber der Lochraster-Version
  vertauscht an.

### Behoben

- Home-Assistant-Discovery der Lüftung: `state_value_template` lieferte
  `on`/`off`, Home Assistant vergleicht das Ergebnis aber mit
  `payload_on`/`payload_off` (`1`/`0`). Die Lüftung stand deshalb dauerhaft
  auf `unknown`. Das Template liefert jetzt `1`/`0`.
- Lüftungsstufe `0` wird als Preset `None` gemeldet und setzt das Preset
  zurück, statt als ungültiges Preset verworfen zu werden.

## 0.0.8 - 2026-09-08

### Hinzugefügt

- Status-LED auf GPIO2 (D4, blaue Onboard-LED des ESP-12, aktiv LOW).
  Das Blinkmuster zeigt die Boot- und Verbindungsphase ohne serielle
  Konsole an: drei kurze Blitze beim Einschalten, schnelles Blinken
  während der WLAN-Anmeldung, mittleres Blinken beim MQTT-Verbinden,
  langsames Blinken bei geöffnetem Konfigurationsportal und ein kurzer
  Heartbeat alle drei Sekunden, sobald beides steht.

## 0.0.7 - 2026-08-16

### Hinzugefügt

- Nicht blockierender WLAN-Start mit paralleler Haubensteuerung.
- Geschützter Fallback-Hotspot `HoodControl-Setup`.
- Konfigurationsportal unter `http://192.168.4.1`.
- Regelmäßige WLAN-Wiederverbindungsversuche im AP+STA-Betrieb.
- Eindeutige MQTT-Client-ID aus Gerätename und ESP8266-Chip-ID.
- MQTT-Diagnose unter `diagnostics`, `$wifi_rssi`, `$uptime`,
  `$reset_reason`, `$firmware`, `$ip` und `$last_error`.
- Gepufferte Verbindungsereignisse unter dem MQTT-Topic `events`.
- Persistente Bootphase zur Diagnose unvollständiger Startvorgänge.
- WLAN-, MQTT- und Fehlerzähler.
- Vollständige Neuübertragung aller Haubenzustände nach MQTT-Reconnect.

### Geändert

- MQTT-Wiederverbindungen verwenden exponentielles Backoff bis fünf Minuten.
- MQTT-Sockettimeout wurde auf drei Sekunden reduziert.
- MQTT-Befehle werden mit QoS 1 abonniert.
- Der Fallback-Hotspot wird nach einer Minute stabiler WLAN-Verbindung
  abgeschaltet.
- Konfigurationsänderungen führen nach erfolgreichem Speichern zu einem
  kontrollierten Neustart.
- Fehler beim Lesen oder Schreiben der Konfiguration sowie beim Publizieren
  und Abonnieren werden sichtbar protokolliert.

### Behoben

- Ein fehlgeschlagener WLAN-Start kann die Firmware nicht mehr dauerhaft im
  blockierenden WiFiManager-Portal festsetzen.
- Zustandsänderungen während einer MQTT-Unterbrechung werden nach dem
  Wiederverbinden erneut synchronisiert.
- Eine feste MQTT-Client-ID kann nicht mehr mit einer zweiten gleichnamigen
  Installation kollidieren.

### Validierung

- Erfolgreicher Build für `nodemcuv2` und `nodemcuv2-ota`.
- RAM: 35.892 von 81.920 Bytes (43,8 %).
- Flash: 433.608 von 1.044.464 Bytes (41,5 %).
- Firmware erfolgreich per USB geschrieben und anhand des Flash-Hashes
  verifiziert.

## 0.0.6 - 2026-07-14

- WLAN-Auto-Reconnect aktiviert.
- Maximale WLAN-Sendeleistung eingestellt.
- WLAN-Schlafmodus deaktiviert.
- Aktive WLAN-Prüfung und MQTT-Verbindungsversuche nur bei bestehender
  WLAN-Verbindung ergänzt.

## 0.0.5

- Firmware zu PlatformIO migriert.
- Homie durch WiFiManager und PubSubClient ersetzt.
- Home-Assistant-MQTT-Discovery ergänzt.
- Lüfter-Presets, Licht-Entity und OTA-Unterstützung ergänzt.

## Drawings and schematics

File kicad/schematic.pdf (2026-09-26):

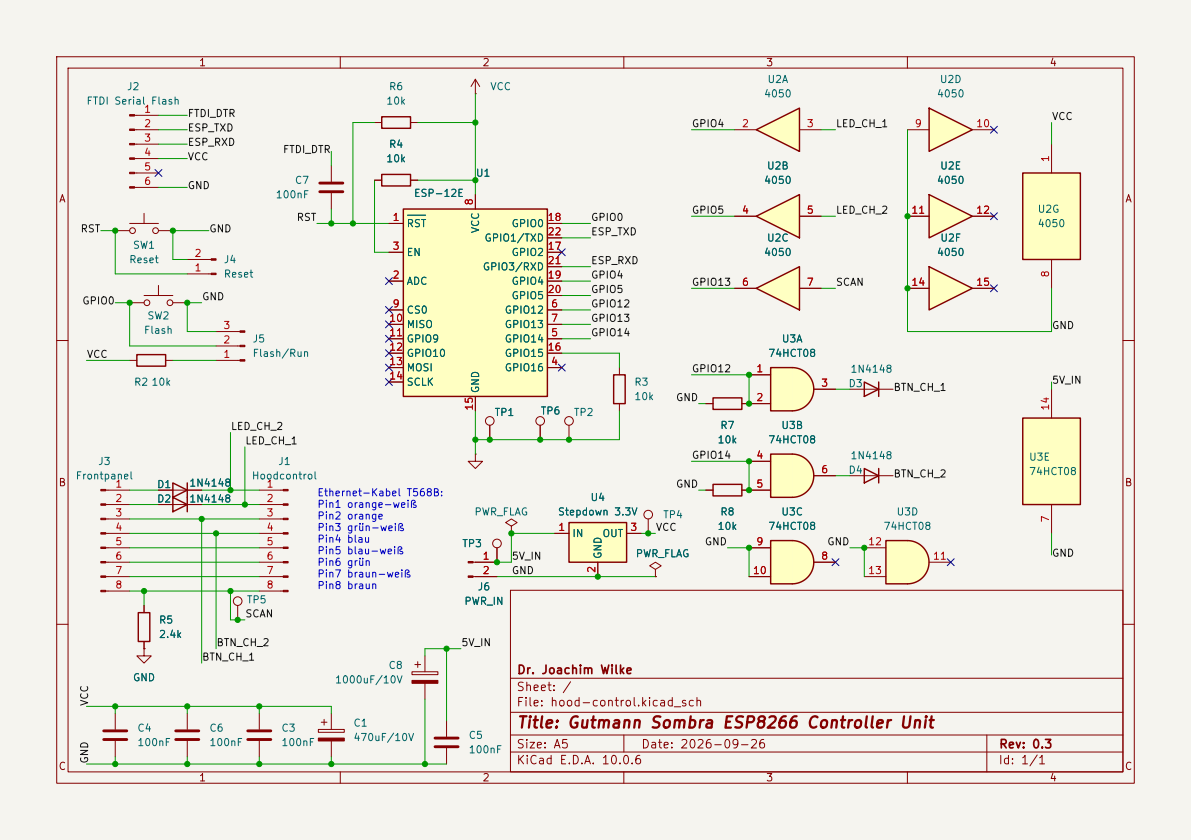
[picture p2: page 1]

FTDI Serial Flash GND

Ethernet-Kabel T568B: Pin1 orange-weiß

Dr. Joachim Wilke
Sheet: /
File: hood-control.kicad_sch
Title: Gutmann Sombra ESP8266 Controller Unit

Size: A5 | Rev: 0.3 | C Date: 2026-09-26
KiCad E.D.A. 10.0.6 | Id: 1/1

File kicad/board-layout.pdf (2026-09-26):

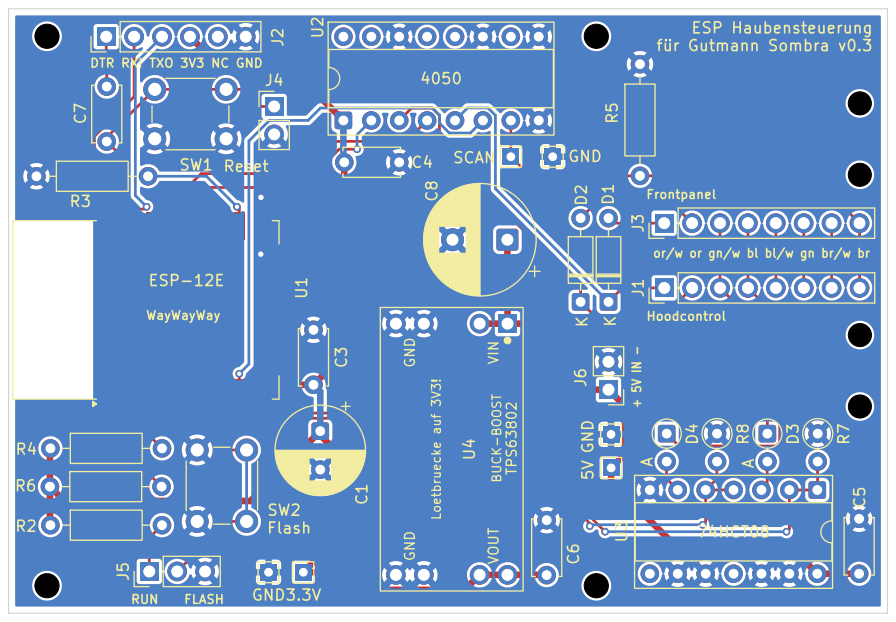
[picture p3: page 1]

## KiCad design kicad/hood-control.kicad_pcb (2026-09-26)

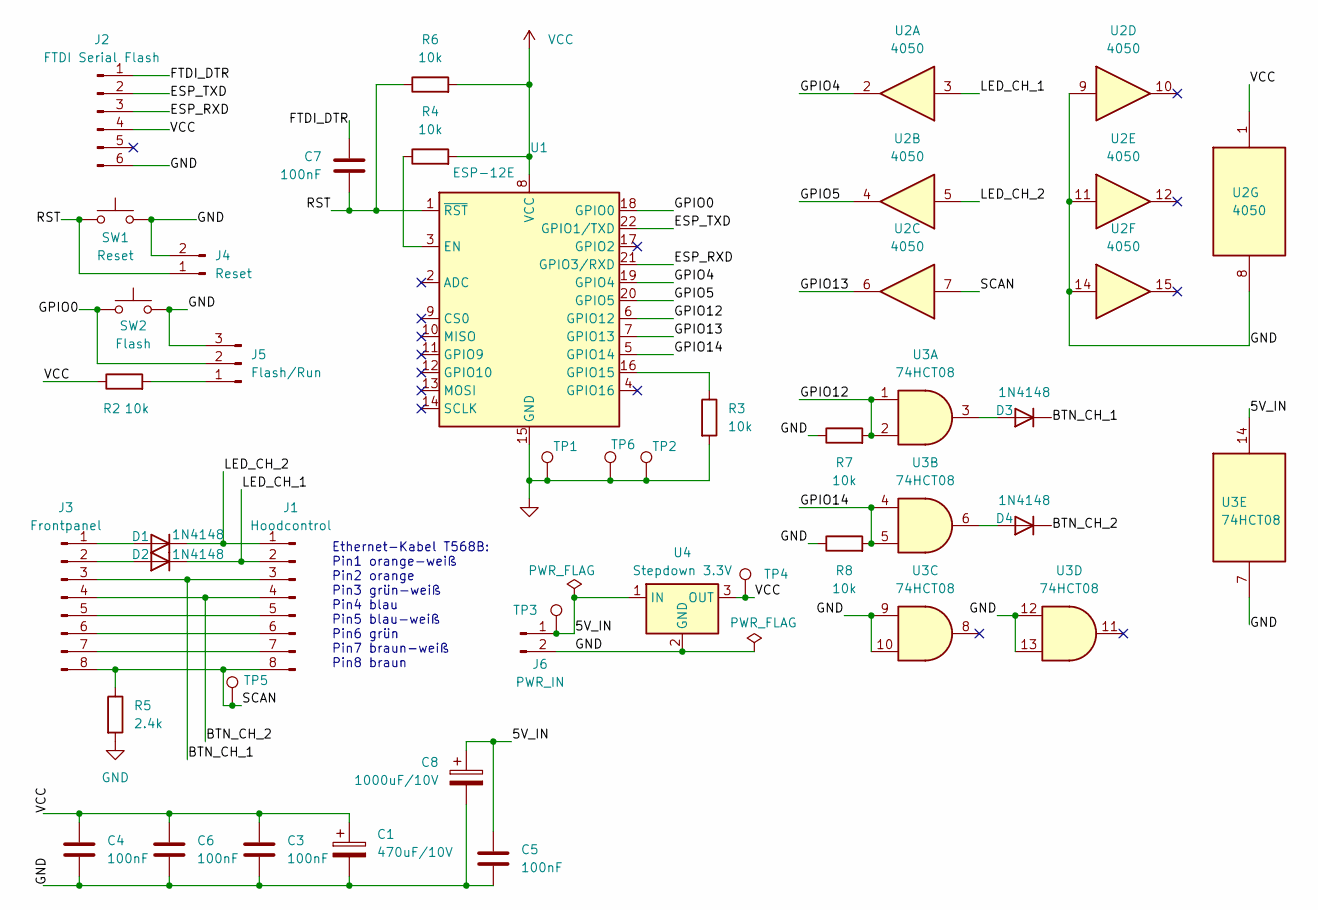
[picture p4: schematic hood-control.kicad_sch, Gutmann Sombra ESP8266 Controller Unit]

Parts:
C1: 470uF/10V; CP_Radial_D8.0mm_P3.50mm
C3, C4, C5, C6, C7: 100nF; C_Disc_D5.0mm_W2.5mm_P5.00mm
C8: 1000uF/10V; CP_Radial_D10.0mm_P5.00mm
D1, D2: 1N4148; D_DO-35_SOD27_P7.62mm_Horizontal
D3, D4: 1N4148; D_DO-35_SOD27_P2.54mm_Vertical_AnodeUp
J1: Hoodcontrol; PinHeader_1x08_P2.54mm_Vertical
J2: FTDI Serial Flash; PinHeader_1x06_P2.54mm_Vertical
J3: Frontpanel; PinHeader_1x08_P2.54mm_Vertical
J4: Reset; PinHeader_1x02_P2.54mm_Vertical
J5: Flash/Run; PinHeader_1x03_P2.54mm_Vertical
J6: PWR_IN; PinHeader_1x02_P2.54mm_Vertical
R2, R3, R4, R6: 10k; R_Axial_DIN0207_L6.3mm_D2.5mm_P10.16mm_Horizontal
R5: 2.4k; R_Axial_DIN0207_L6.3mm_D2.5mm_P10.16mm_Horizontal
R7, R8: 10k; R_Axial_DIN0207_L6.3mm_D2.5mm_P2.54mm_Vertical
SW1: Reset; SW_PUSH_6mm
SW2: Flash; SW_PUSH_6mm
TP1, TP2, TP6: GND; TestPoint_THTPad_1.5x1.5mm_Drill0.7mm
TP3: 5V; TestPoint_THTPad_1.5x1.5mm_Drill0.7mm
TP4: 3.3V; TestPoint_THTPad_1.5x1.5mm_Drill0.7mm
TP5: SCAN; TestPoint_THTPad_1.5x1.5mm_Drill0.7mm
U1: ESP-12E
U2: 4050; DIP-16_W7.62mm_Socket
U3: 74HCT08; DIP-14_W7.62mm_Socket
U4: Stepdown 3.3V; TPS63802_Module_25.8x13.0mm

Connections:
/5V_IN: C5.1, C8.1, J6.1, TP3.1 (1_1), U3.14 (VCC), U4.1 (IN)
/BTN_CH_1: D3.1 (K), J1.3, J3.3
/BTN_CH_2: D4.1 (K), J1.4, J3.4
/ESP_RXD: J2.3, U1.21 (GPIO3/RXD)
/ESP_TXD: J2.2, U1.22 (GPIO1/TXD)
/FTDI_DTR: C7.1, J2.1
/GPIO0: J5.2, SW2.1, U1.18 (GPIO0)
/GPIO4: U1.19 (GPIO4), U2.2
/GPIO5: U1.20 (GPIO5), U2.4
/GPIO12: R7.2, U1.6 (GPIO12), U3.1, U3.2
/GPIO13: U1.7 (GPIO13), U2.6
/GPIO14: R8.2, U1.5 (GPIO14), U3.4, U3.5
/LED_CH_1: D2.1 (K), J1.2, U2.3
/LED_CH_2: D1.1 (K), J1.1, U2.5
/RST: C7.2, J4.1, R6.1, SW1.1, U1.1 (~RST)
/SCAN: J1.8, J3.8, R5.1, TP5.1 (1_1), U2.7
GND: C1.2, C3.2, C4.2, C5.2, C6.2, C8.2, J2.6, J4.2, J5.3, J6.2, R3.2, R5.2, R7.1, R8.1, SW1.2, SW2.2, TP1.1 (1_1), TP2.1 (1_1), TP6.1 (1_1), U1.15 (GND), U2.8 (VSS), U2.9, U2.11, U2.14, U3.7 (GND), U3.9, U3.10, U3.12, U3.13, U4.2 (GND)
unnamed: D1.2 (A), J3.1
unnamed: D2.2 (A), J3.2
unnamed: D3.2 (A), U3.3
unnamed: D4.2 (A), U3.6
unnamed: J1.5, J3.5
unnamed: J1.6, J3.6
unnamed: J1.7, J3.7
unnamed: J5.1, R2.2
unnamed: R4.1, U1.3 (EN)
unnamed: R3.1, U1.16 (GPIO15)
VCC: C1.1, C3.1, C4.1, C6.1, J2.4, R2.1, R4.2, R6.2, TP4.1 (1_1), U1.8 (VCC), U2.1 (VCC), U4.3 (OUT)

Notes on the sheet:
Ethernet-Kabel T568B: Pin1 orange-weiß Pin2 orange Pin3 grün-weiß Pin4 blau Pin5 blau-weiß Pin6 grün Pin7 braun-weiß Pin8 braun

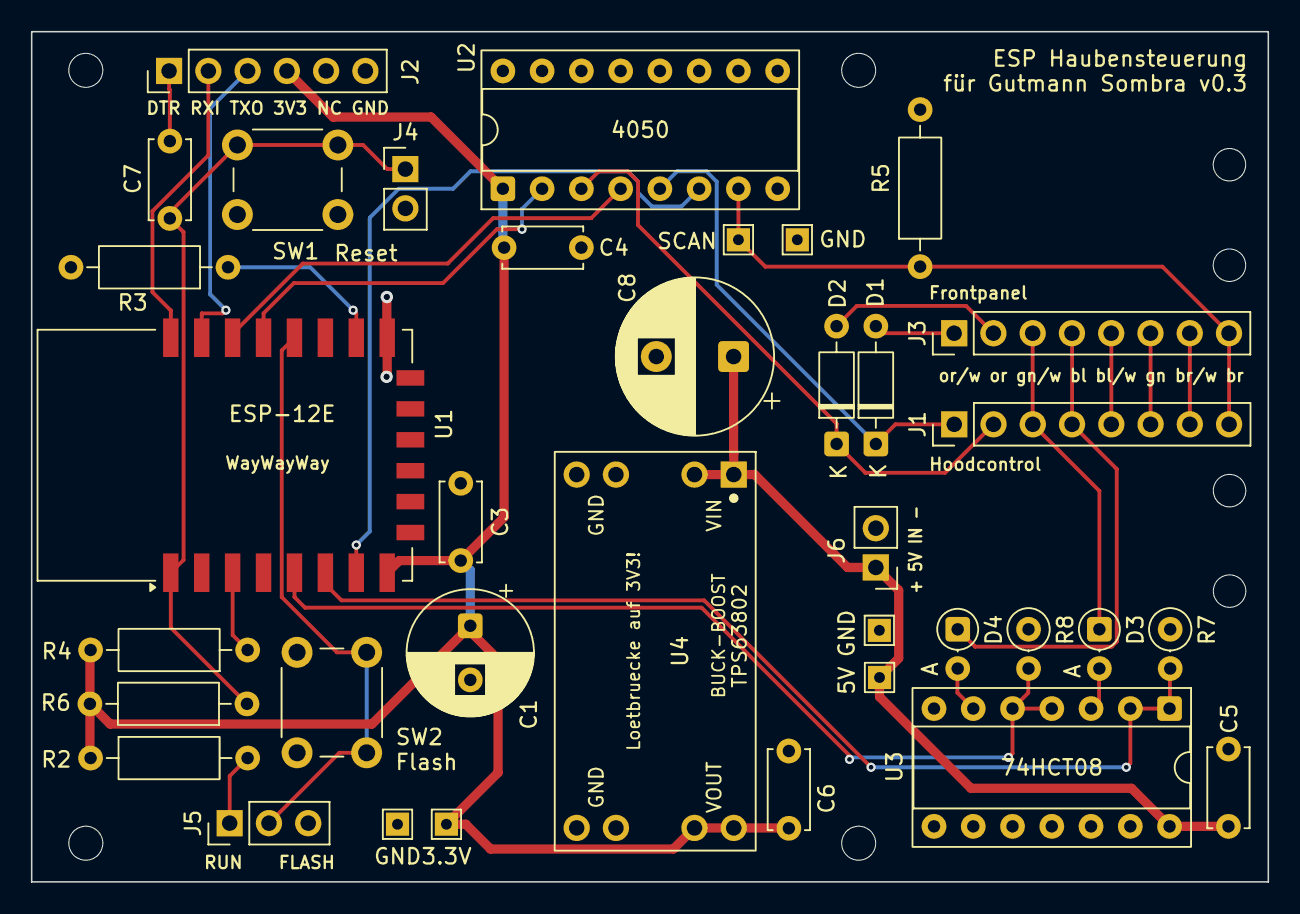
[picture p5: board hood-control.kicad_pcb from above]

Board: 2 copper layers, 80.0 x 55.0 mm, 44 parts (0 on the bottom side), 28 nets.

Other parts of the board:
H1, H2, H3, H4: MountingHole_2.1mm
MH1, MH2, MH3, MH4: MountingHole_2.2mm_M2

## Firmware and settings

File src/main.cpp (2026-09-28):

#include <Arduino.h>
#include <ESP8266WiFi.h>
#include <WiFiManager.h>
#include <PubSubClient.h>
#include <ArduinoOTA.h>
#include <LittleFS.h>
#include <ArduinoJson.h>

#define FW_NAME    "HoodControl"
#define FW_VERSION "0.0.10"

const char* const CONFIG_PORTAL_SSID     = FW_NAME "-Setup";
// Override both via build_flags, see docs/OPERATIONS.md
#ifndef PORTAL_PASSWORD
#define PORTAL_PASSWORD "hoodcontrol"  // at least 8 characters
#endif
#ifndef MQTT_HOST
#define MQTT_HOST "mqtt.local"
#endif

const char* const CONFIG_PORTAL_PASSWORD = PORTAL_PASSWORD;
const unsigned long WIFI_RETRY_INTERVAL  = 10000;
const unsigned long PORTAL_RETRY_INTERVAL = 30000;
const unsigned long PORTAL_START_DELAY   = 20000;
const unsigned long PORTAL_CLOSE_DELAY   = 60000;
const unsigned long DIAGNOSTICS_INTERVAL = 60000;
const unsigned long STATE_RETRY_INTERVAL = 5000;
const unsigned long MQTT_RETRY_MIN       = 5000;
const unsigned long MQTT_RETRY_MAX       = 300000;
const size_t EVENT_LOG_SIZE              = 16;
const size_t EVENT_LENGTH                 = 80;

// Pins
const int inputPin    = 13; // D7
const int buttonPin1  = 14; // D5 - swapped like the LED pins, see below
const int buttonPin2  = 12; // D6
const int ledPin1     =  4; // D2 - swapped vs. the perfboard: on the PCB, J1/1+2 arrive the other way round
const int ledPin2     =  5; // D1
const int statusLedPin =  2; // D4, onboard blue LED (ESP-12), active LOW

// MQTT config (defaults, overridden by stored config)
char mqtt_host[64]   = MQTT_HOST;
char mqtt_port[6]    = "1883";
char mqtt_prefix[64] = "home/kitchen/hood";
char device_name[32] = "hood-control";

// ISR state
volatile boolean ledStates[8];
volatile int resync;
volatile int ledStateCounter[8];
volatile int buttonStateCounter[8];
volatile unsigned long lastIsr = 0;
volatile unsigned long phaseCounter = 0;

WiFiClient   wifiClient;
PubSubClient mqtt(wifiClient);
WiFiManager  wifiManager;

WiFiManagerParameter p_host  ("mqtt_host",   "MQTT Host",   mqtt_host,   64);
WiFiManagerParameter p_port  ("mqtt_port",   "MQTT Port",   mqtt_port,    6);
WiFiManagerParameter p_prefix("mqtt_prefix", "MQTT Prefix", mqtt_prefix, 64);
WiFiManagerParameter p_name  ("device_name", "Device Name", device_name, 32);

char mqttClientId[48];
char previousBootStage[32] = "unknown";
char lastError[80] = "none";
char eventLog[EVENT_LOG_SIZE][EVENT_LENGTH];
size_t eventLogStart = 0;
size_t eventLogCount = 0;
unsigned long wifiReconnects = 0;
unsigned long mqttReconnects = 0;
unsigned long mqttFailures = 0;
unsigned long mqttRetryInterval = MQTT_RETRY_MIN;
unsigned long disconnectedSince = 0;
unsigned long wifiConnectedSince = 0;
unsigned long lastWifiAttempt = 0;
unsigned long lastMqttAttempt = 0;
unsigned long lastDiagnostics = 0;
unsigned long lastStateAttempt = 0;
unsigned long configSavedAt = 0;
bool wasWifiConnected = false;
bool wasMqttConnected = false;
bool stateSyncPending = true;
bool discoveryPending = true;

// Forward declarations
void checkButtons(int line);
void updateButtonState(int buttonId, int buttonPin);
void checkLeds(int line);
void updateLedStateCounter(int ledId, int ledPinState);
void mqttReconnect();
bool publishState(int i);
bool publishAllStates();
bool publishDiagnostics();
void publishEventLog();
void processNetwork();
void startConfigPortal();
void addEvent(const char* message);
void setLastError(const char* message);
void loadPreviousBootStage();
void recordBootStage(const char* stage);
void saveConfig();
void loadConfig();
void setStatusLed(bool on);
void updateStatusLed();

// ---- ISR functions (unchanged) ----

ICACHE_RAM_ATTR void IsrResync() {
	if (++resync > 10) {
		unsigned long now = micros();
		if ((now - lastIsr) > 3900 && (now - lastIsr) < 4100) {
			phaseCounter = 1;
			resync = 0;
			timer1_disable();
			timer1_enable(TIM_DIV16, TIM_EDGE, TIM_LOOP);
			timer1_write((clockCyclesPerMicrosecond() / 16) * 100);
		}
		lastIsr = micros();
	}
}

ICACHE_RAM_ATTR void IsrTimer() {
	switch (phaseCounter % 40) {
	case 1:  checkButtons(1); break;
	case 5:  checkLeds(1);    break;
	case 11: checkButtons(2); break;
	case 15: checkLeds(2);    break;
	case 21: checkButtons(4); break;
	case 25: checkLeds(4);    break;
	case 31: checkButtons(3); break;
	case 35: checkLeds(3);    break;
	case 9: case 19: case 29: case 39:
		// Release: drive LOW. U3 (74HCT08) sits between ESP and hood; a
		// floating HCT input would make it press keys at random. The diode
		// behind U3 blocks LOW, so the hood's line is left alone.
		digitalWrite(buttonPin1, LOW);
		digitalWrite(buttonPin2, LOW);
		break;
	}
	phaseCounter++;
}

ICACHE_RAM_ATTR void checkButtons(int line) {
	switch (line) {
	case 1: updateButtonState(2, buttonPin1); updateButtonState(6, buttonPin2); break;
	case 2: updateButtonState(3, buttonPin1); updateButtonState(7, buttonPin2); break;
	case 3: updateButtonState(1, buttonPin1); updateButtonState(5, buttonPin2); break;
	case 4: updateButtonState(4, buttonPin1); break;
	}
}

ICACHE_RAM_ATTR void updateButtonState(int buttonId, int buttonPin) {
	if (buttonStateCounter[buttonId] > 0) {
		digitalWrite(buttonPin, HIGH);
		buttonStateCounter[buttonId]--;
	}
}

ICACHE_RAM_ATTR void checkLeds(int line) {
	int s1 = digitalRead(ledPin1);
	int s2 = digitalRead(ledPin2);
	switch (line) {
	case 1: updateLedStateCounter(2, s1); updateLedStateCounter(6, s2); break;
	case 2: updateLedStateCounter(3, s1); updateLedStateCounter(7, s2); break;
	case 3: updateLedStateCounter(1, s1); updateLedStateCounter(5, s2); break;
	case 4: updateLedStateCounter(4, s1); break;
	}
}

ICACHE_RAM_ATTR void updateLedStateCounter(int ledId, int ledPinState) {
	if (ledStates[ledId] == ledPinState) ledStateCounter[ledId]++;
	else ledStateCounter[ledId] = 0;
}

// ---- Config (LittleFS + ArduinoJson) ----

void saveConfig() {
	JsonDocument doc;
	doc["mqtt_host"]   = mqtt_host;
	doc["mqtt_port"]   = mqtt_port;
	doc["mqtt_prefix"] = mqtt_prefix;
	doc["device_name"] = device_name;
	File f = LittleFS.open("/config.json", "w");
	if (!f) {
		setLastError("Unable to open config.json for writing");
		return;
	}
	if (serializeJson(doc, f) == 0) setLastError("Unable to write config.json");
	f.close();
}

void loadConfig() {
	if (!LittleFS.exists("/config.json")) return;
	File f = LittleFS.open("/config.json", "r");
	if (!f) {
		setLastError("Unable to open config.json");
		return;
	}
	JsonDocument doc;
	if (deserializeJson(doc, f) == DeserializationError::Ok) {
		strlcpy(mqtt_host,   doc["mqtt_host"]   | mqtt_host,   sizeof(mqtt_host));
		strlcpy(mqtt_port,   doc["mqtt_port"]   | mqtt_port,   sizeof(mqtt_port));
		strlcpy(mqtt_prefix, doc["mqtt_prefix"] | mqtt_prefix, sizeof(mqtt_prefix));
		strlcpy(device_name, doc["device_name"] | device_name, sizeof(device_name));
	} else setLastError("Invalid config.json");
	f.close();
}

void loadPreviousBootStage() {
	if (!LittleFS.exists("/boot-stage.txt")) return;
	File f = LittleFS.open("/boot-stage.txt", "r");
	if (!f) return;
	size_t length = f.readBytes(previousBootStage, sizeof(previousBootStage) - 1);
	previousBootStage[length] = '\0';
	f.close();
}

void recordBootStage(const char* stage) {
	File f = LittleFS.open("/boot-stage.txt", "w");
	if (!f) {
		setLastError("Unable to persist boot stage");
		return;
	}
	f.print(stage);
	f.close();
}

// ---- Status LED (onboard blue LED, GPIO2/D4, active LOW) ----
//
// Blink pattern shows what boot/connection stage we're in; once WiFi+MQTT
// are both up it goes mostly dark with a brief periodic "heartbeat" blip
// so a glance confirms the device is alive without being distracting.

void setStatusLed(bool on) {
	digitalWrite(statusLedPin, on ? LOW : HIGH);
}

void updateStatusLed() {
	unsigned long onMs, offMs;

	if (wifiManager.getConfigPortalActive()) {
		onMs = 1000; offMs = 1000;               // slow blink: waiting for setup
	} else if (WiFi.status() != WL_CONNECTED) {
		onMs = 150;  offMs = 150;                 // fast blink: connecting to WiFi
	} else if (!mqtt.connected()) {
		onMs = 400;  offMs = 400;                 // medium blink: connecting to MQTT
	} else {
		onMs = 40;   offMs = 2960;                // heartbeat: everything is fine
	}

	static bool ledOn = false;
	static unsigned long lastToggle = 0;
	unsigned long now = millis();
	if (now - lastToggle >= (ledOn ? onMs : offMs)) {
		ledOn = !ledOn;
		lastToggle = now;
		setStatusLed(ledOn);
	}
}

void setLastError(const char* message) {
	strlcpy(lastError, message, sizeof(lastError));
	Serial.printf("ERROR: %s\n", lastError);
	addEvent(lastError);
}

void addEvent(const char* message) {
	size_t index = (eventLogStart + eventLogCount) % EVENT_LOG_SIZE;
	if (eventLogCount == EVENT_LOG_SIZE) {
		eventLogStart = (eventLogStart + 1) % EVENT_LOG_SIZE;
		index = (eventLogStart + eventLogCount - 1) % EVENT_LOG_SIZE;
	} else {
		eventLogCount++;
	}
	snprintf(eventLog[index], EVENT_LENGTH, "%lus: %s", millis() / 1000, message);
	Serial.println(eventLog[index]);
}

// ---- MQTT ----

void mqttCallback(char* topic, byte* payload, unsigned int length) {
	String t   = String(topic);
	String msg = "";
	for (unsigned int i = 0; i < length; i++) msg += (char)payload[i];
	String prefix = String(mqtt_prefix);

	if (t == prefix + "/ventilation/set") {
		long id = msg.toInt();
		if (id >= 1 && id <= 4) buttonStateCounter[id] = 100;
		if (id == 0) for (int i = 1; i <= 4; i++) if (ledStates[i]) buttonStateCounter[i] = 100;
	} else if (t == prefix + "/light/set") {
		if ((msg == "false" && ledStates[6]) || (msg == "true" && !ledStates[6]))
			buttonStateCounter[6] = 100;
	} else if (t == prefix + "/timer/set") {
		if ((msg == "false" && ledStates[5]) || (msg == "true" && !ledStates[5]))
			buttonStateCounter[5] = 100;
	} else if (t == prefix + "/maintenance/set") {
		if (ledStates[7]) buttonStateCounter[7] = 1500;
	}
}

bool publishState(int i) {
	if (!mqtt.connected()) {
		stateSyncPending = true;
		return false;
	}
	String prefix = String(mqtt_prefix);
	bool published = false;
	switch (i) {
	case 1: case 2: case 3: case 4: {
		String v = ledStates[1] ? "1" : ledStates[2] ? "2" : ledStates[3] ? "3" : ledStates[4] ? "4" : "0";
		published = mqtt.publish((prefix + "/ventilation/state").c_str(), v.c_str(), true);
		Serial.printf("ventilation: %s\n", v.c_str());
		break;
	}
	case 5:
		published = mqtt.publish((prefix + "/timer/state").c_str(), ledStates[5] ? "true" : "false", true);
		Serial.printf("timer: %s\n", ledStates[5] ? "true" : "false");
		break;
	case 6:
		published = mqtt.publish((prefix + "/light/state").c_str(), ledStates[6] ? "true" : "false", true);
		Serial.printf("light: %s\n", ledStates[6] ? "true" : "false");
		break;
	case 7:
		published = mqtt.publish((prefix + "/maintenance/state").c_str(), ledStates[7] ? "true" : "false", true);
		Serial.printf("maintenance: %s\n", ledStates[7] ? "true" : "false");
		break;
	}
	if (!published) {
		stateSyncPending = true;
		setLastError("MQTT state publish failed");
	}
	return published;
}

bool publishAllStates() {
	bool success = publishState(1);
	for (int i = 5; i <= 7; i++) success = publishState(i) && success;
	stateSyncPending = !success;
	return success;
}

void publishDiscovery() {
	String prefix = String(mqtt_prefix);
	String dev_id = String(device_name);

	// Device-Block als gemeinsame Basis
	auto addDevice = [&](JsonDocument& doc) {
		JsonObject dev = doc["device"].to<JsonObject>();
		dev["identifiers"][0] = dev_id;
		dev["name"]           = "Abzugshaube";
		dev["model"]          = "DIY ESP8266";
		dev["manufacturer"]   = "Joachim Wilke";
		dev["sw_version"]     = FW_VERSION;
	};

	// Availability topic (online/offline)
	String avail = prefix + "/$online";

	// Helper: publish one discovery config
	bool success = true;
	auto publish = [&](const char* component, const char* obj_id, JsonDocument& doc) {
		String topic = "homeassistant/";
		topic += component;
		topic += "/";
		topic += dev_id + "_" + obj_id;
		topic += "/config";
		String payload;
		serializeJson(doc, payload);
		success = mqtt.publish(topic.c_str(), payload.c_str(), true) && success;
	};

	// --- Ventilation (fan mit preset modes: off/1/2/3/4) ---
	{
		JsonDocument doc;
		doc["name"]                    = "Lüftung";
		doc["unique_id"]               = dev_id + "_ventilation";
		// State: "0" = off, "1"-"4" = preset
		doc["state_topic"]             = prefix + "/ventilation/state";
		doc["command_topic"]           = prefix + "/ventilation/set";
		doc["payload_on"]              = "1";
		doc["payload_off"]             = "0";
		// Template muss payload_on/payload_off liefern, nicht "on"/"off"
		doc["state_value_template"]    = "{% if value == '0' %}0{% else %}1{% endif %}";
		doc["preset_mode_state_topic"] = prefix + "/ventilation/state";
		doc["preset_mode_command_topic"] = prefix + "/ventilation/set";
		// "0" ist kein Preset; "None" (payload_reset_preset_mode) setzt es zurück
		doc["preset_mode_value_template"] = "{% if value == '0' %}None{% else %}{{ value }}{% endif %}";
		doc["preset_modes"][0]         = "1";
		doc["preset_modes"][1]         = "2";
		doc["preset_modes"][2]         = "3";
		doc["preset_modes"][3]         = "4";
		doc["availability_topic"]      = avail;
		doc["payload_available"]       = "true";
		doc["payload_not_available"]   = "false";
		doc["icon"]                    = "mdi:air-filter";
		addDevice(doc);
		publish("fan", "ventilation", doc);
	}

	// --- Light (light entity) ---
	{
		JsonDocument doc;
		doc["name"]            = "Haubenlicht";
		doc["unique_id"]       = dev_id + "_light";
		doc["state_topic"]     = prefix + "/light/state";
		doc["command_topic"]   = prefix + "/light/set";
		doc["payload_on"]      = "true";
		doc["payload_off"]     = "false";
		doc["availability_topic"] = avail;
		doc["payload_available"]  = "true";
		doc["payload_not_available"] = "false";
		doc["icon"]            = "mdi:lightbulb";
		addDevice(doc);
		publish("light", "light", doc);
	}

	// --- Timer (switch) ---
	{
		JsonDocument doc;
		doc["name"]            = "Nachlauf-Timer";
		doc["unique_id"]       = dev_id + "_timer";
		doc["state_topic"]     = prefix + "/timer/state";
		doc["command_topic"]   = prefix + "/timer/set";
		doc["payload_on"]      = "true";
		doc["payload_off"]     = "false";
		doc["availability_topic"] = avail;
		doc["payload_available"]  = "true";
		doc["payload_not_available"] = "false";
		doc["icon"]            = "mdi:timer";
		addDevice(doc);
		publish("switch", "timer", doc);
	}

	// --- Maintenance (binary_sensor, read-only) ---
	{
		JsonDocument doc;
		doc["name"]              = "Filterreinigung";
		doc["unique_id"]         = dev_id + "_maintenance";
		doc["state_topic"]       = prefix + "/maintenance/state";
		doc["payload_on"]        = "true";
		doc["payload_off"]       = "false";
		doc["device_class"]      = "problem";
		doc["availability_topic"] = avail;
		doc["payload_available"]  = "true";
		doc["payload_not_available"] = "false";
		doc["icon"]              = "mdi:air-filter";
		addDevice(doc);
		publish("binary_sensor", "maintenance", doc);
	}

	discoveryPending = !success;
	if (success) Serial.println("HA discovery published");
	else setLastError("HA discovery publish failed");
}

void mqttReconnect() {
	String will = String(mqtt_prefix) + "/$online";
	if (mqtt.connect(mqttClientId, will.c_str(), 1, true, "false")) {
		bool onlinePublished = mqtt.publish(will.c_str(), "true", true);
		bool subscribed = mqtt.subscribe((String(mqtt_prefix) + "/+/set").c_str(), 1);
		if (!onlinePublished || !subscribed) {
			mqttFailures++;
			setLastError("MQTT initialization publish/subscribe failed");
			mqtt.disconnect();
			mqttRetryInterval = min(mqttRetryInterval * 2, MQTT_RETRY_MAX);
			return;
		}
		mqttReconnects++;
		mqttRetryInterval = MQTT_RETRY_MIN;
		stateSyncPending = true;
		discoveryPending = true;
		lastDiagnostics = millis() - DIAGNOSTICS_INTERVAL;
		addEvent("MQTT connected");
		Serial.printf("MQTT connected as %s\n", mqttClientId);
	} else {
		mqttFailures++;
		snprintf(lastError, sizeof(lastError), "MQTT connect failed, state=%d", mqtt.state());
		addEvent(lastError);
		mqttRetryInterval = min(mqttRetryInterval * 2, MQTT_RETRY_MAX);
	}
}

bool publishDiagnostics() {
	if (!mqtt.connected()) return false;
	JsonDocument doc;
	doc["firmware"] = FW_VERSION;
	doc["uptime_s"] = millis() / 1000;
	doc["rssi"] = WiFi.RSSI();
	doc["wifi_status"] = WiFi.status();
	doc["ip"] = WiFi.localIP().toString();
	doc["mqtt_state"] = mqtt.state();
	doc["wifi_reconnects"] = wifiReconnects;
	doc["mqtt_reconnects"] = mqttReconnects;
	doc["mqtt_failures"] = mqttFailures;
	doc["free_heap"] = ESP.getFreeHeap();
	doc["reset_reason"] = ESP.getResetReason();
	doc["previous_boot_stage"] = previousBootStage;
	doc["last_error"] = lastError;
	doc["portal_active"] = wifiManager.getConfigPortalActive();
	String payload;
	serializeJson(doc, payload);
	String prefix = String(mqtt_prefix);
	String uptime = String(millis() / 1000);
	String rssi = String(WiFi.RSSI());
	String ip = WiFi.localIP().toString();
	String resetReason = ESP.getResetReason();
	bool success = mqtt.publish((prefix + "/diagnostics").c_str(), payload.c_str(), true);
	success = mqtt.publish((prefix + "/$wifi_rssi").c_str(), rssi.c_str(), true) && success;
	success = mqtt.publish((prefix + "/$uptime").c_str(), uptime.c_str(), true) && success;
	success = mqtt.publish((prefix + "/$reset_reason").c_str(), resetReason.c_str(), true) && success;
	success = mqtt.publish((prefix + "/$firmware").c_str(), FW_VERSION, true) && success;
	success = mqtt.publish((prefix + "/$ip").c_str(), ip.c_str(), true) && success;
	success = mqtt.publish((prefix + "/$last_error").c_str(), lastError, true) && success;
	if (!success) setLastError("MQTT diagnostics publish failed");
	return success;
}

void publishEventLog() {
	while (mqtt.connected() && eventLogCount > 0) {
		if (!mqtt.publish((String(mqtt_prefix) + "/events").c_str(),
				eventLog[eventLogStart], false)) {
			setLastError("MQTT event publish failed");
			return;
		}
		eventLogStart = (eventLogStart + 1) % EVENT_LOG_SIZE;
		eventLogCount--;
	}
}

void startConfigPortal() {
	if (wifiManager.getConfigPortalActive()) return;
	addEvent("Starting protected config portal at 192.168.4.1");
	wifiManager.startConfigPortal(CONFIG_PORTAL_SSID, CONFIG_PORTAL_PASSWORD);

	// WiFiManager disables STA when it starts a portal without a connection.
	WiFi.mode(WIFI_AP_STA);
	WiFi.begin();
	lastWifiAttempt = millis();
}

void processNetwork() {
	unsigned long now = millis();
	bool connected = WiFi.status() == WL_CONNECTED;

	if (connected && !wasWifiConnected) {
		wifiConnectedSince = now;
		disconnectedSince = 0;
		mqttRetryInterval = MQTT_RETRY_MIN;
		lastMqttAttempt = now - MQTT_RETRY_MIN;
		addEvent("WiFi connected");
		Serial.printf("IP=%s RSSI=%d\n", WiFi.localIP().toString().c_str(), WiFi.RSSI());
		ArduinoOTA.setHostname(device_name);
		ArduinoOTA.begin();
	} else if (!connected && wasWifiConnected) {
		wifiReconnects++;
		disconnectedSince = now;
		snprintf(lastError, sizeof(lastError), "WiFi disconnected, status=%d", WiFi.status());
		addEvent(lastError);
	}
	wasWifiConnected = connected;

	if (wifiManager.getConfigPortalActive()) wifiManager.process();

	if (!connected) {
		if (disconnectedSince == 0) disconnectedSince = now;
		unsigned long retryInterval = wifiManager.getConfigPortalActive()
			? PORTAL_RETRY_INTERVAL : WIFI_RETRY_INTERVAL;
		if (now - lastWifiAttempt >= retryInterval) {
			lastWifiAttempt = now;
			WiFi.mode(wifiManager.getConfigPortalActive() ? WIFI_AP_STA : WIFI_STA);
			WiFi.begin();
			addEvent("WiFi reconnect requested");
		}
		if (now - disconnectedSince >= PORTAL_START_DELAY) startConfigPortal();
	} else if (wifiManager.getConfigPortalActive()
			&& now - wifiConnectedSince >= PORTAL_CLOSE_DELAY) {
		wifiManager.stopConfigPortal();
		WiFi.mode(WIFI_STA);
		addEvent("Config portal stopped");
	}
}

// ---- Setup ----
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
void loop() {
	ArduinoOTA.handle();
	processNetwork();
	updateStatusLed();

	unsigned long now = millis();
	if (!mqtt.connected()) {
		if (wasMqttConnected) {
			snprintf(lastError, sizeof(lastError), "MQTT disconnected, state=%d", mqtt.state());
			addEvent(lastError);
		}
		if (WiFi.status() == WL_CONNECTED
				&& now - lastMqttAttempt >= mqttRetryInterval) {
			lastMqttAttempt = now;
			mqttReconnect();
		}
	} else {
		if (!mqtt.loop()) {
			snprintf(lastError, sizeof(lastError), "MQTT loop failed, state=%d", mqtt.state());
			addEvent(lastError);
		}
		if ((stateSyncPending || discoveryPending)
				&& now - lastStateAttempt >= STATE_RETRY_INTERVAL) {
			lastStateAttempt = now;
			if (discoveryPending) publishDiscovery();
			if (stateSyncPending) publishAllStates();
		}
		if (now - lastDiagnostics >= DIAGNOSTICS_INTERVAL) {
			lastDiagnostics = now;
			publishDiagnostics();
		}
		publishEventLog();
	}
	wasMqttConnected = mqtt.connected();

	if (configSavedAt != 0 && now - configSavedAt >= 2000) {
		recordBootStage("config-restart");
		ESP.restart();
	}

	for (int i = 1; i < 8; i++) {
		if ((ledStateCounter[i] > 20 && i != 7)
		 || (ledStateCounter[i] > 20  && i == 7 && !ledStates[7])
		 || (ledStateCounter[i] > 375 && i == 7 &&  ledStates[7])) {
			ledStates[i]       = !ledStates[i];
			ledStateCounter[i] = 0;
			publishState(i);
		}
	}
}

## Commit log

2017-12-28 Add last will, publish uptime, switch to QoS level 1
    - Fixes #1
2017-12-29 Support for maintenance led and button
    - Fixes #2
2022-08-12 Add fritzing documents
    [abzugshaube.fzz, frontpanel-abzugshaube.fzz]
2026-04-16 Port to PlatformIO v0.0.5: replace Homie with WiFiManager+PubSubClient, add HA MQTT discovery
    [main.cpp]
2026-04-16 v0.0.5: fan entity for HA discovery, disable ISR during OTA, fan presets 1-4
2026-04-16 v0.0.5: rename device to Abzugshaube, light entity for Haubenlicht
2026-07-14 v0.0.6: improve WiFi robustness for weak signal areas
    - Enable WiFi auto-reconnect
    - Set maximum TX power (20.5 dBm) for better range
    - Disable WiFi sleep modes (stable power supply assumed)
    - Add active WiFi monitoring (every 10s) with fallback reconnect
    - Only attempt MQTT when WiFi is connected
    Robust WiFi handling for shielded locations with stable power supply.
2026-09-08 Add KiCad hardware design for the hood control board
    80 x 55 mm two-layer board for PCBWay: ESP-12E (U1) taps the Gutmann
    Sombra RJ45 control cable via J1/J3, level shifting through U2 (4050)
    and U3 (74HCT08), 3.3 V from a TPS63802 buck-boost module (U4).
    Includes DESIGN.md with the full net list, part assignment and the open
    points, plus the plotted schematic and board previews.
    Placement is complete and DRC-clean; routing and the ground pour are
    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
    [hood-control.kicad_pcb, hood-control.kicad_sch]
2026-09-08 Add status LED on GPIO2 for boot and connection state
    The onboard blue LED of the ESP-12 was unused. It now blinks a pattern
    that tells the boot stage apart at a glance without a serial console:
    three blips at power-on, fast for WiFi association, medium for the MQTT
    connect, slow while the config portal is open, and a short heartbeat
    blip every three seconds once both are up.
    Non-blocking, driven from loop() via millis().
    [main.cpp]
2026-09-08 Fix reversed TXO/RXI in the J2 pinout table
    The connector table listed J2 as "DTR, TXO, RXI, VCC, n.c., GND", but
    the netlist has pin 2 on /ESP_TXD and pin 3 on /ESP_RXD. Seen from the
    FTDI adapter those are RXI and TXO respectively - the documented order
    was the wrong way round, the schematic was right.
2026-09-08 Connect U4 VIN to the 5V input rail
    The wire meant to feed the stepdown ran from (90.17, 92.71) diagonally
    to U4 pin 1, missing the PWR_FLAG node by 1.27 mm. The converter input
    was therefore on no net at all - ERC reported both "Pin not connected"
    and "Input Power pin not driven", and the board would have been
    fabricated with the 3.3 V supply dangling.
    Replaced by a horizontal wire with a junction on the flag node. /5V_IN
    now reads C5.1, C8.1, J6.1, TP3.1, U3.14, U4.1 and ERC is clean.
    [hood-control.kicad_sch]
2026-09-08 v0.0.8: status LED for boot and connection state
    Bumps FW_VERSION to 0.0.8 and records the GPIO2 status LED added in
    7f205c9 in the changelog.
2026-09-11 Platzierung fertig, vor dem Routen
    [hood-control.kicad_pcb, hood-control.kicad_sch]
2026-09-11 Route the board and add fabrication outputs
    The PCB is fully routed: 174 track segments and 6 vias on two layers, with a
    filled GND plane on B.Cu (3531 mm², one contiguous polygon). Every ground
    connection hangs on that plane except U1's SMD pad 15, which reaches it
    through two redundant vias.
    Signals stay on F.Cu wherever they can (133 of 174 segments) so the back side
    remains a solid reference; only unavoidable crossings dip to B.Cu.
    Power nets get their own netclass: 0.6 mm tracks and 0.8/0.4 mm vias, signals
    stay at 0.25 mm. The tightest copper clearance is 0.200 mm and the smallest
    drill 0.30 mm — inside PCBWay's 6/6 mil class, but 8/8 mil would no longer
    fit, so the order has to s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
    [hood-control-B_Cu.gbl, hood-control-B_Mask.gbs, hood-control-B_Silkscreen.gbo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]
2026-09-26 Rev 0.3: decouple U3 from the hood's key matrix, fix channel mapping
    Bring-up of the rev 0.2 boards showed that U3's push-pull outputs on the
    key lines cause boot loops and phantom key presses. D3/D4 now sit in
    series behind U3 (the board can only pull a line high, never hold it
    low) and R7/R8 keep U3's inputs low until the firmware runs.
    Firmware drives GPIO12/14 actively (LOW = release, HIGH = press) from
    the very start of setup(), and swaps the LED and button pins, which
    arrive the other way round than the perfboard firmware assumed.
    DESIGN.md documents the findings and corrects the old assumption that
    D1/D2 protected the key lines.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
    [hood-control.kicad_pcb, hood-control.kicad_sch]
2026-09-26 Regenerate schematic and board layout PDFs for rev 0.3
2026-09-26 Regenerate fabrication outputs for rev 0.3
    [hood-control-B_Cu.gbl, hood-control-B_Mask.gbs, hood-control-B_Silkscreen.gbo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]
2026-09-27 Add beginner-friendly explanation of how the circuit works
    docs/SCHALTUNG.md explains the hood's key/LED matrix, level shifting,
    power supply, boot strapping and the firmware timing, plus the lessons
    from bringing up rev 0.2/0.3.
2026-09-27 Remove obsolete files, bump firmware to 0.0.9, fix stale design notes
    - Drop the 2018 Homie firmware (hood.ino) and the Eclipse/Sloeber project
    files; the build is PlatformIO with src/main.cpp.
    - Drop kicad/board-placement.svg, a pre-routing snapshot superseded by
    board-layout.pdf.
    - Firmware 0.0.9 with a CHANGELOG entry for the rev 0.3 changes (active
    LOW release, early LOW in setup(), swapped LED and button pins).
    - DESIGN.md: U4 is the buck-boost module, sheet size A5 is 210 x 148 mm,
    U5 was never fitted, placement zones updated to rev 0.3.
    [main.cpp]
2026-09-27 Add the TPS63802 module 3D model
    The U4 footprint and the board reference
    ${KIPRJMOD}/3dmodels/TPS63802_Module_25.8x13.0mm.step, which was missing
    from the repo. Includes the FreeCAD source and the script that
    generates it.
    [TPS63802_Module_25.8x13.0mm.FCStd, TPS63802_Module_25.8x13.0mm.step]
2026-09-27 Fix HA discovery of ventilation fan state
    state_value_template returned "on"/"off", but Home Assistant compares the
    rendered value against payload_on/payload_off ("1"/"0"), so the fan entity
    was permanently "unknown". Return "1"/"0" instead, and map level 0 to the
    preset reset payload "None".
    [main.cpp]
2026-09-27 Update README for rev 0.3 and firmware 0.0.9
    Describe what the board does, link all docs, list project layout, build
    and flash commands, and the MQTT topics.
2026-09-27 Make the documentation bilingual (English + German)
    English is now the default (*.md), German lives next to it (*.de.md),
    with a language switch at the top of each file. docs/SCHALTUNG.md becomes
    docs/CIRCUIT.md (English) / docs/CIRCUIT.de.md (German). The project is
    renamed to gutmann-sombra-mqtt in the READMEs.
    Along the way, DESIGN fixes: the channel-mapping note no longer splits
    the GPIO table, the check results reflect rev. 0.3, and the stale
    pre-routing position list is gone.
2026-09-28 Switch firmware to MIT and remove personal defaults
    Replace the hard-coded hotspot password and private MQTT host with
    neutral defaults that can be overridden via build_flags.
    Claude-Session: https://claude.ai/code/session_019t2dYQmRQivm83WUNV3cew
    [main.cpp]
